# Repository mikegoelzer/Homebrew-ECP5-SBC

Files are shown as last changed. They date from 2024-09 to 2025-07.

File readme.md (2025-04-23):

# Homebrew RISC-V Computer

This is the hardware repo for a homebrew "personal computer" designed from scratch down to the logic gate level.

The computer is based on [my custom RISC-V CPU core](https://github.com/mikegoelzer/riscv) (pipelined, in-order, 5-stage) and has all the common peripherals you'd expect on a PC circa the early-2000s like USB, HDMI, keyboard and mouse, etc.

This repo is focused specifically on the PCBs necessary to build the complete computer.

## Hardware

In this repo, you'll find all the Kicad files and bills of materials needed to construct the entire computer.  There are several PCBs:

- [Compute Module](./hardware/cm/readme.md). This is the heart of the computer:  an FPGA that implements the RISC-V CPU and some SDRAM that serves as the computer's main memory. It has two 100-pin Hirose DF13 snap-in connectors on the bottom, which mate with the motherboard.
- [Motherboard](./hardware/motherboard/readme.md). The Compute Module snaps into this motherboard, which breaks out the common PC periperal interfaces, like HDMI, VGA, JTAG, and more.  It also has an SD card to serve as the computer's "hard drive," a boot flash, and some diagnostic LEDs and switches.
- [Power Supply](./hardware/pd-booster-16amps/readme.md). Power initially comes into the motherboard via a USB-C cable.  Because I wanted to learn a bit about USB Power Deliver (USB-PD) as part of this project, I designed this plug-in board that negotiates higher voltages and currents and then buck-boost converts them to a stable 5V to power the motherboard.
- [Hat](./hardware/hat/readme.md).  This is a top board that sits above the motherboard on standoffs and provides a touch screen plus a smaller OLED display for debugging your Verilog.  The name is, of course, inspired by the Pi HAT, though it bears no electrical or mechanical resemblance.

## About this project

This project was a personal hobby exercise that I pursued on and off over a couple of years.  Everything is massively over-engineered because I was trying to maximize my learnings. 🤷‍♀️

## Acknowledgements

This hardware was heavily inspired by the [ULX3S](https://radiona.org/ulx3s/), which I consider the best low-cost Lattice ECP5 FPGA board ever created.

I also borrowed ideas from several other open-source ECP5 designs:

- [Lattice ECP5 Eval Board](https://www.latticesemi.com/products/developmentboardsandkits/ecp5evaluationboard)
- [Trellis Board](https://github.com/gatecat/TrellisBoard).  Not sure if this was ever sold to the public, but this guy's design is utterly brilliant.
- [Orange Crab](https://github.com/orangecrab-fpga/orangecrab-hardware)

## License

This material is licensed under `CERN-OHL-S v2` (or later), a strong "copyleft" license. If you require more permissive terms or patent protection, please contact the author. A copy of the license can be found in the [LICENSES](./LICENSES) directory.

Copyright © 2025 Mike Goelzer <mike@goelzer.org>

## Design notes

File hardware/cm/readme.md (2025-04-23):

# Compute Module

The Compute Module (CM) is the heart of the computer.  It has the two things that every computer needs:  a processor and memory.  

### Features

- ECP5U 85K FPGA
- 1.1V, 2.5V and 3.3V buck regulators for the FPGA's voltage rails
- Supply sequencer to bring voltage rails up and down "correctly" (see below)
- 16MB DRAM
- 25MHz oscillator
- Bitstream SPI flash chip
- 100-pin Hirose DF13 snap-in connectors on the bottom

### Power

The Compute Module is powered by a 5V input.  The 1.1V and 2.5V and 3.3V rails are produced by three TI buck regulators.

The ECP5 should not require a rail sequencer, but I included one (based on a design borrowed from Trellis Board) because I've seen other ECP5 boards get into weird states that seem like they may be caused by rail ramp rate problems.  Thus, the rail sequencing complies strictly with the ECP5's datasheet, at a cost of two extra chips.

### Electrical and Mechanical Connections

The basic idea with the CM is that you use it by snapping it into some larger board -- in my case, the [the motherboard](../motherboard/readme.md) in this repo.  This is the purpose of the two 100-pin Hirose DF13 male connectors on the bottom of the CM.  Everything, even power andJTAG, is brought out solely through these connectors.

The connectors and overall size and shape were inspired by the Raspberry Pi Compute Module 3 (CM3).  I wasn't able to maintain the same pinout as the Pi CM3 because I needed to bring out more IOs and wanted to run off a 5V input.

### Clock Speed

The FPGA includes several PLLs, so the 25 MHz oscillator in this circuit enables the CPU to run at 100 MHz.  

While the CPU itself would probably run fine at higher clock speeds, the DRAM is rated for a maximum speed of 133 MHz.  The memory controller is simplified considerably when you can get results back from DRAM in one clock cycle, so I just run everything in a single 100 MHz clock domain.

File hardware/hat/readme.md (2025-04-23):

# Hat

This is the top board that sits above the motherboard on standoffs and provides a touch screen plus a smaller OLED display for debugging the CPU's Verilog.

## OLED

The OLED is an 0.95" (96x64) SSD1331 display.  It is controlled via SPI entirely in Verilog.  I use it for very low-level debugging of the CPU itself, e.g., to display a register value or dump the contents of memory.

## Touch Screen

The touch screen is [this cool 2.8" 240x320 TFT LCD from Adafruit](https://www.adafruit.com/product/2090).  It is intended to be under software control rather than at the Verilog level.

## Power

Power is provided by the flat-flexible cable coming from the motherboard.  It is the same 5V supply as the motherboard itself.

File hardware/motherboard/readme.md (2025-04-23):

# Motherboard

This is the motherboard of the computer.  The Compute Module snaps into it to provide the computer's CPU and memory.  The motherboard then provides:

- HDMI
- VGA
- JTAG
- USB debug interface
- PMOD connectors
- Expansion slots for custom PCBs
- FFC connector to connect to the hat board that provides the touch screen
- SD card slot for the computer's "hard drive"
- Boot flash for the FPGA
- 5V power input
- Diagnostic LEDs and switches
- 100-pin Hirose female connectors for the Compute Module to snap into

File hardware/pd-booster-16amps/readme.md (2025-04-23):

# PD Booster (16 amps)

This is a USB-PD power supply that can deliver up to 16 amps at 5V.  It consists of two PCBs, which plug into each other:  a USB-PD controller and a buck-boost converter.

## Theory of Operation

USB-PD is mainly for battery charging, and the idea is that you have a USB-C cable coming into your device from a charger.  The charger initially supplies the standard 5V/2.5A, but you can negotiate over the CC lines side-channel to request both higher current and higher voltages (up to 20V).

Since you don't know in advance what voltage you will get, you need some additional circuitry to step down the voltage whatever you actually want to run at.  In my case, that's 5V.  The buck-boost converter is that additional circuitry:  it will maintain 5V output over the entire range of input voltages from 5V to as high as 20V.

## USB-PD Controller

The first PCB is the USB-PD controller, which is based on [TI TPS25730](https://www.ti.com/lit/ds/symlink/tps25730.pdf?ts=1707773923998&ref_url=https%253A%252F%252Fwww.mouser.at%252F).  It is resistor-strapped to request the highest voltage and current it can get (which would be 20V/5A), but will accept voltages as low as 5V.

## Buck-Boost Converter

The second PCB is the buck-boost converter.  It accepts whatever voltage the USB-PD controller was able to negotiate and regulates it to 5V.

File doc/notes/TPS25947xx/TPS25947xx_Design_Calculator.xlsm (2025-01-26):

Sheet: Calculation Sheet
TPS25947xx Design Calculation Tool
 |  |  |  |  |  |  |  |  |  | Table - 1: Device Comparison Table
 | Constants Cells |  |  |  |  |  |  |  |  | Part number | Overvoltage Response | Overcurrent response | AUXOFF or PG | FLT or PGTH | Response to Thermal Shutdown (TSD) |  | 3.8 | 5.7 | 13.8
 | Input/SelectCells |  |  |  |  |  |  |  |  | TPS259470A | Adjustable OVLO | Active Current Limit | AUXOFF | FLT | Auto-Retry |  | Short | Open | 390
 | Calculation Cells |  |  |  |  |  |  |  |  | TPS259470L | Adjustable OVLO | Active Current Limit | AUXOFF | FLT | Latch-off
 | Calculated, but can be over-ridden by user |  |  |  |  |  |  |  |  | TPS259472A | Pin Selectable OVC (3.8 V/5.7 V/13.8 V) | Active Current Limit | PG | PGTH | Auto-Retry
 | Error Cells, Must be Fixed |  |  |  |  |  |  |  |  | TPS259472L | Pin Selectable OVC(3.8 V/5.7 V/13.8 V) | Active Current Limit | PG | PGTH | Latch-off
 |  |  |  |  |  |  |  |  |  | TPS259474A | Adjustable OVLO | Circuit Breaker | PG | PGTH | Auto-retry
Parameter | Description | Value | Units | Tolerance | Recommended Value |  |  |  |  | TPS259474L | Adjustable OVLO | Circuit Breaker | PG | PGTH | Latch-off
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

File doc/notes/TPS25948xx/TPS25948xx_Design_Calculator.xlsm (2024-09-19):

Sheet: Calculation Sheet
TPS25948xx Design Calculation Tool
 | Constants Cells
 | Input/SelectCells
 | Calculation Cells
 | Calculated, but can be over-ridden by user
 | Error Cells, Must be Fixed
Parameter | Description | Value | Units | Tolerance | Recommended Value
VIN (max) | Maximum Operating input voltage (magnitude) | 12.00 | V
OVLO Set Point | Desired Over Voltage Lockout Set Point | 16.00 | V | 3.0%
UVLO Set Point | Desired Undervoltage Threshold (VIN Rising) | 10.80 | V | 3.0%
VUVP | Internal Undervoltage Protection Threshold (VIN Rising) | 2.53 | V | 3.0%
Cout | Load Capacitance | 220.0 | uF | 10.0%
 | Is there downstream load present other than load cap at startup? | YES
VONTH (CR) (V) | constant resistance load turn on threshold voltage | 0.0 | V
RLOAD (STARTUP) (Ω) | CR load at startup | 2.0 | Ohm
VONTH (CC) (V) | constant current load turn on threshold voltage | 3.0 | V
ILOAD (STARTUP) (A) | CC load at startup | 0.0 | A
VONTH (CP) (V) | constant power load turn on threshold voltage | 8.0 | V
PLOAD (STARTUP) (W) | CP load at startup | 0.0 | W
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

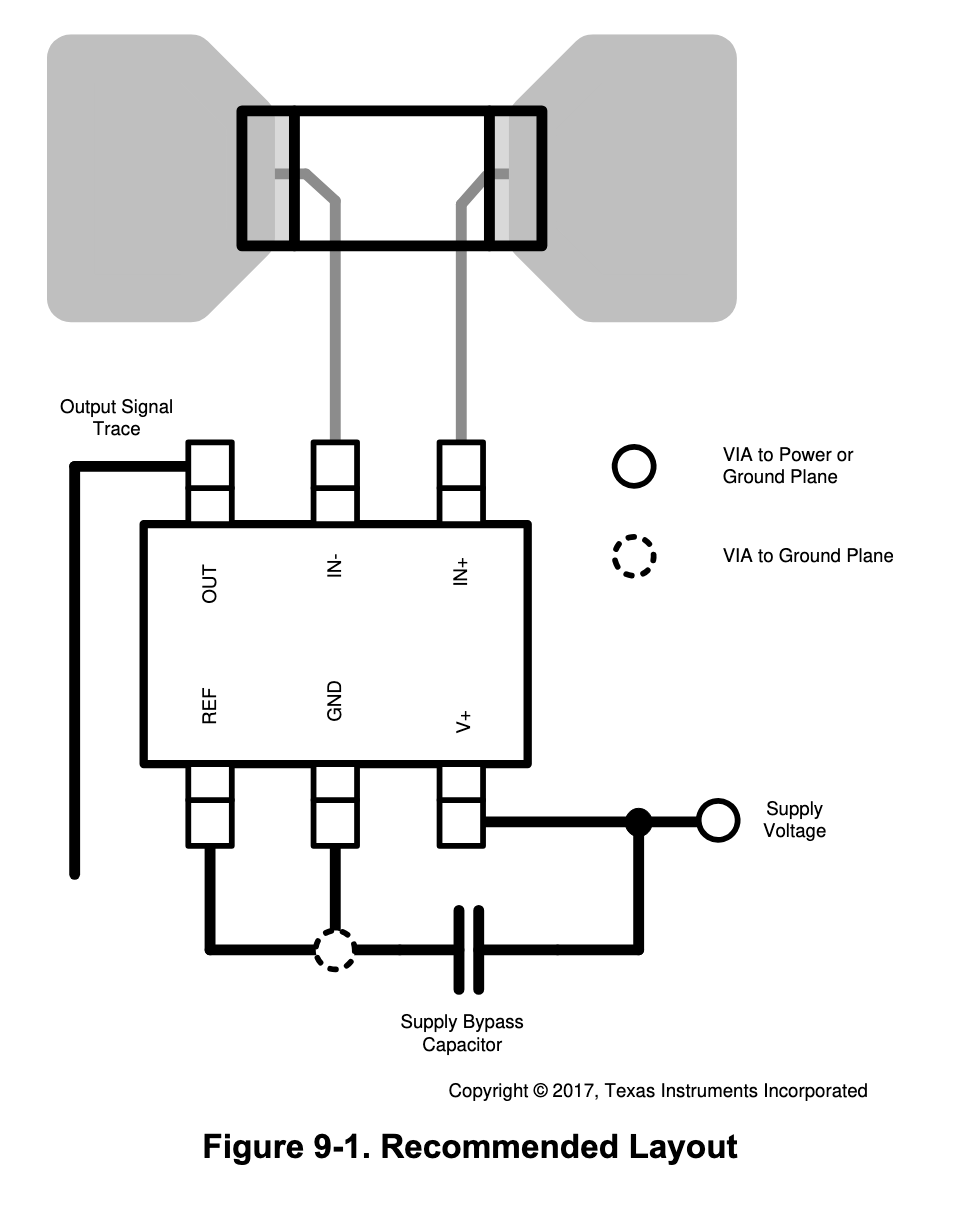
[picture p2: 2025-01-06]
doc/notes/INA211-layout-example.png

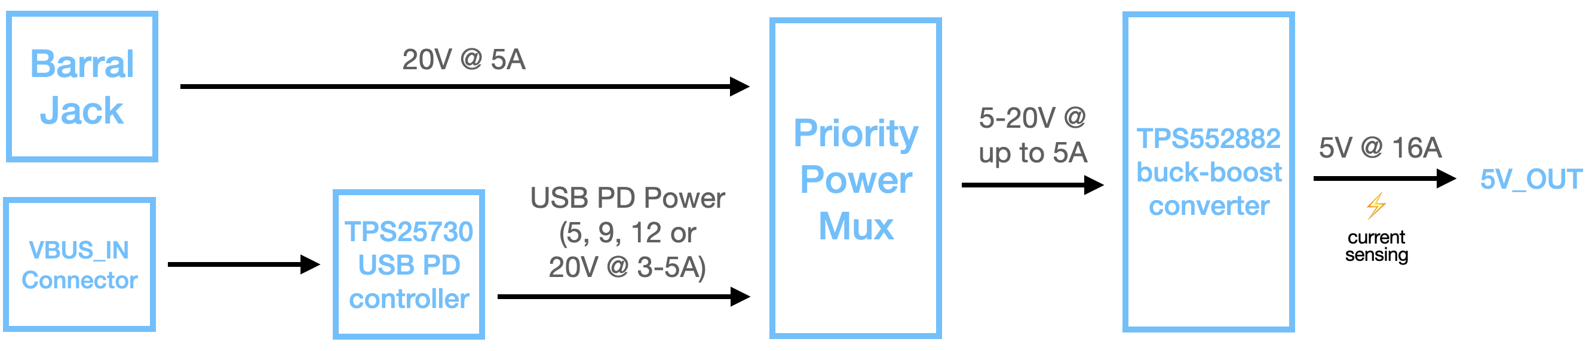
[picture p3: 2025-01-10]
doc/pd-booster-16A_block_diagram.png

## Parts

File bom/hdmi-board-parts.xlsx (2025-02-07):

Desc | Parts | Actual Qty | Order Qty | (Override Qty) | Order Qtr | Price | Subtotal | In basket? | Vendor URL | Mfgr | MPN | Notes
Motherboard for CM Rev 1
# of boards | 2
FT4232H LFQP-64 | U1 | 1 | 2 |  | 2 | $6.35 | $12.70 | ✅ | https://www.digikey.com/en/products/detail/ftdi-future-technology-devices-international-ltd/FT4232HL-REEL/1986055 | FTDI | FT4232HL
EEPROM, 93LC56BT | U2 | 1 | 2 |  | 2 | $0.30 | $0.60 | ✅ | https://www.digikey.com/en/products/detail/microchip-technology/93LC56BT-I-OT/572825 | Microchip Technology | 93LC56BT-I/OT
USB-C receptacle thru-hole GCT USB4105-GF-A-120 | J1 | 1 | 2 |  | 2 | 0.78 | $1.56 | ✅ | https://www.digikey.com/en/products/detail/gct/USB4105-GF-A-120/14559037 | GCT | USB4105-GF-A-120
RES 100 OHM 1% 1/8W 0805 | R30,R31 | 2 | 4 |  | 4 | 0.10 | $0.40 | ✅ | https://www.digikey.com/en/products/detail/yageo/RC0805FR-07100RL/727543 | YAGEO | RC0805FR-07100RL
RES 270 OHM 1% 1/8W 0805 | R32,R33,R34,R35,R36,R37,R38,R39,R40,R51 | 10 | 20 |  | 20 | 0.10 | $2.00 | ✅ | https://www.digikey.com/en/products/detail/yageo/rc0805fr-07270rl/727783 | YAGEO | RC0805FR-07270RL
RES 510 OHM 1% 1/8W 0805 | R55 | 1 | 2 |  | 2 | 0.10 | $0.20 | ✅ | https://www.digikey.com/en/products/detail/yageo/RC0805FR-07510RL/728016 | YAGEO | RC0805FR-07510RL
RES 536 OHM 1% 1/8W 0805 | R15,R16,R17,R18,R19,R20,R21,R22,R23,R24,R25,R26,R27,R28,R29,R42,R44,R50,R52 | 19 | 38 |  | 38 | 0.10 | $3.80 | ✅ | https://www.digikey.com/en/products/detail/yageo/rc0805fr-07536rl/728026 | YAGEO | RC0805FR-07536RL
RES 1K OHM 1% 1/8W 0805 | R43,R56,R57,R60,R63,R64 | 6 | 12 |  | 12 | 0.10 | $1.20 | ✅ | https://www.digikey.com/en/products/detail/yageo/RC0805FR-071KL/727444 | YAGEO | RC0805FR-071KL
RES 3.3K OHM 1% 1/8W 0805 | R53,R54,R58,R59 | 4 | 8 |  | 8 | 0.10 | $0.80 | ✅ | https://www.digikey.com/en/products/detail/yageo/rc0805fr-073k3l/727813 | YAGEO | RC0805FR-073K3L
RES 4.7K OHM 1% 1/8W 0805 |  |  | 0 |  |  | 0.01 | $0.00 |  | https://www.digikey.com/en/products/detail/yageo/rc0805fr-074k7l/727929 | YAGEO | RC0805FR-074K7L
RES 5.1K OHM 1% 1/8W 0805 |  |  | 0 |  |  | 0.10 | $0.00 |  | https://www.digikey.com/en/products/detail/yageo/rc0805fr-075k1l/727988 | YAGEO | RC0805FR-075K1L
RES 2.2K OHM 1% 1/8W 0805 | R45,R48,R49,R46,R68 | 5 | 10 |  | 10 | 0.01 | $0.13 | ✅ | https://www.digikey.com/en/products/detail/yageo/RC0805FR-072K2L/727676 | YAGEO | RC0805FR-072K2L
RES 10K OHM 1% 1/8W 0805 | R61,R62,R66,R67,R69 | 5 | 10 |  | 10 | 0.10 | $1.00 | ✅ | https://www.digikey.com/en/products/detail/yageo/RC0805FR-0710KL/727535 | YAGEO | RC0805FR-0710KL
RES 12K OHM 1% 1/8W 0805 | R65 | 1 | 2 |  | 2 | 0.10 | $0.20 | ✅ | https://www.digikey.com/en/products/detail/yageo/RC0805FR-0712KL/727568 | YAGEO | RC0805FR-0712KL
RES 33K OHM 1% 1/8W 0805 |  |  | 0 |  |  | 0.10 | $0.00 |  | https://www.digikey.com/en/products/detail/yageo/RC0805FR-0733KL/727863 | YAGEO | RC0805FR-0733KL
RES 100K OHM 1% 1/8W 0805 | R1,R2,R3,R4,R5,R6,R7,R8,R9,R10,R11,R12,R13,R14 | 14 | 28 |  | 28 | 0.10 | $2.80 | ✅ | https://www.digikey.com/en/products/detail/yageo/RC0805FR-07100KL/727544 | YAGEO | RC0805FR-07100KL
RES 200K OHM 1% 1/8W 0805 | R47 | 1 | 2 |  | 2 | 0.10 | $0.20 | ✅ | https://www.digikey.com/en/products/detail/yageo/rc0805fr-07200kl/727724 | YAGEO | RC0805FR-07200KL
RES 1M OHM 1% 1/8W 0805 | R41 | 1 | 2 |  | 2 | 0.10 | $0.20 | ✅ | https://www.digikey.com/en/products/detail/yageo/rc0805fr-071ml/727445 | YAGEO | RC0805FR-071ML
Ferrite bead 600 ohms @100mhz 0603 0.6A | FB2,FB3 | 2 | 4 |  | 4 | 0.16 | $0.64 | ✅ | https://www.digikey.com/en/products/detail/murata-electronics/BLM21AG601SN1D/584251 | Murata | BLM21AG601SN1D
FERRITE BEAD 50 OHM @ 100MHZ 1206 1LN 12 AMP 1.6mΩ DCR | FB1 | 1 | 2 |  | 2 | 0.42 | $0.84 | ✅ | https://www.digikey.com/en/products/detail/murata-electronics/BLM31SN500SZ1L/5881255 | Murata | BLM31SN500SZ1L
FERRITE BEAD 600 OHM 0603 1LN | FB4,FB5,FB6 | 3 | 6 |  | 6 | 0.10 | $0.60 | ✅ | https://www.digikey.com/en/products/detail/murata-electronics/blm18rk601sn1d/1948332 | Murata | BLM18RK601SN1D
CAP CER 100PF 50V X7R 0805 | C9 | 1 | 2 |  | 2 | 0.10 | $0.20 | ✅ | https://www.digikey.com/en/products/detail/yageo/CC0805KRX7R9BB101/5884228 | YAGEO | CC0805KRX7R9BB101
CAP CER 1000PF (1 nF) 50V X7R 0805 | C3,C5 | 2 | 4 |  | 4 | 0.10 | $0.40 | ✅ | https://www.digikey.com/en/products/detail/yageo/CC0805KRX7R9BB102/302861 | YAGEO | CC0805KRX7R9BB102
CAP CER 10000PF (10 nF) 50V X7R 0805 | C34,C35,C36,C37,C38,C39,C40,C41 | 8 | 16 |  | 16 | 0.10 | $1.60 | ✅ | https://www.digikey.com/en/products/detail/yageo/CC0805KRX7R9BB103/302870 | YAGEO | CC0805KRX7R9BB103
CAP CER 0.1UF (100 nF) 50V X7R 0805 | C4,C6,C8,C10,C18,C19,C20,C21,C22,C23,C24,C14,C15,C16 | 14 | 28 |  | 28 | 0.08 | $2.24 | ✅ | https://www.digikey.com/en/products/detail/yageo/CC0805KRX7R9BB104/302874 | YAGEO | CC0805KRX7R9BB104
CAP CER 0.47UF (470nF) 25V X7R 0805 | C11 | 1 | 2 |  | 2 | 0.18 | $0.36 | ✅ | https://www.digikey.com/en/products/detail/yageo/CC0805KKX7R8BB474/2103102 | YAGEO | CC0805KKX7R8BB474
CAP CER 4.7UF 25V X5R 0805 |  |  | 0 |  |  | 0.18 | $0.00 |  | https://www.digikey.com/en/products/detail/yageo/CC0805KKX5R8BB475/5195277 | YAGEO | CC0805KKX5R8BB475
CAP CER 4.7UF 35V X5R 0805 | C12,C13 | 2 | 4 |  | 4 | 0.17 | $0.68 | ✅ | https://www.digikey.com/en/products/detail/samsung-electro-mechanics/CL21A475KLCLQNC/5961206 | Samsung | CL21A475KLCLQNC
CAP CER 10UF 25V X5R 0805 | C31,C32,C33,C17,C25,C26 | 6 | 12 |  | 12 | 0.33 | $3.96 | ✅ | https://www.digikey.com/en/products/detail/yageo/CC0805KKX5R8BB106/5195275 | YAGEO | CC0805KKX5R8BB106
CAP CER 22UF 35V X5R 0805 | C1,C2 | 2 | 4 |  | 4 | $0.97 | $3.88 | ✅ | https://www.digikey.com/en/products/detail/tdk-corporation/C2012X5R1V226M125DC/22106206 | TDK Corporation | C2012X5R1V226M125DC
CAP CER 1000PF (1nF) 250V X7R 0805 | C7 | 1 | 2 |  | 2 | $0.10 | $0.20 | ✅ | https://www.digikey.com/en/products/detail/samsung-electro-mechanics/CL21B102KECSFNC/3888089 | Samsung | CL21B102KECSFNC
USBLC6-2SC6 TVS diode | D1 | 1 | 2 |  | 2 | 0.36 | $0.72 | ✅ | https://www.digikey.com/en/products/detail/stmicroelectronics/USBLC6-2SC6/1040559 | STMicroelectronics | USBLC6-2SC6
2x4 female 0.1" socket | J2 | 1 | 2 |  | 2 | 0.44 | $0.88 | ✅ | https://www.digikey.com/en/products/detail/adam-tech/RS2-08-G/9832057 | Adam Tech | RS2-08-G
TFP401 HDMI receiver |  |  | 0 |  |  | $8.26 | $0.00 |  | https://www.digikey.com/en/products/detail/texas-instruments/TFP401PZP/380153 | TI | TFP401PZP
TFP410 HDMI transmitter | U5 | 1 | 2 |  | 2 | $8.44 | $16.88 | ✅ | https://www.digikey.com/en/products/detail/texas-instruments/TFP410PAP/454241 | TI | TFP410PAP
CONN RCPT HDMI V2.1 19POS SMD RA | J4 | 1 | 2 |  | 2 | $2.14 | $4.28 | ✅ | https://www.digikey.com/en/products/detail/molex/2086581001/10493711 | Molex | 2086581001
D-SUB receptacle female pins | J5 | 1 | 2 |  | 2 | $1.45 | $2.90 | ✅ | https://www.digikey.com/en/products/detail/amphenol-cs-fci/ICD15S13E4GX00LF/1536501 | Amphenol | ICD15S13E4GX00LF
74LVC245 | U6,U7 | 2 | 4 |  | 4 | $0.53 | $2.12 | ✅ | https://www.digikey.com/en/products/detail/texas-instruments/SN74ALVC245PWR/381176 | TI | SN74ALVC245PWR
HDMI I2C level shifter PCA9306D in SO-8 | U9 | 1 | 2 |  | 2 | $0.74 | $1.48 | ✅ | https://www.digikey.com/en/products/detail/nxp-usa-inc/PCA9306D-118/1300968 | NXP USA Inc. | PCA9306D,118
Hirose DF40GB (with shield) 48-pin socket/receptacle/female, 3.0mm stack | XM1 | 1 | 2 |  | 2 | $1.20 | $2.40 | ✅ | https://www.digikey.com/en/products/detail/hirose-electric-co-ltd/DF40GB-3-0-48DS-0-4V-51/5052265 | Hirose | DF40GB(3.0)-48DS-0.4V(51)
Hirose DF40HC 40-pin socket/receptacle/female, 3.5mm stack | XM2 | 1 | 2 |  | 2 | $0.81 | $1.62 | ✅ | https://www.digikey.com/en/products/detail/hirose-electric-co-ltd/DF40HC-3-5-20DS-0-4V-51/5132167 | Hirose | DF40HC(3.5)-20DS-0.4V(51)
4 x M2.5x0.45 screws 10mm long | XM1,XM2 | 2 | 4 | 4 | 4 | $0.13 | $0.52 | ✅ | https://www.digikey.com/en/products/detail/essentra-components/50M025045P010/11639705 | Essentra | 50M025045P010 | Intended (10mm) screw for XM1 at Ux
8 x M2.5 washer, 1.5mm thick | XM1,XM2 | 2 | 4 | 8 | 8 | $0.10 | $0.80 | ✅ | https://www.digikey.com/en/products/detail/essentra-components/015102500203/4104105 | Essentra | 015102500203 | Double them up on each hole for 3mm standoff height
2 x Hirose DF40 (w/o shield) 100-pin socket/receptacle/female, 1.5mm stack | U3 | 1 | 2 | 6 | 6 | $1.76 | $10.56 | ✅ | https://www.digikey.com/en/products/detail/hirose-electric-co-ltd/df40c-100ds-0-4v-51/1969476 | Hirose | DF40C-100DS-0.4V(51)
4 x M2.5x0.45 screws 8.5mm long | U3 | 1 | 2 | 4 | 4 | $0.13 | $0.52 | ✅ | https://www.digikey.com/en/products/detail/essentra-components/50M025045I010/11641118 | Essentra | 50M025045I010 | Alternate (shorter, 8.5mm) screw for GCM at U3
4 x M2.5x0.45 screws 10mm long | U3 | 1 | 2 | 4 | 4 | $0.13 | $0.52 | ✅ | https://www.digikey.com/en/products/detail/essentra-components/50M025045P010/11639705 | Essentra | 50M025045P010 | Intended (10mm) screw for GCM at U3
4 x M2 washer, 1.5mm thick | U3 | 1 | 2 | 4 | 4 | $0.30 | $1.20 | ✅ | https://www.digikey.com/en/products/detail/essentra-components/rwm050a/4105754 | Essentra | RWM050A | Alternate (M2) washer for GCM at U3
4 x M2.5 washer, 1.5mm thick | U3 | 1 | 2 | 4 | 4 | $0.10 | $0.40 | ✅ | https://www.digikey.com/en/products/detail/essentra-components/015102500203/4104105 | Essentra | 015102500203 | Intended (M2.5) washer for GCM at U3
4 x M2.5 nut | U3,XM1,XM2 | 3 | 6 | 12 | 12 | $0.13 | $1.56 | ✅ | https://www.digikey.com/en/products/detail/essentra-components/04M025045HN/9677099 | Essentra | 04M025045HN | Covers just U3 (4 nuts) and XM1 (4 nuts)
4 x M3 standoffs, 80mm | (top PCB attachment) | 1 | 2 | 4 | 4 | $1.41 | $5.64 | ✅ | https://www.digikey.com/en/products/detail/w%C3%BCrth-elektronik/970800321/6174900 | Wurth | 970800321
8 x M3 screws (4 x from top, 4x from bottom) | (top PCB attachment) | 1 | 2 | 8 | 8 | $0.24 | $1.92 | ✅ | https://www.digikey.com/en/products/detail/w%C3%BCrth-elektronik/97790603111/10056387 | Wurth | 97790603111
FFC connector (Hirose FH12 vertical 32-pos for 0.3mm thick) | J3 | 1 | 2 |  | 2 | $2.14 | $4.28 | ✅ | https://www.digikey.com/en/products/detail/hirose-electric-co-ltd/FH12-32S-0-5SVA-54/4283323 | Hirose | FH12-32S-0.5SVA(54)
32 Position FFC, FPC Cable 0.020" (0.50mm) 5.000" (127.00mm) 0.3mm thick | J3 | 1 | 2 | 1 | 1 | $4.00 | $4.00 | ✅ | https://www.digikey.com/en/products/detail/molex/0982660346/3469471 | Molex | 0982660346
5.1k through-hole resistor (for backup at J2) | J2 | 1 | 2 | 2 | 2 | $0.10 | $0.20 | ✅ | https://www.digikey.com/en/products/detail/stackpole-electronics-inc/CF14JT5K10/1741447 | Stackpole | CF14JT5K10 | Backup in case pd-booster null board not available; short b/t CC1 & GND and CC2 & GND
CONN HEADER R/A 2x6 2.54MM | J7 | 1 | 2 |  | 2 | $0.27 | $0.54 | ✅ | https://www.digikey.com/en/products/detail/adam-tech/PH2RA-12-UA/9830569 | Adam Tech | PH2RA-12-UA
CONN HEADER R/A 1x6 2.54MM | J6 | 1 | 2 |  | 2 | $0.16 | $0.32 | ✅ | https://www.digikey.com/en/products/detail/adam-tech/ph1rb-06-ua/9830592 | Adam Tech | PH1RB-06-UA
Tactile momentary push button C&K PTS645 | S1,S2,S3,S4 | 4 | 8 | 12 | 12 | $0.40 | $4.80 | ✅ | https://www.digikey.com/en/products/detail/c-k/PTS645SL50SMTR92-LFS/1279107 | C&K | PTS645SL50SMTR92LFS
Green LED 0805 | D2,D8,D10 | 3 | 6 |  | 6 | $0.17 | $1.02 | ✅ | https://www.digikey.com/en/products/detail/w%C3%BCrth-elektronik/150080VS75000/4489924 | Wurth | 150080VS75000
Amber LED 0805 | D6 | 1 | 2 |  | 2 | $0.22 | $0.44 | ✅ | https://www.digikey.com/en/products/detail/w%C3%BCrth-elektronik/150080AS75000/11479384 | Wurth | 150080AS75000
Red LED 0805 | D4 | 1 | 2 |  | 2 | $0.17 | $0.34 | ✅ | https://www.digikey.com/en/products/detail/w%C3%BCrth-elektronik/150080SS75000/4489921 | Wurth | 150080SS75000
Blue LED 0805 | D5 | 1 | 2 |  | 2 | $0.17 | $0.34 | ✅ | https://www.digikey.com/en/products/detail/w%C3%BCrth-elektronik/150080BS75000/4489912 | Wurth | 150080BS75000
Yellow LED 0805 | D3,D9 | 2 | 4 |  | 4 | $0.17 | $0.68 | ✅ | https://www.digikey.com/en/products/detail/w%C3%BCrth-elektronik/150080YS75000/4489927 | Wurth | 150080YS75000
White LED 0805 (Vf 3.1V at 5ma; use 68.1Ω resistor for 3.3V supply) | D7 | 1 | 2 |  | 2 | $0.43 | $0.86 | ✅ | https://www.digikey.com/en/products/detail/qt-brightek-qtb/QBLP631-IW5/16499651 | QT Brightek | QBLP631-IW5
TMUX1574PWR | U8,U10 | 2 | 4 |  | 4 | $0.54 | $2.16 | ✅ | https://www.digikey.com/en/products/detail/texas-instruments/TMUX1574PWR/9954224 | TI | TMUX1574PWR
128Mb QSPI serial flash | U4 | 1 | 2 |  | 2 | $0.00 | $0.00 | ✅ | https://www.digikey.com/en/products/detail/winbond-electronics/w25q128jvsiq/5803943 | Winbond | W25Q128JVSIQ
12mhz oscillator | Y1 | 1 | 2 |  | 2 | $2.38 | $4.76 | ✅ | https://www.digikey.com/en/products/detail/abracon-llc/ASEM1-12-000MHZ-LC-T/1873203 | Abracon | ASEM1-12.000MHZ-LC-T
0.1" male pins, straight, 2x2 |  |  | 0 |  |  | $0.10 | $0.00 |  | https://www.digikey.com/en/products/detail/adam-tech/PH2-04-UA/9830324 | Adam Tech | PH2-04-UA
0.1" male pins, straight, 2x3 | J8 | 1 | 2 |  | 2 | $0.10 | $0.20 | ✅ | https://www.digikey.com/en/products/detail/adam-tech/PH2-06-UA/9830396 | Adam Tech | PH2-06-UA
0.1" male pins, straight, 1x3 | J9 | 1 | 2 |  | 2 | $0.10 | $0.20 | ✅ | https://www.digikey.com/en/products/detail/adam-tech/PH1-03-UA/9830289 | Adam Tech | PH1-03-UA
Keystone Testpoint (red) |  |  | 0 |  |  | $0.41 | $0.00 |  | https://www.digikey.com/en/products/detail/keystone-electronics/5000/255326 | Keystone | 5000
Keystone Testpoint (black) |  |  | 0 |  |  | $0.41 | $0.00 |  | https://www.digikey.com/en/products/detail/keystone-electronics/5001/255327 | Keystone | 5001
Keystone Testpoint (while) |  |  | 0 |  |  | $0.41 | $0.00 |  | https://www.digikey.com/en/products/detail/keystone-electronics/5002/255328 | Keystone | 5002
Keystone Testpoint (orange) |  |  | 0 |  |  | $0.41 | $0.00 |  | https://www.digikey.com/en/products/detail/keystone-electronics/5003/362668 | Keystone | 5003
Keystone Testpoint (yellow) |  |  | 0 |  |  | $0.41 | $0.00 |  | https://www.digikey.com/en/products/detail/keystone-electronics/5004/362669 | Keystone | 5004
IC PWR SWITCH N-CHAN 1:1 SOT23-5 (current limiting load switch) in SOT-23-5 | U11 | 1 | 2 |  | 2 | $0.00 | $0.00 | ✅ | https://www.digikey.com/en/products/detail/texas-instruments/TPS2041BDBVR/1219920 | TI | TPS2041BDBVR
TVS diode TPD4E02B04 | U12, U13 | 2 | 4 |  | 4 | $0.00 | $0.00 | ✅ | https://www.digikey.com/en/products/detail/texas-instruments/TPD4E02B04DQAR/5880125 | TI | TPD4E02B04
xm-dvi-in Expansion Module
# of boards | 2
FT4232H LFQP-64 |  |  | 0 |  |  | $6.35 | $0.00 | ❌ | https://www.digikey.com/en/products/detail/ftdi-future-technology-devices-international-ltd/FT4232HL-REEL/1986055 | FTDI | FT4232HL
EEPROM, 93LC56BT |  |  | 0 |  |  | $0.30 | $0.00 | ❌ | https://www.digikey.com/en/products/detail/microchip-technology/93LC56BT-I-OT/572825 | Microchip Technology | 93LC56BT-I/OT
USB-C receptacle thru-hole GCT USB4105-GF-A-120 |  |  | 0 |  |  | 0.78 | $0.00 | ❌ | https://www.digikey.com/en/products/detail/gct/USB4105-GF-A-120/14559037 | GCT | USB4105-GF-A-120
RES 100 OHM 1% 1/8W 0805 |  |  | 0 |  |  | 0.10 | $0.00 | ❌ | https://www.digikey.com/en/products/detail/yageo/RC0805FR-07100RL/727543 | YAGEO | RC0805FR-07100RL
RES 270 OHM 1% 1/8W 0805 |  |  | 0 |  |  | 0.10 | $0.00 | ❌ | https://www.digikey.com/en/products/detail/yageo/rc0805fr-07270rl/727783 | YAGEO | RC0805FR-07270RL
RES 510 OHM 1% 1/8W 0805 |  |  | 0 |  |  | 0.10 | $0.00 | ❌ | https://www.digikey.com/en/products/detail/yageo/RC0805FR-07510RL/728016 | YAGEO | RC0805FR-07510RL
RES 536 OHM 1% 1/8W 0805 |  |  | 0 |  |  | 0.10 | $0.00 | ❌ | https://www.digikey.com/en/products/detail/yageo/rc0805fr-07536rl/728026 | YAGEO | RC0805FR-07536RL
RES 1K OHM 1% 1/8W 0805 |  |  | 0 |  |  | 0.10 | $0.00 | ❌ | https://www.digikey.com/en/products/detail/yageo/RC0805FR-071KL/727444 | YAGEO | RC0805FR-071KL
RES 4.7K OHM 1% 1/8W 0805 |  |  | 0 |  |  | 0.01 | $0.00 | ❌ | https://www.digikey.com/en/products/detail/yageo/rc0805fr-074k7l/727929 | YAGEO | RC0805FR-074K7L
RES 5.1K OHM 1% 1/8W 0805 |  |  | 0 |  |  | 0.10 | $0.00 | ❌ | https://www.digikey.com/en/products/detail/yageo/rc0805fr-075k1l/727988 | YAGEO | RC0805FR-075K1L
RES 2.2K OHM 1% 1/8W 0805 | R42,R43,R50,R51 | 4 | 8 |  | 8 | 0.01 | $0.11 | ❌ | https://www.digikey.com/en/products/detail/yageo/RC0805FR-072K2L/727676 | YAGEO | RC0805FR-072K2L
RES 10K OHM 1% 1/8W 0805 | R53 | 1 | 2 |  | 2 | 0.10 | $0.20 | ❌ | https://www.digikey.com/en/products/detail/yageo/RC0805FR-0710KL/727535 | YAGEO | RC0805FR-0710KL
RES 12K OHM 1% 1/8W 0805 |  |  | 0 |  |  | 0.10 | $0.00 | ❌ | https://www.digikey.com/en/products/detail/yageo/RC0805FR-0712KL/727568 | YAGEO | RC0805FR-0712KL
RES 33K OHM 1% 1/8W 0805 | R52,R54 | 2 | 4 |  | 4 | 0.10 | $0.40 | ❌ | https://www.digikey.com/en/products/detail/yageo/RC0805FR-0733KL/727863 | YAGEO | RC0805FR-0733KL
RES 100K OHM 1% 1/8W 0805 |  |  | 0 |  |  | 0.10 | $0.00 | ❌ | https://www.digikey.com/en/products/detail/yageo/RC0805FR-07100KL/727544 | YAGEO | RC0805FR-07100KL
RES 200K OHM 1% 1/8W 0805 | R44 | 1 | 2 |  | 2 | 0.10 | $0.20 | ❌ | https://www.digikey.com/en/products/detail/yageo/rc0805fr-07200kl/727724 | YAGEO | RC0805FR-07200KL
RES 1M OHM 1% 1/8W 0805 |  |  | 0 |  |  | 0.10 | $0.00 | ❌ | https://www.digikey.com/en/products/detail/yageo/rc0805fr-071ml/727445 | YAGEO | RC0805FR-071ML
Ferrite bead 600 ohms @100mhz 0603 0.6A |  |  | 0 |  |  | 0.16 | $0.00 | ❌ | https://www.digikey.com/en/products/detail/murata-electronics/BLM21AG601SN1D/584251 | Murata | BLM21AG601SN1D
FERRITE BEAD 50 OHM @ 100MHZ 1206 1LN 12 AMP 1.6mΩ DCR |  |  | 0 |  |  | 0.42 | $0.00 | ❌ | https://www.digikey.com/en/products/detail/murata-electronics/BLM31SN500SZ1L/5881255 | Murata | BLM31SN500SZ1L
FERRITE BEAD 600 OHM 0603 1LN | FB2,FB3,FB4,FB5 | 4 | 8 |  | 8 | 0.10 | $0.80 | ❌ | https://www.digikey.com/en/products/detail/murata-electronics/blm18rk601sn1d/1948332 | Murata | BLM18RK601SN1D
CAP CER 100PF 50V X7R 0805 | C8 | 1 | 2 |  | 2 | 0.10 | $0.20 | ❌ | https://www.digikey.com/en/products/detail/yageo/CC0805KRX7R9BB101/5884228 | YAGEO | CC0805KRX7R9BB101
CAP CER 1000PF (1 nF) 50V X7R 0805 |  |  | 0 |  |  | 0.10 | $0.00 | ❌ | https://www.digikey.com/en/products/detail/yageo/CC0805KRX7R9BB102/302861 | YAGEO | CC0805KRX7R9BB102
CAP CER 10000PF (10 nF) 50V X7R 0805 | C16,C17,C18,C19,C20,C21,C22,C23,C24,C25,C26,C27,C28,C29,C30 | 15 | 30 |  | 30 | 0.10 | $3.00 | ❌ | https://www.digikey.com/en/products/detail/yageo/CC0805KRX7R9BB103/302870 | YAGEO | CC0805KRX7R9BB103
CAP CER 0.1UF (100 nF) 50V X7R 0805 |  |  | 0 |  |  | 0.08 | $0.00 | ❌ | https://www.digikey.com/en/products/detail/yageo/CC0805KRX7R9BB104/302874 | YAGEO | CC0805KRX7R9BB104
CAP CER 0.47UF (470nF) 25V X7R 0805 | C10 | 1 | 2 |  | 2 | 0.18 | $0.36 | ❌ | https://www.digikey.com/en/products/detail/yageo/CC0805KKX7R8BB474/2103102 | YAGEO | CC0805KKX7R8BB474
CAP CER 4.7UF 25V X5R 0805 |  |  | 0 |  |  | 0.18 | $0.00 | ❌ | https://www.digikey.com/en/products/detail/yageo/CC0805KKX5R8BB475/5195277 | YAGEO | CC0805KKX5R8BB475
CAP CER 10UF 25V X5R 0805 | C12,C13,C14,C15 | 4 | 8 |  | 8 | 0.33 | $2.64 | ❌ | https://www.digikey.com/en/products/detail/yageo/CC0805KKX5R8BB106/5195275 | YAGEO | CC0805KKX5R8BB106
CAP CER 22UF 35V X5R 0805 |  |  | 0 |  |  | $0.97 | $0.00 | ❌ | https://www.digikey.com/en/products/detail/tdk-corporation/C2012X5R1V226M125DC/22106206 | TDK Corporation | C2012X5R1V226M125DC
CAP CER 1000PF (1nF) 250V X7R 0805 |  |  | 0 |  |  | $0.10 | $0.00 | ❌ | https://www.digikey.com/en/products/detail/samsung-electro-mechanics/CL21B102KECSFNC/3888089 | Samsung | CL21B102KECSFNC
USBLC6-2SC6 TVS diode |  |  | 0 |  |  | 0.36 | $0.00 | ❌ | https://www.digikey.com/en/products/detail/stmicroelectronics/USBLC6-2SC6/1040559 | STMicroelectronics | USBLC6-2SC6
2x4 female 0.1" socket |  |  | 0 |  |  | 0.44 | $0.00 | ❌ | https://www.digikey.com/en/products/detail/adam-tech/RS2-08-G/9832057 | Adam Tech | RS2-08-G
TFP401 HDMI receiver | U4 | 1 | 2 |  | 2 | $8.26 | $16.52 | ❌ | https://www.digikey.com/en/products/detail/texas-instruments/TFP401PZP/380153 | TI | TFP401PZP
TFP410 HDMI transmitter |  |  | 0 |  |  | $8.44 | $0.00 | ❌ | https://www.digikey.com/en/products/detail/texas-instruments/TFP410PAP/454241 | TI | TFP410PAP
CONN RCPT HDMI V2.1 19POS SMD RA | J3 | 1 | 2 |  | 2 | $2.14 | $4.28 | ❌ | https://www.digikey.com/en/products/detail/molex/2086581001/10493711 | Molex | 2086581001
D-SUB receptacle female pins |  |  | 0 |  |  | $1.45 | $0.00 | ❌ | https://www.digikey.com/en/products/detail/amphenol-cs-fci/ICD15S13E4GX00LF/1536501 | Amphenol | ICD15S13E4GX00LF
74LVC245 |  |  | 0 |  |  | $0.53 | $0.00 | ❌ | https://www.digikey.com/en/products/detail/texas-instruments/SN74ALVC245PWR/381176 | TI | SN74ALVC245PWR
HDMI I2C level shifter PCA9306D in SO-8 | U8 | 1 | 2 |  | 2 | $0.74 | $1.48 | ❌ | https://www.digikey.com/en/products/detail/nxp-usa-inc/PCA9306D-118/1300968 | NXP USA Inc. | PCA9306D,118
Hirose DF40GB (with shield) 48-pin plug/male | J1 | 1 | 2 |  | 2 | $1.26 | $2.52 | ❌ | https://www.digikey.com/en/products/detail/hirose-electric-co-ltd/DF40GB-48DP-0-4V-51/5052268 | Hirose | DF40GB-48DP-0.4V(51)
 |  |  | 0 |  |  | $0.00 | $0.00 | ❌
 |  |  | 0 |  |  | $0.00 | $0.00 | ❌
 |  |  | 0 |  |  | $0.00 | $0.00 | ❌
 |  |  | 0 |  |  | $0.00 | $0.00 | ❌
 |  |  | 0 |  |  | $0.00 | $0.00 | ❌
 |  |  | 0 |  |  | $0.00 | $0.00 | ❌
 |  |  | 0 |  |  | $0.00 | $0.00 | ❌
 |  |  | 0 |  |  | $0.00 | $0.00 | ❌
 |  |  | 0 |  |  | $0.00 | $0.00 | ❌
 |  |  | 0 |  |  | $0.00 | $0.00 | ❌
 |  |  | 0 |  |  | $0.00 | $0.00 | ❌
 |  |  | 0 |  |  | $0.00 | $0.00 | ❌
 |  |  | 0 |  |  | $0.00 | $0.00 | ❌
 |  |  | 0 |  |  | $0.00 | $0.00 | ❌
 |  |  | 0 |  |  | $0.00 | $0.00 | ❌
 |  |  | 0 |  |  | $0.00 | $0.00 | ❌
 |  |  | 0 |  |  | $0.00 | $0.00 | ❌
pd-booster-null Current (Non-)Booster Board Rev 1
# of boards | 2
IC CURR SENSE 1 CIRCUIT SC70-6 | U1 | 1 | 2 |  | 2 | 1.46 | $2.92 | ✅ | https://www.digikey.com/en/products/detail/texas-instruments/INA211BIDCKT/3675147 | TI | INA211BIDCKT
Shunt resistor 0.002 OHM 1% 1W 1206 | R3 | 1 | 2 |  | 2 | 0.96 | $1.92 | ✅ | https://www.digikey.com/en/products/detail/stackpole-electronics-inc/CSNL1206FT2L00/1788091 | Stackpole Electronics Inc | CSNL1206FT2L00
RES 5.1K OHM 1% 1/8W 0805 | R1,R2 | 2 | 4 |  | 4 | 0.10 | $0.40 | ✅ | https://www.digikey.com/en/products/detail/yageo/rc0805fr-075k1l/727988 | YAGEO | RC0805FR-075K1L
CAP CER 0.1UF 50V X7R 0805 | C1 | 1 | 2 |  | 2 | 0.08 | $0.16 | ✅ | https://www.digikey.com/en/products/detail/yageo/CC0805KRX7R9BB104/302874 | YAGEO | CC0805KRX7R9BB104
2x4 male pin header 0.1" right angle | J1 | 1 | 2 |  | 2 | 0.08 | $0.16 | ✅ | https://www.digikey.com/en/products/detail/adam-tech/PH2RA-08-UA/9830984 | Adam Tech | PH2RA-08-UA
1x2 male pin header 0.1" right angle | J2 | 1 | 2 |  | 2 | 0.08 | $0.16 | ✅ | https://www.digikey.com/en/products/detail/adam-tech/PH1RB-02-UA/9830333 | Adam Tech | PH1RB-02-UA
pd-booster-16amps Current Booster Board Rev 1
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

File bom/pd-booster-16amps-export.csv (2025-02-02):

Reference | Value | Datasheet | Footprint | Qty | DNP
C3 | 0.1uF | https://www.yageo.com/upload/media/product/productsearch/datasheet/mlcc/UPY-GPHC_X7R_6.3V-to-250V_24.pdf | Capacitor_SMD:C_0805_2012Metric_Pad1.18x1.45mm_HandSolder | 1
C4 | 22uF/35V | https://product.tdk.com/system/files/dam/doc/product/capacitor/ceramic/mlcc/catalog/mlcc_commercial_general_en.pdf | Capacitor_SMD:C_0805_2012Metric_Pad1.18x1.45mm_HandSolder | 1
C5,C6,C7,C9 | 10uF/50V | https://search.murata.co.jp/Ceramy/image/img/A01X/G101/ENG/GRM21BR61H106KE43-01A.pdf | Capacitor_SMD:C_0805_2012Metric_Pad1.18x1.45mm_HandSolder | 4
C8,C10,C11,C12 | 10nF/50V | https://search.kemet.com/download/datasheet/C0805C103K5RAC7800 | Capacitor_SMD:C_0805_2012Metric_Pad1.18x1.45mm_HandSolder | 4
C13,C14 | 4.7uF/35V | https://mm.digikey.com/Volume0/opasdata/d220001/medias/docus/43/CL21A475KLCLQNC_Spec.pdf | Capacitor_SMD:C_0805_2012Metric_Pad1.18x1.45mm_HandSolder | 2
C15,C16 | 330pF/50V | https://www.yageo.com/upload/media/product/productsearch/datasheet/mlcc/UPY-GPHC_X7R_6.3V-to-250V_24.pdf | Capacitor_SMD:C_0805_2012Metric_Pad1.18x1.45mm_HandSolder | 2
C17 | 330uF | https://industrial.panasonic.com/ww/products/pt/os-con/models/25SVPF330M | 25SVPF330M:CAP_25SVPF330M | 1
C18,C19 | 6.8uF | https://product.tdk.com/system/files/dam/doc/product/capacitor/ceramic/mlcc/catalog/mlcc_automotive_general_en.pdf | Capacitor_SMD:C_1812_4532Metric_Pad1.57x3.40mm_HandSolder | 2
C20,C21 | 100nF | https://search.kemet.com/download/datasheet/C0603C104M4RAC7867 | Capacitor_SMD:C_0603_1608Metric_Pad1.08x0.95mm_HandSolder | 2
C22,C23,C24 | 100uF | https://product.tdk.com/system/files/dam/doc/product/capacitor/ceramic/mlcc/catalog/mlcc_commercial_general_en.pdf | Capacitor_SMD:C_1206_3216Metric_Pad1.33x1.80mm_HandSolder | 3
C25 | 560uF | https://industrial.panasonic.com/ww/products/pt/os-con/models/16SVPF560M | 16SVPF560M:CAP_16SVPF560M | 1
C26 | 4.7uF | https://product.tdk.com/system/files/dam/doc/product/capacitor/ceramic/mlcc/catalog/mlcc_commercial_general_en.pdf | Capacitor_SMD:C_0603_1608Metric_Pad1.08x0.95mm_HandSolder | 1
C29,C30 | 15nF | https://search.murata.co.jp/Ceramy/image/img/A01X/G101/ENG/GRM155R71E153KA61-01.pdf | Capacitor_SMD:C_0402_1005Metric_Pad0.74x0.62mm_HandSolder | 2
C31,C32 | 10pF | https://search.murata.co.jp/Ceramy/image/img/A01X/G101/ENG/GRM1885C1H100JA01-01.pdf | Capacitor_SMD:C_0603_1608Metric_Pad1.08x0.95mm_HandSolder | 2
C39,C40 | 1uF | -- mixed values -- | Capacitor_SMD:C_0603_1608Metric_Pad1.08x0.95mm_HandSolder | 2
D2 | Red | https://www.we-online.com/components/products/datasheet/150080SS75000.pdf | LED_SMD:LED_0805_2012Metric_Pad1.15x1.40mm_HandSolder | 1
D3 | Yellow | https://www.we-online.com/components/products/datasheet/150080YS75000.pdf | LED_SMD:LED_0805_2012Metric_Pad1.15x1.40mm_HandSolder | 1
D4 | Amber | https://www.we-online.com/components/products/datasheet/150080AS75000.pdf | LED_SMD:LED_0805_2012Metric_Pad1.15x1.40mm_HandSolder | 1
D5,D6 | Green | -- mixed values -- | LED_SMD:LED_0805_2012Metric_Pad1.15x1.40mm_HandSolder | 2
J2 | 2x4 male 0.1" | ~ | Connector_PinHeader_2.54mm:PinHeader_2x04_P2.54mm_Vertical | 1
J3,J5 | PH1-02-UA | https://app.adam-tech.com/products/download/data_sheet/201605/ph1-xx-ua-data-sheet.pdf | Connector_PinHeader_2.54mm:PinHeader_2x01_P2.54mm_Vertical | 2
J6 | female (front board) | https://mm.digikey.com/Volume0/opasdata/d220001/medias/docus/937/Female_Headers.100_DS.pdf | Connector_PinHeader_2.54mm:PinHeader_2x08_P2.54mm_Vertical | 1
J7 | male pins 16mm (back board) | https://www.hirose.com/product/document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 | Connector_PinHeader_2.54mm:PinHeader_2x08_P2.54mm_Vertical | 1
L1 | 6.8uH | https://www.vishay.com/docs/34306/ihlp-6767dz-11.pdf | IHLP6767DZER6R8M11:IND_IHLP-6767DZ_VIS-M | 1
MB1 | PCB mouse bites |  | Mousebites:mouse-bite-2.54mm-slot | 1
Q1,Q2 | CSD16327Q3 | https://www.ti.com/general/docs/suppproductinfo.tsp?distId=10 | CSD16327Q3:TRANS_CSD16327Q3 | 2
Q3,Q4,Q5,Q6 | BSH111 | https://assets.nexperia.com/documents/data-sheet/BSH111BK.pdf | PCM_Package_TO_SOT_SMD_AKL:SOT-23 | 4
Q7 | BSS84 (PMOS) | https://www.onsemi.com/pdf/datasheet/bss84-d.pdf | Package_TO_SOT_SMD:SOT-23-3 | 1
R3 | 2mΩ 1% 1W | https://www.seielect.com/catalog/sei-csnl.pdf | CSNL1206FT2L00:STA_CSNL1206_STP | 1
R4,R5,R6,R9 | 10k | https://www.yageo.com/upload/media/product/products/datasheet/rchip/PYu-RC_Group_51_RoHS_L_12.pdf | PCM_Resistor_SMD_AKL:R_0805_2012Metric_Pad1.15x1.40mm_HandSolder | 4
R7,R8 | 3.3k | https://www.yageo.com/upload/media/product/products/datasheet/rchip/PYu-RC_Group_51_RoHS_L_12.pdf | PCM_Resistor_SMD_AKL:R_0805_2012Metric_Pad1.15x1.40mm_HandSolder | 2
R10,R11,R12,R13 | 33k | https://www.yageo.com/upload/media/product/products/datasheet/rchip/PYu-RC_Group_51_RoHS_L_12.pdf | PCM_Resistor_SMD_AKL:R_0805_2012Metric_Pad1.15x1.40mm_HandSolder | 4
R14 | 226k | https://www.vishay.com/docs/20035/dcrcwe3.pdf | PCM_Resistor_SMD_AKL:R_0603_1608Metric_Pad1.05x0.95mm_HandSolder | 1
R15,R18,R24,R25,R26,R27 | 100k | https://www.yageo.com/upload/media/product/products/datasheet/rchip/PYu-RC_Group_51_RoHS_L_12.pdf | -- mixed values -- | 6
R16,R17 | 1Ω | https://www.vishay.com/docs/20035/dcrcwe3.pdf | PCM_Resistor_SMD_AKL:R_0603_1608Metric_Pad1.05x0.95mm_HandSolder | 2
R19 | 31.6k | https://www.yageo.com/upload/media/product/products/datasheet/rchip/PYu-RC_Group_51_RoHS_L_12.pdf | PCM_Resistor_SMD_AKL:R_0603_1608Metric_Pad1.05x0.95mm_HandSolder | 1
R20 | 102k | https://www.vishay.com/docs/20035/dcrcwe3.pdf | PCM_Resistor_SMD_AKL:R_0603_1608Metric_Pad1.05x0.95mm_HandSolder | 1
R21 | 1k | https://www.yageo.com/upload/media/product/products/datasheet/rchip/PYu-RC_Group_51_RoHS_L_12.pdf | PCM_Resistor_SMD_AKL:R_0805_2012Metric_Pad1.15x1.40mm_HandSolder | 1
R22 | 50k | https://www.yageo.com/upload/media/product/app/datasheet/rchip/pyu-rt_1-to-0.01_rohs_l.pdf | PCM_Resistor_SMD_AKL:R_0603_1608Metric_Pad1.05x0.95mm_HandSolder | 1
R23 | 20.5k | https://www.yageo.com/upload/media/product/products/datasheet/rchip/PYu-RC_Group_51_RoHS_L_12.pdf | PCM_Resistor_SMD_AKL:R_0603_1608Metric_Pad1.05x0.95mm_HandSolder | 1
R28 | 11.3k | https://www.yageo.com/upload/media/product/products/datasheet/rchip/PYu-RC_Group_51_RoHS_L_12.pdf | PCM_Resistor_SMD_AKL:R_0603_1608Metric_Pad1.05x0.95mm_HandSolder | 1
TP1 | Black (GND) | https://www.keyelco.com/userAssets/file/M65p56.pdf | KeystoneTestpoints:Keystone_Testpoint_5001_MWG | 1
TP5 | Red (PPHV) | https://www.keyelco.com/userAssets/file/M65p56.pdf | KeystoneTestpoints:Keystone_Testpoint_5000_MWG | 1
TP6 | White (VBUS) | https://www.keyelco.com/userAssets/file/M65p56.pdf | KeystoneTestpoints:Keystone_Testpoint_5002_MWG | 1
TP7 | Yellow (ISENSE VBUS) | https://www.keyelco.com/userAssets/file/M65p56.pdf | KeystoneTestpoints:Keystone_Testpoint_5004_MWG | 1
U2 | INA211BIDCKT | https://www.ti.com/general/docs/suppproductinfo.tsp?distId=10 | INA211BIDCKT:SOT65P210X110-6N | 1
U3 | TPS25730 | https://www.ti.com/lit/ds/symlink/tps25730.pdf?ts=1707773923998 | TPS25730DREFR:TPS25730DREFR | 1
U4 | TPS552882RPMR | https://www.ti.com/lit/ds/symlink/tps552882.pdf?ts=1633815350361 | TPS552882RPMR:RPM0026A-MFG | 1

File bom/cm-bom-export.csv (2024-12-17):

Reference | Qty | Mfgr | MPN | Description | Footprint | Digikey
D5 | 1 | Wurth | 150060SS75000 | Light emitting diode | LED_SMD:LED_0603_1608Metric_Pad1.05x0.95mm_HandSolder | https://www.digikey.com/en/products/detail/w%C3%BCrth-elektronik/150060SS75000/4489903
D1,D2,D3,D4,D6 | 5 | Wurth | 150060VS75000 | Light emitting diode | LED_SMD:LED_0603_1608Metric_Pad1.05x0.95mm_HandSolder | https://www.digikey.com/en/products/detail/w%C3%BCrth-elektronik/150060VS75000/4489906
U7 | 1 | Analog Devices | ADM811MARTZ-REEL7 | Power supply supervisor, Manual reset, Threshold 4.38V, SOT-143 | Package_TO_SOT_SMD:SOT-143 | https://www.digikey.com/en/products/detail/analog-devices-inc/ADM811MARTZ-REEL7/995012
Q1,Q2,Q3 | 3 | Nexperia | BSH111BKR | SOT-23 N-MOSFET enchancement mode transistor, 55V, 210mA, 302mW, Alternate KiCAD Library | PCM_Package_TO_SOT_SMD_AKL:SOT-23 | https://www.digikey.com/en/products/detail/nexperia-usa-inc/BSH111BKR/5423826
C1,C4,C8 | 3 | TDK Corporation | C1608X6S1C475K080AC | CAP CER 4.7UF 16V X6S 0603 | C1608X6S1C475K080AC:CAP_1608_TDK-L | https://www.digikey.com/en/products/detail/tdk-corporation/C1608X6S1C475K080AC/3661574
C12 | 1 | YAGEO | CC0603KRX5R5BB224 | CAP CER 0.22UF 6.3V X5R 0603 | Capacitor_SMD:C_0603_1608Metric_Pad1.08x0.95mm_HandSolder | https://www.digikey.com/en/products/detail/yageo/CC0603KRX5R5BB224/5883717
J1,J2 | 2 | Hirose Electric Co Ltd | DF40C-100DP-0.4V(51) | Hirose DF40 1.5mm stacked, plug (male) | DF40C_100DP_0_4V_51_:HIROSE_DF40C-100DP-0.4V_51_ | https://www.digikey.com/en/products/detail/hirose-electric-co-ltd/df40c-100dp-0-4v-51/1969475
Y1 | 1 | Diodes Incorporated | FNETHE025 | XTAL OSC XO 25.0000MHZ CMOS SMD | FNETHE025:Crystal_SMD_7050_4Pads | https://www.digikey.com/en/products/detail/diodes-incorporated/FNETHE025/2273393
C13,C14,C15,C16,C20,C21,C23,C24,C26,C27,C29,C30 | 12 | Murata Electronics | GCM188R72A223KA37J | CAP CER 0.022UF 100V X7R 0603 | GCM188R72A223KA37J:CAPC1608X90N | https://www.digikey.com/en/products/detail/murata-electronics/GCM188R72A223KA37J/2591966
C31,C32,C33,C34,C35,C36,C37,C38,C39,C40,C41,C42 | 12 | Murata Electronics | GRM033R71A103KA01D | CAP CER 10000PF 10V X7R 0201 | GRM033R71A103KA01D:G-033_MUR-L | https://www.digikey.com/en/products/detail/murata-electronics/GRM033R71A103KA01D/702460
C2,C5,C9 | 3 | Murata | GRM1885C1H121JA01D | CAP CER 120PF 50V C0G/NP0 0603 | GRM1885C1H121JA01D:G-188_MUR-L | https://www.digikey.com/en/products/detail/murata-electronics/GRM1885C1H121JA01D/586936
C3,C6,C7,C10,C18,C19 | 6 | Murata Electronics | GRM188R60J226MEA0D | CAP CER 22UF 6.3V X5R 0603 | GRM188R60J226MEA0D:G-188_MUR-L | https://www.digikey.com/en/products/detail/murata-electronics/GRM188R60J226MEA0D/4280542
C17 | 1 | Murata Electronics | GRM188R61E225KA12D | CAP CER 2.2UF 25V X5R 0603 | GRM188R61E225KA12D:CAP_GRM188R61E225KA12D_MUR-L | https://www.digikey.com/en/products/detail/murata-electronics/GRM188R61E225KA12D/4905349
C22,C25,C28 | 3 | Murata Electronics | GRM188R71A225KE15D | CAP CER 2.2UF 10V X7R 0603 | GRM188R71A225KE15D:G-188_MUR-L | https://www.digikey.com/en/products/detail/murata-electronics/GRM188R71A225KE15D/1033256
C11 | 1 | Murata | GRM188R72A104KA35D | Unpolarized capacitor | Capacitor_SMD:C_0603_1608Metric_Pad1.08x0.95mm_HandSolder | https://www.digikey.com/en/products/detail/murata-electronics/GRM188R72A104KA35D/702549
L1,L2,L3 | 3 | Vishay Dale | IHLP1212ABERR47M11 | FIXED IND 470NH 6.4A 19.5MOHM SMD | IHLP1212ABERR47M11:IND_IHLP-1212AB_VIS-L | https://www.digikey.com/en/products/detail/vishay-dale/IHLP1212ABERR47M11/2533920
U9 | 1 | Lattice Semiconductor Corporation | LFE5U-85F-8BG381C | ECP5 FPGA, 84K LUTs, 1.2V, BGA-381 | Package_BGA:Lattice_caBGA-381_17.0x17.0mm_Layout20x20_P0.8mm_Ball0.4mm_Pad0.4mm_NSMD | https://www.digikey.com/en/products/detail/lattice-semiconductor-corporation/LFE5U-85F-8BG381C/5395911
U8 | 1 | Texas Instruments | LM3880MFX-1AA/NOPB | Simple Power Sequencer, SOT-23-6 | Package_TO_SOT_SMD:SOT-23-6 | https://www.digikey.com/en/products/detail/texas-instruments/LM3880MFX-1AA-NOPB/1871425
U10 | 1 | Micron Technology Inc. | MT48LC16M16A2P-6A:G | 256M – (16M x 16 bit) Synchronous DRAM (SDRAM), TSOP-II-54 | Package_SO:TSOP-II-54_22.2x10.16mm_P0.8mm | https://www.digikey.com/en/products/detail/micron-technology-inc/MT48LC16M16A2P-6A-G/4315922
R5,R10,R15,R16,R26 | 5 | YAGEO | RC0603FR-071KL | Resistor, US symbol | PCM_Resistor_SMD_AKL:R_0603_1608Metric_Pad1.05x0.95mm_HandSolder | -- mixed values --
R4,R9,R14,R22,R23,R24,R25,R36,R39 | 9 | YAGEO | RC0603FR-0710KL | Resistor, US symbol | PCM_Resistor_SMD_AKL:R_0603_1608Metric_Pad1.05x0.95mm_HandSolder | https://www.digikey.com/en/products/detail/yageo/RC0603FR-0710KL/726880
R2,R7,R12,R17 | 4 | YAGEO | RC0603FR-07100KL | RES 100K OHM 1% 1/10W 0603 | -- mixed values -- | https://www.digikey.com/en/products/detail/yageo/RC0603FR-07100KL/726889
R18,R19,R20 | 3 | YAGEO | RC0603FR-07100KL | RES 100K OHM 1% 1/10W 0603 | PCM_Resistor_SMD_AKL:R_0603_1608Metric_Pad0.98x0.95mm_HandSolder | https://www.digikey.com/en/products/detail/yageo/RC0603FR-07100KL/726889
R6 | 1 | YAGEO | RC0603FR-07316KL | RES 316K OHM 1% 1/10W 0603 | PCM_Resistor_SMD_AKL:R_0603_1608Metric_Pad1.05x0.95mm_HandSolder | https://www.digikey.com/en/products/detail/yageo/rc0603fr-07316kl/727153
R1 | 1 | YAGEO | RC0603FR-07453KL | RES 453K OHM 1% 1/10W 0603 | PCM_Resistor_SMD_AKL:R_0603_1608Metric_Pad1.05x0.95mm_HandSolder | https://www.digikey.com/en/products/detail/yageo/RC0603FR-07453KL/727247
R37,R38 | 2 | YAGEO | RC0603FR-072K2L | Resistor, US symbol | PCM_Resistor_SMD_AKL:R_0603_1608Metric_Pad1.05x0.95mm_HandSolder | https://www.digikey.com/en/products/detail/yageo/RC0603FR-072K2L/727016
R21,R27,R28,R29,R30,R31,R32,R33,R34,R35 | 10 | YAGEO | RC0603FR-074K7L | Resistor, US symbol | PCM_Resistor_SMD_AKL:R_0603_1608Metric_Pad1.05x0.95mm_HandSolder | https://www.digikey.com/en/products/detail/yageo/rc0603fr-074k7l/727212
R11 | 1 | YAGEO | RC0603FR-0782K5L | RES 82.5K OHM 1% 1/10W 0603 | PCM_Resistor_SMD_AKL:R_0603_1608Metric_Pad1.05x0.95mm_HandSolder | https://www.digikey.com/en/products/detail/yageo/rc0603fr-0782k5l/727402
U1,U3,U5 | 3 | Texas Instruments | TPS62823DLCR | 3A Step-Down Converter with DCS-Control, adjustable output, 2.4-5.5V input voltage, QFN-8 | Package_SON:Texas_VSON-HR-8_1.5x2mm_P0.5mm | https://www.digikey.com/en/products/detail/texas-instruments/TPS62823DLCR/9593382
U11 | 1 | Winbond Electronics | W25Q128JVSIQ | IC FLASH 128MBIT SPI/QUAD 8SOIC | W25Q128JVSIQ:SOIC127P790X216-8N | https://www.digikey.com/en/products/detail/winbond-electronics/W25Q128JVSIQ/5803943

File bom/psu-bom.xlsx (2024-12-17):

PSU Board
Pieces | 3
Part | Designator | Qty/Board | Order Qty | MPN | In cart? | Digikey
DC Barrel Input
2.1x5.5mm DC barrel, 8A, 24V | J1 | 1 | 3 | PJ-063AH | ✅ | https://www.digikey.com/en/products/detail/cui-devices/PJ-063AH/2161208
56uF Al poly electrolytic 35V | ~~C1~~ | 0 | 2 | PCV1V560MCL1GS | ✅ | https://www.digikey.com/en/products/detail/nichicon/PCV1V560MCL1GS/2618771
1UF 50V CAP CER X5R 0603 |  |  | 0 | UMK107BJ105KA-T | ❌ | https://www.digikey.com/en/products/detail/taiyo-yuden/UMK107BJ105KA-T/2178919
DIODE ZENER 33V 500MW SOD523 | DZ1 | 1 | 3 | MM5Z33VT1G | ✅ | https://www.digikey.com/en/products/detail/onsemi/MM5Z33VT1G/921089
RES 10 OHM 1% 1/10W 0603 |  |  | 0 | RC0603FR-0710RL | ❌ | https://www.digikey.com/en/products/detail/yageo/RC0603FR-0710RL/726879
Resistor 1k/0.1% 0603 |  |  | 0 | ERA−3AEB102V | ❌ | https://www.digikey.com/en/products/detail/panasonic-electronic-components/ERA-3AEB102V/1465854
Red test point, 0.1" | TP5,TP6 | 2 | 6 | 5000 | ✅ | https://www.digikey.com/en/products/detail/keystone-electronics/5000/255326
Black test point, 0.1" | TP1 | 1 | 3 | 5001 | ✅ | https://www.digikey.com/en/products/detail/keystone-electronics/5001/255327
Yellow test point, 0.1" | TP4 | 1 | 3 | 5004 | ✅ | https://www.digikey.com/en/products/detail/keystone-electronics/5004/362669
RES 10K OHM 1% 1/10W 0603 | R1,R11,R16,R25 | 4 | 12 | RC0603FR-0710KL | ✅ | https://www.digikey.com/en/products/detail/yageo/RC0603FR-0710KL/726880
RES 1K OHM 1% 1/10W 0603 | R2,R7,R12,R17,R26 | 5 | 15 | RC0603FR-071KL | ✅ | https://www.digikey.com/en/products/detail/yageo/RC0603FR-071KL/726843
LED yellow 0603 | D1 | 1 | 3 | 150060YS75000 | ✅ | https://www.digikey.com/en/products/detail/w%C3%BCrth-elektronik/150060YS75000/4489909
LED amber 0603 | D3 | 1 | 3 | 150060AS75000 | ✅ | https://www.digikey.com/en/products/detail/würth-elektronik/150060AS75000/10468254
Fuse holder 5x20mm | F1 | 1 | 3 | 696103101002 | ✅ | https://www.digikey.com/en/products/detail/w%C3%BCrth-elektronik/696103101002/7244555
Fuse 3.15A 5x20mm | F1 (3A fuse) | 1 | 3 | 0034.3122 | ✅ | https://www.digikey.com/en/products/detail/schurter-inc/0034-3122/639682
Fuse 5A 5x20mm | F1 (5A fuse) | 1 | 3 | 0034.3124 | ✅ | https://www.digikey.com/en/products/detail/schurter-inc/0034-3124/639681
Fuse 10A 5x20mm | F1 (10A fuse) | 1 | 3 | 0034.3127 | ✅ | https://www.digikey.com/en/products/detail/schurter-inc/0034-3127/640142
Fuse 20A 5x20mm | F1 (20A fuse) | 1 | 3 | 0034.3130 | ✅ | https://www.digikey.com/en/products/detail/schurter-inc/0034-3130/639761
2x3 0.1" headers male | J4,J5,J6,J7,J8,J9 | 6 | 18 | 61300311121 | ✅ | https://www.digikey.com/en/products/detail/w%C3%BCrth-elektronik/61300311121/4846825
2 x 3 gang jumper shunt 0.1" (3 circuits x 3A each) | - | 6 | 10 | MSBG-03-G | ✅ | https://www.digikey.com/en/products/detail/adam-tech/MSBG-03-G/9830986
SSC54-E3/57T (Schottky 5A / Vf=490mV) | D2,D5 | 2 | 6 | SSC54-E3/57T | ✅ | https://www.digikey.com/en/products/detail/vishay-general-semiconductor-diodes-division/SSC54-E3-57T/1091564
5V Buck
TPS565247DRLR IC REG BUCK ADJ 6A SOT563 | U1 | 1 | 3 | TPS565247DRLR | ✅ | https://www.digikey.com/en/products/detail/texas-instruments/TPS565247DRLR/16585647
RES 220K OHM 1% 1/10W 0603 | R5 | 1 | 3 | RC0603FR-07220KL | ✅ | https://www.digikey.com/en/products/detail/yageo/RC0603FR-07220KL/727062
RES 30K OHM 1% 1/10W 0603 | R6 | 1 | 3 | RC0603FR-0730KL | ✅ | https://www.digikey.com/en/products/detail/yageo/RC0603FR-0730KL/727140
RES 20K OHM 1% 1/10W 0603 | R4 | 1 | 3 | RC0603FR-0720KL | ✅ | https://www.digikey.com/en/products/detail/yageo/RC0603FR-0720KL/727040
RES 100K OHM 1% 1/10W 0603 | R3,~~R18,~~~~R19,R20,R21~~,R27 | 2 | 6 | RC0603FR-07100KL | ✅ | https://www.digikey.com/en/products/detail/yageo/RC0603FR-07100KL/726889
33pF 5% C0G/NP0 50V 0402 | C9 | 1 | 50 | GRM1555C1H330JA01D | ✅ | https://www.digikey.com/en/products/detail/murata-electronics/GRM1555C1H330JA01D/3693846
CAP CER 22UF 10V X7R 1206 | C5,C6,C7,C8 | 4 | 12 | GRM31CR71A226KE15L | ✅ | https://www.digikey.com/en/products/detail/murata-electronics/GRM31CR71A226KE15L/2039036
CAP CER 0.1UF 50V X7R 0603 | C10 | 1 | 3 | GCM188R71H104KA57D | ✅ | https://www.digikey.com/en/products/detail/murata-electronics/GCM188R71H104KA57D/1641653
CAP CER 10UF 25V X5R 0805 | C3,C4 | 2 | 6 | GRM21BR61E106MA73L | ✅ | https://www.digikey.com/en/products/detail/murata-electronics/GRM21BR61E106MA73L/4905533
CAP CER 0.1UF 100V X7R 0603 | C2,~~C18~~ | 1 | 3 | GRM188R72A104KA35D | ✅ | https://www.digikey.com/en/products/detail/murata-electronics/GRM188R72A104KA35D/702549
FIXED IND 2.2UH 14.5A 9.41 MOHM | L1 | 1 | 3 | IHLP3232DZER2R2M11 | ✅ | https://www.digikey.com/en/products/detail/vishay-dale/IHLP3232DZER2R2M11/2616972
Diode Power Mux
SSC53L-E3/57T (Schottky 5A / Vf=450mV) | D4 | 1 | 3 | SSC53L-E3/57T | ✅ | https://www.digikey.com/en/products/detail/vishay-general-semiconductor-diodes-division/SSC53L-E3-57T/1091563
LED green 0603 | D6,D7,D8,D9 | 4 | 12 | 150060VS75000 | ✅ | https://www.digikey.com/en/products/detail/w%C3%BCrth-elektronik/150060VS75000/4489906
Voltage Rails
2mΩ 1% 1W 1206 current shunt resistor | R10,R15,R24 | 3 | 9 | CSNL1206FT2L00 | ✅ | https://www.digikey.com/en/products/detail/stackpole-electronics-inc/CSNL1206FT2L00/1788091
INA210BIDCK SC-88/SOT-363 current sense amp (gain 200 V/V) |  |  | 0 | INA210BIDCKR | ❌ | https://www.digikey.com/en/products/detail/texas-instruments/INA210BIDCKR/3588712
INA211BIDCK SC-88/SOT-363 current sense amp (gain 500 V/V) | U3,U5,U9 | 3 | 9 | INA211BIDCKT | ✅ | https://www.digikey.com/en/products/detail/texas-instruments/INA211BIDCKT/3675147
TPS62823DLC 3A buck | U2,U4,U8 | 3 | 9 | TPS62823DLCR | ✅ | https://www.digikey.com/en/products/detail/texas-instruments/TPS62823DLCR/9593382
470nH IHLP1212 | L2,L3,L4 | 3 | 9 | IHLP1212AEERR47M11 | ✅ | https://www.digikey.com/en/products/detail/vishay-dale/IHLP1212AEERR47M11/2533925
CAP CER 4.7UF 10V X5R 0805 | C11,C14,C19 | 3 | 9 | C0805C475K8PAC7800 | ✅ | https://www.digikey.com/en/products/detail/kemet/C0805C475K8PAC7800/551599
120pF C0G NP0 0805 | C12 | 1 | 3 | KGM21BCG1H121JT | ✅ | https://www.digikey.com/en/products/detail/kyocera-avx/KGM21BCG1H121JT/563427
120pF C0G NP0 0603 | C15,C20 | 2 | 6 | GRM1885C1H121JA01D | ✅ | https://www.digikey.com/en/products/detail/murata-electronics/GRM1885C1H121JA01D/586936
100K 1% 0805 R | R9,R14,R23 | 3 | 9 | CRCW0805100KFKEA | ✅ | https://www.digikey.com/en/products/detail/vishay-dale/CRCW0805100KFKEA/1175865
453K 1% 0805 R | R8 | 1 | 3 | ERJ-6ENF4533V | ✅ | https://www.digikey.com/en/products/detail/panasonic-electronic-components/ERJ-6ENF4533V/112114
316K 1% 0805 | R13 | 1 | 3 | ERJ-6ENF3163V | ✅ | https://www.digikey.com/en/products/detail/panasonic-electronic-components/ERJ-6ENF3163V/112009
82.5K 1% 0805 | R22 | 1 | 3 | ERJ-6ENF8252V | ✅ | https://www.digikey.com/en/products/detail/panasonic-electronic-components/ERJ-6ENF8252V/111771
CAP CER 47UF 6.3V X5R 1206 | C13 | 1 | 3 | GRM31CR60J476KE19L | ✅ | https://www.digikey.com/en/products/detail/murata-electronics/GRM31CR60J476KE19L/2548176
CAP CER 22UF 6.3V X5R 0603 | C16,C17,C21 | 3 | 9 | GRM188R60J226MEA0D | ✅ | https://www.digikey.com/en/products/detail/murata-electronics/GRM188R60J226MEA0D/4280542
MOSFET N-CH 55V 210MA TO236AB SOT-23-3 | Q1,Q2,Q3 | 3 | 9 | BSH111BKR | ✅ | https://www.digikey.com/en/products/detail/nexperia-usa-inc/BSH111BKR/5423826
Power Supervisor
811M IC SUPERVISOR 1 CHANNEL SOT143-4 | ~~U6~~ | 0 | 0 | ADM811MARTZ-REEL7 | ❌ | https://www.digikey.com/en/products/detail/analog-devices-inc/ADM811MARTZ-REEL7/995012
IC PWR SUPPLY SEQUENCER SOT23-6 | ~~U7~~ | 0 | 0 | LM3880MFE-1AA/NOPB | ❌ | https://www.digikey.com/en/products/detail/texas-instruments/LM3880MFE-1AA-NOPB/2034896
Board I/O
1x8 male 0.1 pin header (for ISENSE analog inputs) | J3 |  | 0 | 61300811121 | ❌ | https://www.digikey.com/en/products/detail/w%C3%BCrth-elektronik/61300811121/4846839
REMALE 2x8 (16 contacts) R/A receptacle gold (for power conns) | - |  | 0 | PPPC082LJBN-RC | ❌ | https://www.digikey.com/en/products/detail/sullins-connector-solutions/PPPC082LJBN-RC/776019
MALE 2x8 (16 contacts) R/A pins gold (for power conns) | J2 | 1 | 3 | 61301621021 | ✅ | https://www.digikey.com/en/products/detail/w%C3%BCrth-elektronik/61301621021/4846855
Experimental TI TPS259480A Power Mux

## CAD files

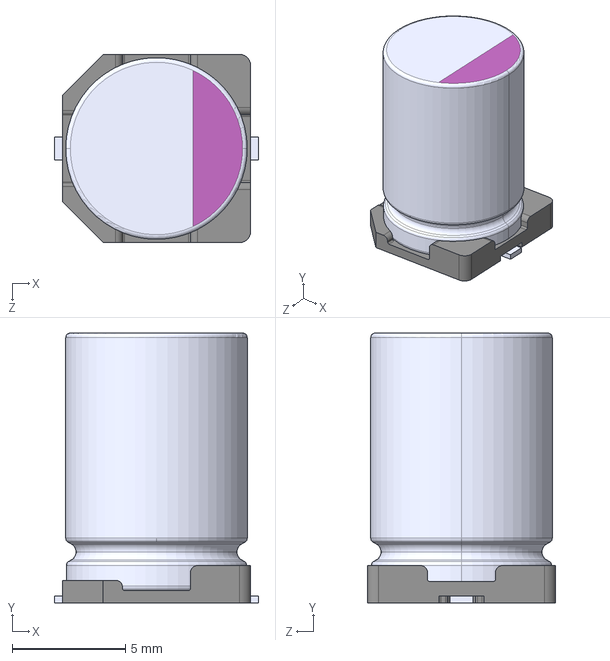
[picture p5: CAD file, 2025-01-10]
hardware/parts/16SVPF560M/16SVPF560M.step
9.00 x 11.9 x 8.30 mm

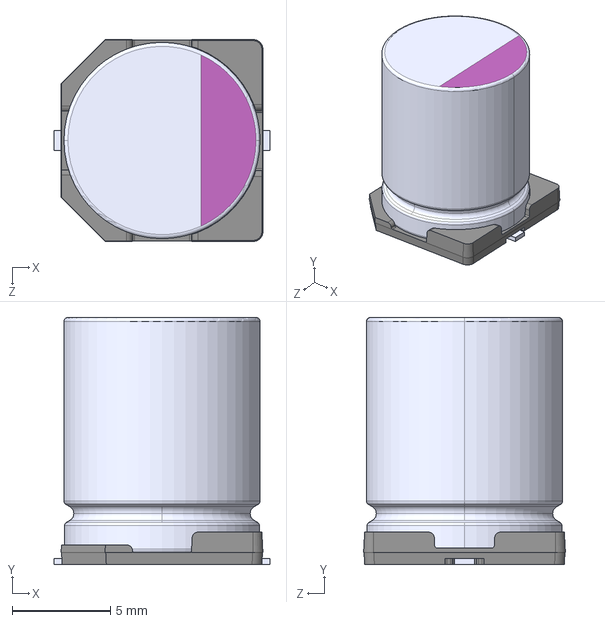
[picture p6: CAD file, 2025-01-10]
hardware/parts/25SVPF330M/25SVPF330M.step
11.0 x 12.6 x 10.3 mm

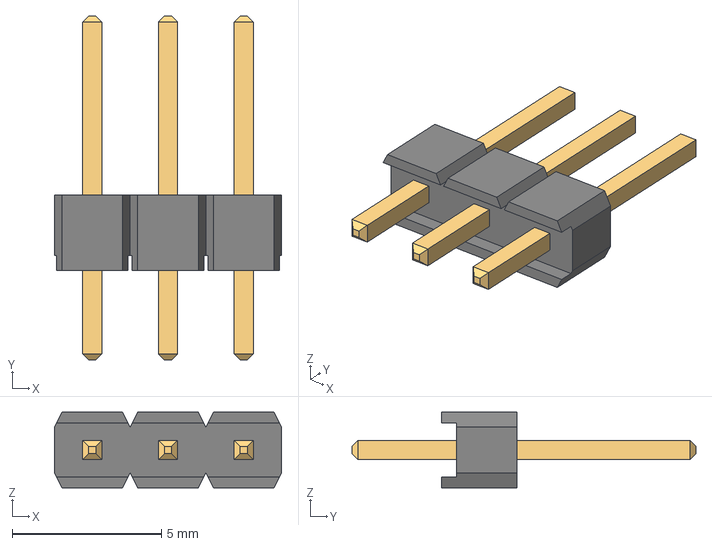
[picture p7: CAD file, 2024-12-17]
hardware/parts/61300311121/6130XX11121_61300311121.step
7.62 x 11.5 x 2.54 mm
6130xx11121_PIN x 3

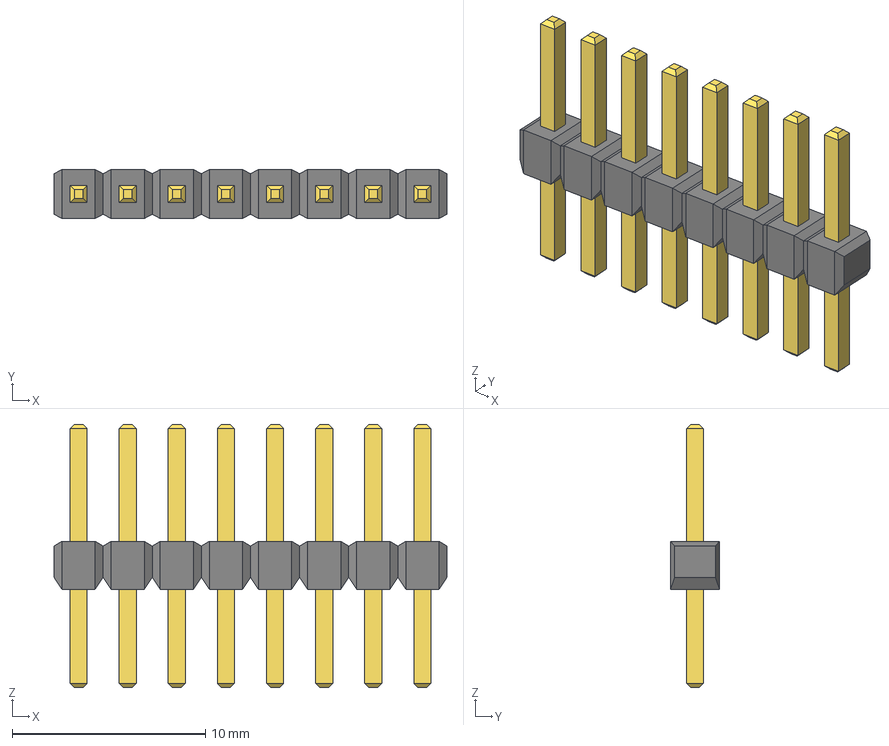
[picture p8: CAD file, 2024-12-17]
hardware/parts/61300811121/CONN8_61300811121_WRE.step
20.3 x 2.54 x 13.6 mm

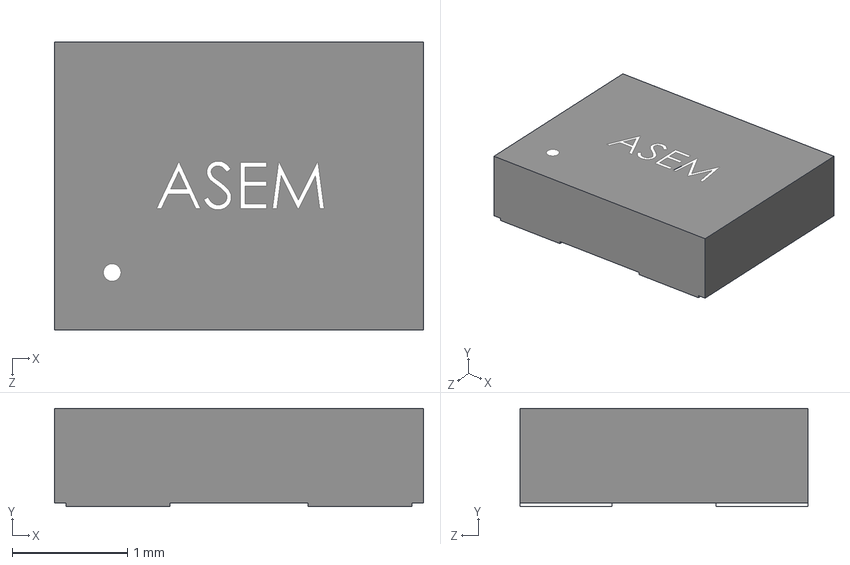
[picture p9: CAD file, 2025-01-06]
hardware/parts/ASEM1_12_000MHZ_LC_T/ASEM1-12.000MHZ-LC-T.step
3.20 x 0.85 x 2.50 mm

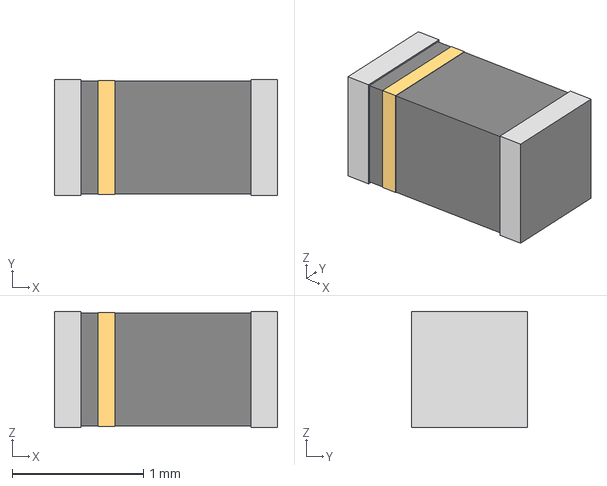
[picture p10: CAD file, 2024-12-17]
hardware/parts/C1608X6S1C475K080AC/CAP_1608_TDK.step
1.70 x 0.888 x 0.889 mm

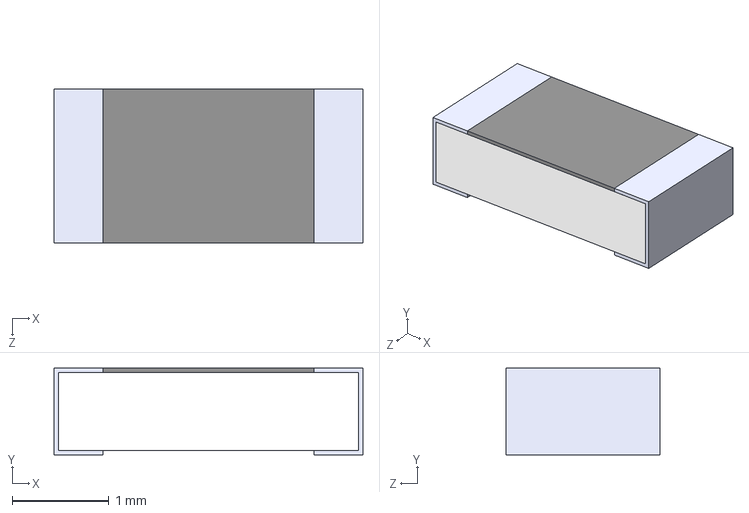
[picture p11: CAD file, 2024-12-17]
hardware/parts/CSNL1206FT2L00/CSNL1206FT2L00.step
3.20 x 0.9 x 1.60 mm

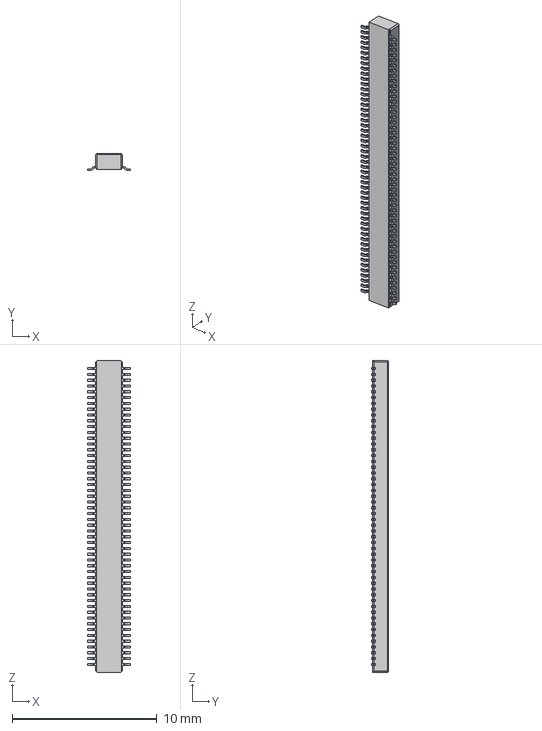
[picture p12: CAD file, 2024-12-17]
hardware/parts/DF40C_100DP_0_4V_51_/DF40C-100DP-0.4V_51_.step
2.97 x 1.14 x 21.5 mm

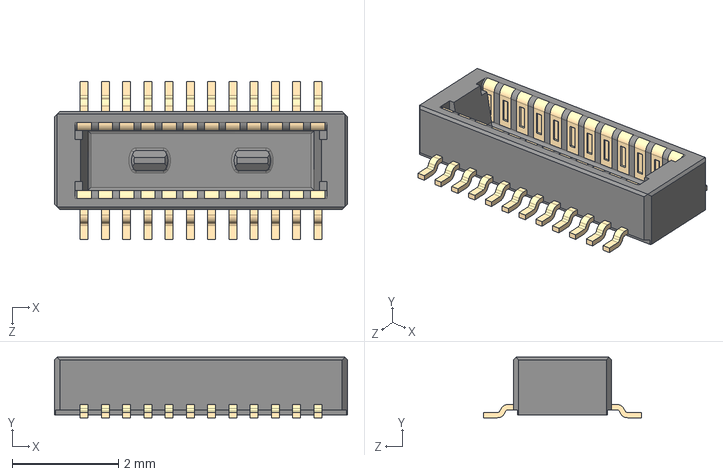
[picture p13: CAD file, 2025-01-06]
hardware/parts/DF40C_20DP_0_4V_51_/DF40C-20DP-0.4V_51_.step
5.52 x 1.14 x 2.97 mm

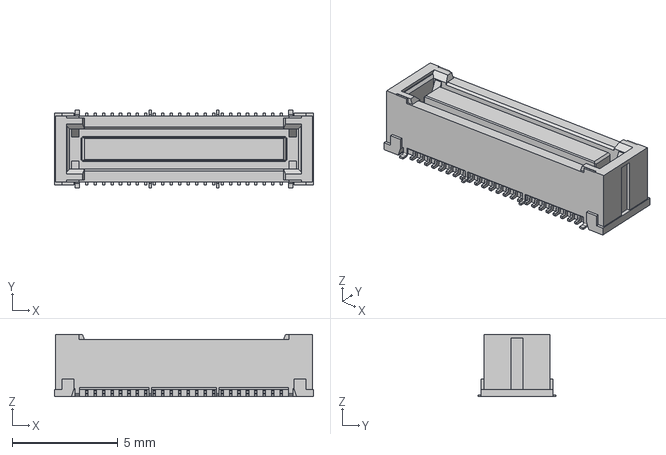
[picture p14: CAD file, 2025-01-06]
hardware/parts/DF40GB_3_0__48DS_0_4V_51_/DF40GB_3.0_-48DS-0.4V_51_.step
12.2 x 3.68 x 2.95 mm

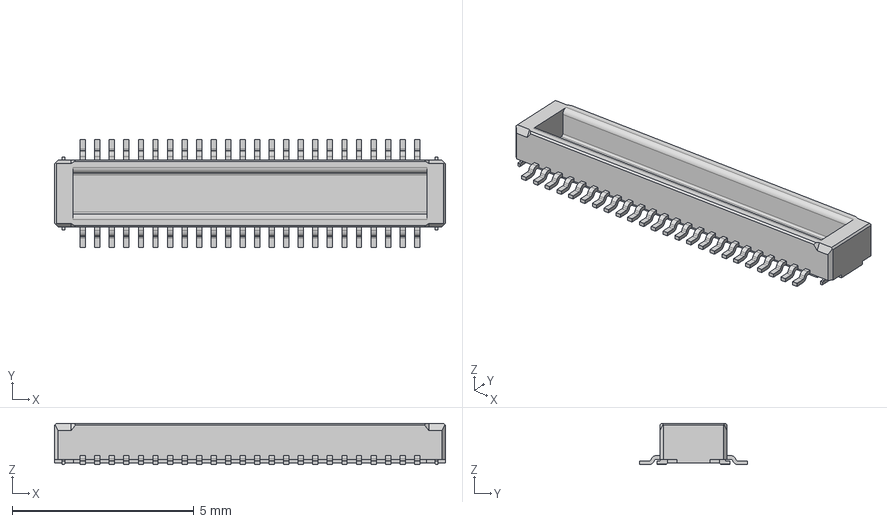
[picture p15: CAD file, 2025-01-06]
hardware/parts/DF40GB_48DP_0_4V_58_/DF40GB-48DP-0.4V_58_.step
10.8 x 2.97 x 1.14 mm

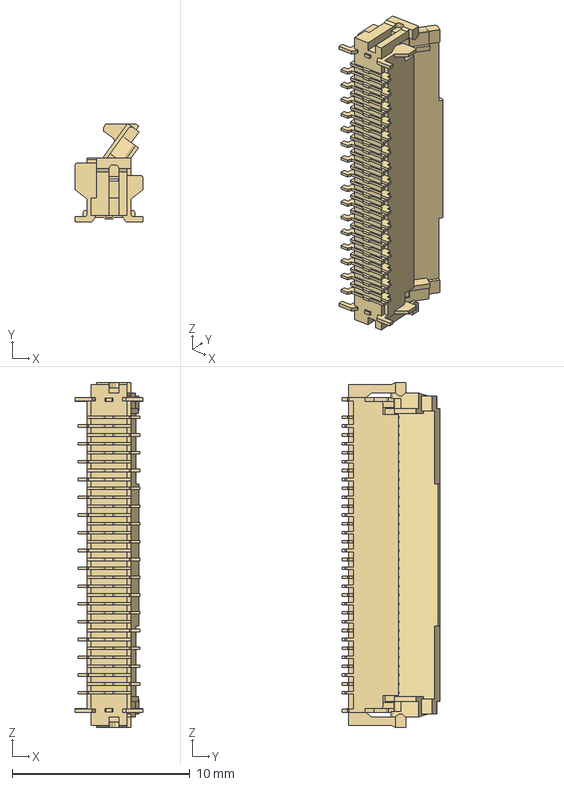
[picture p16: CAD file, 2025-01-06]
hardware/parts/FH12-32S-0.5SVA/FH12-32S-0.5SVA(54)/FH12-32S-0.5SV.stp
3.80 x 5.50 x 19.4 mm

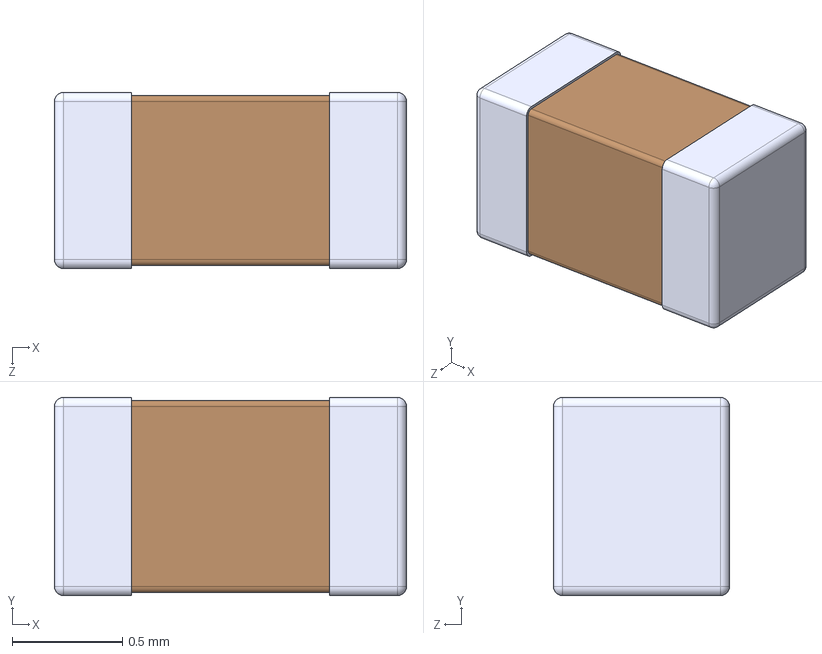
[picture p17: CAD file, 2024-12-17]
hardware/parts/GCM188R72A223KA37J/GCM188R72A223KA37J.step
1.60 x 0.9 x 0.8 mm

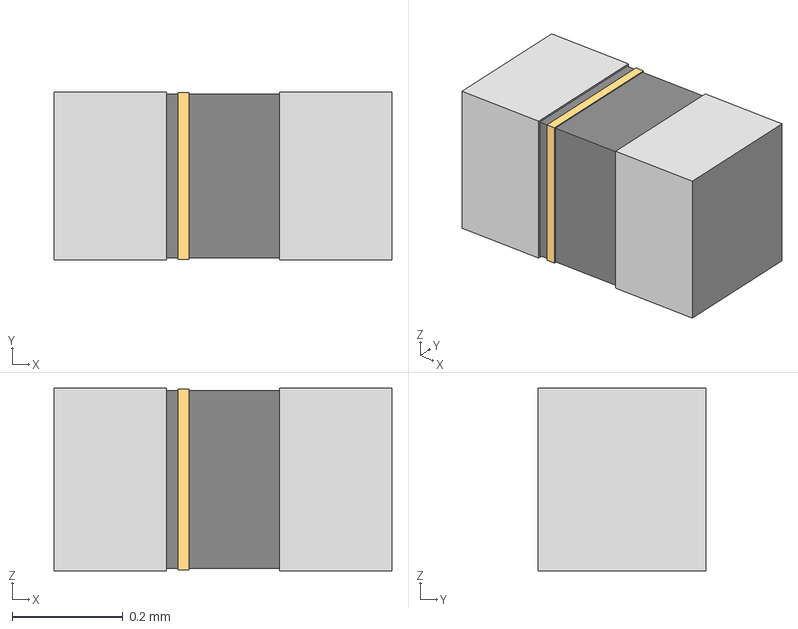
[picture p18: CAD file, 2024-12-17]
hardware/parts/GRM033R71A103KA01D/G-033_MUR.step
0.61 x 0.304 x 0.33 mm

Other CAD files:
hardware/parts/GRM1885C1H121JA01D/G-188_MUR.step
hardware/parts/GRM188R60J226MEA0D/G-188_MUR.step
hardware/parts/GRM188R61E225KA12D/CAP_GRM188R61E225KA12D_MUR.step
hardware/parts/GRM188R71A225KE15D/G-188_MUR.step
hardware/parts/10129381-916001BLF/s10129381-X16001XLF.stp
hardware/parts/61301621021/61301621021_Download_STP_61301621021_rev1.stp
hardware/parts/696103101002/696103101002_rev1.stp
hardware/parts/CSD16327Q3/CSD16327Q3.step
hardware/parts/ICD15S13E4GX00LF/ICD15S13E4GX00LF.step
hardware/parts/IHLP1212ABERR47M11/IND_IHLP-1212AB_VIS.step
hardware/parts/IHLP1212AEERR47M11/IND_IHLP-1212AE_VIS.step
hardware/parts/IHLP3232DZER2R2M11/IHLP3232DZ.step
hardware/parts/IHLP6767DZER6R8M11/IHLP6767DZ.step
hardware/parts/INA210BIDCKR/INA210BIDCKR.step
hardware/parts/INA211BIDCKT/INA211BIDCKT.step
hardware/parts/IRF9540NSTRLPBF/IRF9540NSTRLPBF.step
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

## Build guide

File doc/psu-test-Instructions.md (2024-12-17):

# PSU Test Instructions

## Indicator LEDs abd Test Points

| LED | Color  | Description |
|-----|---|---|
| D1  | Yellow | Barrel VDC OK |
| D3  | Amber  | 5V buck OK |
| D6  | Green  | +5V rail OK |
| D7  | Green  | +3V3 rail OK |
| D8  | Green  | +2V5 rail OK |
| D9  | Green  | +1V1 rail OK |

| TP  | Color  | Description |
|-----|---|---|
| TP1 | Black  | GND |
| TP2 | (pad)  | Pre-fuse |
| TP3 | (pad)  | Post-fuse |
| TP4 | Yellow | VDC (~12V) |
| TP5 | Red | 5V buck V_OUT |
| TP6 | Red | +5V output (after mux, ~4.5V)|

## Testing Procedure

### 1. Make sure barrel jack center hole is +12V relative to outer shell.

### 2. First test 5V buck converter alone:

 - Plug in 12V barrel jack
 - D1 (yellow) should be ON indicating 12V input
 - D3 (amber) should be ON indicating 5V buck output
 - D6 (green) should be ON indicating ~4.5V output after mux
 - TP2 should be 12V
 - TP3 should be 12V
 - TP4 should be 12V (minus diode drop ~0.5V)
 - TP5 should be 5V
 - TP6 must be >= 4.5V
 - D7,D8,D9 should be OFF because DET not shorted to +5V simulating connector plug-in

### 3. Test USB VBUS input alone

 - Unplug 12V barrel jack
 - Apply artificial 5V to EXT VBUS input on J2
 - D1 (yellow) should be OFF indicating 12V input
 - D3 (amber) should be OFF indicating 5V buck output
 - D6 (green) should be ON indicating ~4.5V output after mux
 - TP2,TP3,TP4,TP5 should be all 0V
 - TP6 must be >= 4.5V
 - D7,D8,D9 should be OFF because DET not shorted to +5V simulating connector plug-in

### 4. Test USB VBUS **and** 12V barrel jack

 - Plug in 12V barrel jack
 - Apply artificial 5V to EXT VBUS input on J2
 - D1 (yellow) should be ON indicating 12V input
 - D3 (amber) should be ON indicating 5V buck output
 - D6 (green) should be ON indicating ~4.5V output after mux
 - TP2 should be 12V
 - TP3 should be 12V
 - TP4 should be 12V (minus diode drop ~0.5V)
 - TP5 should be 5V
 - TP6 should be >= 4.5V
 - D7,D8,D9 should be OFF because DET not shorted to +5V simulating connector plug-in

### 5. Measure voltage rails
 - Plug in 12V barrel jack only
 - Short DET to +5V on J2
 - D7,D8,D9 should now come ON
 - Measure +5V rail Vout on J2 with DMM (should be ~4.5V)
 - Measure +3V3 rail Vout on J2 with DMM (should be ~3.30V)
 - Measure +2V5 rail Vout on J2 with DMM (should be ~2.50V)
 - Measure +1V1 rail Vout on J2 with DMM (should be ~1.10V)

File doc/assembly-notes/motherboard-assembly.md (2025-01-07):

# Motherboard Assembly Notes

## Important Notes

- All fine-pitch components on are front side
- LED polarity mark goes toward silkscreen cathode mark (thick line)
	- Also: silkscreen arrow always points toward polarity (cathode) mark
- Power LEDs:
	- (amber) = VBUS\_IN (5V)
	- (white) = +5V rail good
	- (green) = +3.3V rail good
- When placing J3, make sure pins on bottom line up with pads!  Connector can only go one way.
- **IMPORTANT**:  need to cut VBUS trace into TVS. See image at [https://github.com/mikegoelzer/Homebrew-ECP5-SBC/issues/6](github.com/mikegoelzer/Homebrew-ECP5-SBC/issues/6)

## Assembly Instructions

1.  Assemble front side and bake

2.  Assemble back side and bake

3.  Plug the `pd-booster-null` board into 2x4 connector to pull `CC1`/`CC2` down with 5.1k to ground

4.  To test USB-PD:

	- First, cut the trace near `D1` silk screen as described above
	- Replace `pd-booster-null` with `pd-booster-16amps`
	- Plug in USB-C cable to charger that supports USB-PD
	- Check power LEDs

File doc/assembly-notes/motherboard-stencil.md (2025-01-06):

# Solder Paste Stencil Notes

For Rev 1:

- Front stencil: aluminum 0.1mm, back stencil: doesn't matter
- "Solder paste relative clearance" settings on pads varies by component lead pitch:
	- For ≤ 0.5mm pitch components:  `-10%` in Kicad (approximately 35% volume reduction)
	- For 0.65mm pitch components:   `-7.5%` in Kicad (~28% reduction)
	- For ≥ 1.0mm  pitch components: `-5%` in Kicad (~19% reduction) or `0`

See [kicad-stencil-aperture-calcs.xlsx](./kicad-stencil-aperture-calcs.xlsx) for volume reduction empirical findings.

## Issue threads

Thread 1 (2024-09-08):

psu add a physical switch for safety

mikegoelzer, 2024-09-08:
- right angle
- can handle 5 amps / 12 V
- DPDT to cut both mains power and USB debug port power?  (necessary?)

e.g., [this SPST one](https://www.digikey.com/en/products/detail/c-k/L101011ML04Q/3753550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)

mikegoelzer, 2025-01-10:
Closing bc psu project merged into pd-booster-16amps

Closed 2025-01-10.

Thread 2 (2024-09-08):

psu: add fuse or PTC and reverse polarity protection

mikegoelzer, 2024-09-08:
See old `VoltageRailsBoard` project.  Also see TrellisBoard's configuration:  Schottky MBR15U60 will blow fuse if 12 Vin jack insertion has polarity reversed.

mikegoelzer, 2025-01-10:
Closing bc psu merged into pd-booster-16amps (which has this feature)

Closed 2025-01-10.

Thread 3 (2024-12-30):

CM:  power rails master reset btn should be brought out on the connector

mikegoelzer, 2024-12-30:

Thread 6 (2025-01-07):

motherboard:  wrong TVS diode

mikegoelzer, 2025-01-07:
Rev 1 of motherboard contains a TVS diode on VBUS that is incompatible with USB-PD.  The diode clamps VBUS at 6.1V, whereas USB-PD voltages are 5-20V.

Tempoary solution:  cut the VBUS trace into the diode.  This will remove transient protection on VBUS, but leave it intact on the DP/DM lines.

Longer term solution:  replace with [TVS2200](https://www.ti.com/lit/ds/symlink/tvs2200.pdf?HQS=dis-dk-null-digikeymode-dsf-pf-null-wwe&ts=1736282751058) 22-volt clamp.

Trace to cut shown in red circle below:

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

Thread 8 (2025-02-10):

motherboard:  USB debug connector bad footprint

mikegoelzer, 2025-02-10:
The USB-C debug connector's footprint does not match the physical connector.

Increase drill slot for front-most two thru-hole tabs of connector.

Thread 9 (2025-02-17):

motherboard:  move SD card slot

mikegoelzer, 2025-02-17:
Move SD card slot off of hat and down to main board.  Use data lines currently running to hat.

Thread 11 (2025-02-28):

motherboard:  changes for rev 2

mikegoelzer, 2025-02-28:
- [ ] move sd card onto mobo
- [ ] move 5.1k pull downs onto mobo
- [ ] larger holes on usb connector
- [ ] LED brightness?

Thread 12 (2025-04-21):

cm:  5V LED is installed backwards

mikegoelzer, 2025-04-21:
Polarity is backwards in the schematic.  Flip it around.

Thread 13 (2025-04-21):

CM:  wiring of DONE LED is wrong

mikegoelzer, 2025-04-21:
This is [reference schematic](https://www.latticesemi.com/view_document?document_id=143):

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

This is GCM Rev 1:

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

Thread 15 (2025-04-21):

motherboard:  reset button

mikegoelzer, 2025-04-21:
There should be a reset button on the mother board, either a full power cycle reset or a soft reset of the FPGA that pulls PROGRAMN low.  Too much of a hassle to plug/unplug USB-C power cable to reset.

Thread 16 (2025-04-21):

CM:  improve top side of board

mikegoelzer, 2025-04-21:
Important test points are all on the bottom of the board.  This makes it hard to test.  Add these to top:

  - place a single user-controlled LED on top side of board
  - 2x1.27mm holes for 5V and GND for quick power testing
  - test points to check voltage rails from top

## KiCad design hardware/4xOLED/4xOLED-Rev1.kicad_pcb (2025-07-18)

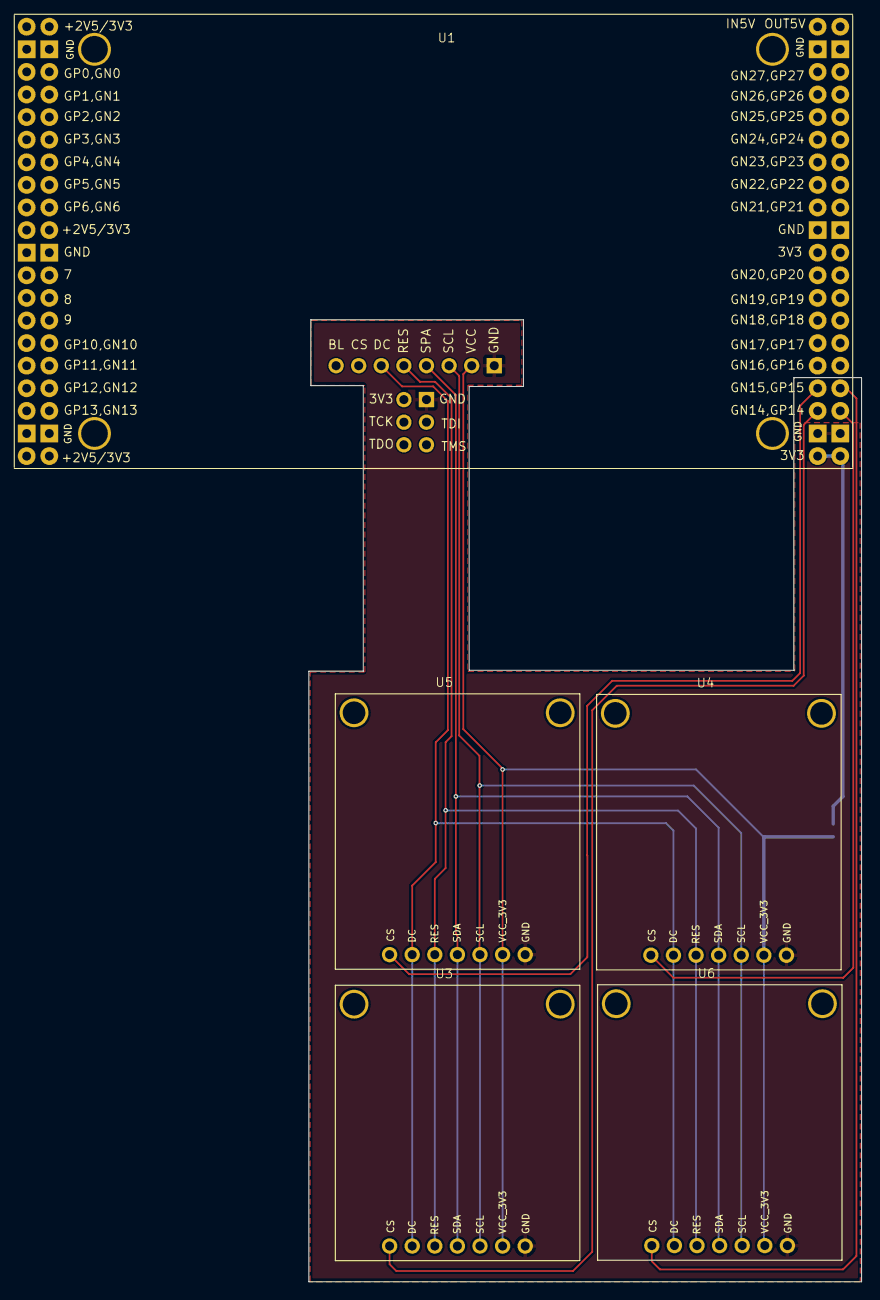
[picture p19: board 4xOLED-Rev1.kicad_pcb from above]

Board: 2 copper layers, 62.1 x 108.1 mm, 6 parts (1 on the bottom side), 11 nets.

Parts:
JP1: SolderJumper_2_Open; SolderJumper-2_P1.3mm_Open_TrianglePad1.0x1.5mm
U1: ULX3S
U3: OLED #3; OLED 0.95in 96x128 SPI_No_Bottom_Drill_Holes
U4: OLED #2; OLED 0.95in 96x128 SPI_No_Bottom_Drill_Holes
U5: OLED #1; OLED 0.95in 96x128 SPI_No_Bottom_Drill_Holes
U6: OLED #4; OLED 0.95in 96x128 SPI_No_Bottom_Drill_Holes

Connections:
GND: U1.3 (GND), U1.4 (GND), U1.21 (GND), U1.22 (GND), U1.37 (GND), U1.38 (GND), U1.43 (GND), U1.44 (GND), U1.59 (GND), U1.60 (GND), U1.77 (GND), U1.78 (GND), U1.88 (GND), U1.90 (GND), U3.7 (GND), U4.7 (GND), U5.7 (GND), U6.7 (GND)
unnamed: JP1.2 (B), U1.79 (3V3), U1.80 (3V3)
OLED_CS_1: U1.73 (GN15), U5.1 (CS)
OLED_CS_2: U1.76 (GP14), U4.1 (CS)
OLED_CS_3: U1.75 (GN14), U3.1 (CS)
OLED_CS_4: U1.74 (GP15), U6.1 (CS)
OLED_DC: U1.83 (OLED_DC), U3.2 (DC), U4.2 (DC), U5.2 (DC), U6.2 (DC)
OLED_MOSI: U1.85 (OLED_MOSI), U3.4 (SDA), U4.4 (SDA), U5.4 (SDA), U6.4 (SDA)
OLED_RST: U1.84 (OLED_RES), U3.3 (RES), U4.3 (RES), U5.3 (RES), U6.3 (RES)
OLED_SCK: U1.86 (OLED_SCK), U3.5 (SCL), U4.5 (SCL), U5.5 (SCL), U6.5 (SCL)
OLED_VCC: JP1.1 (A), U1.87 (OLED_VCC_3V3), U3.6 (VCC_3V3), U4.6 (VCC_3V3), U5.6 (VCC_3V3), U6.6 (VCC_3V3)

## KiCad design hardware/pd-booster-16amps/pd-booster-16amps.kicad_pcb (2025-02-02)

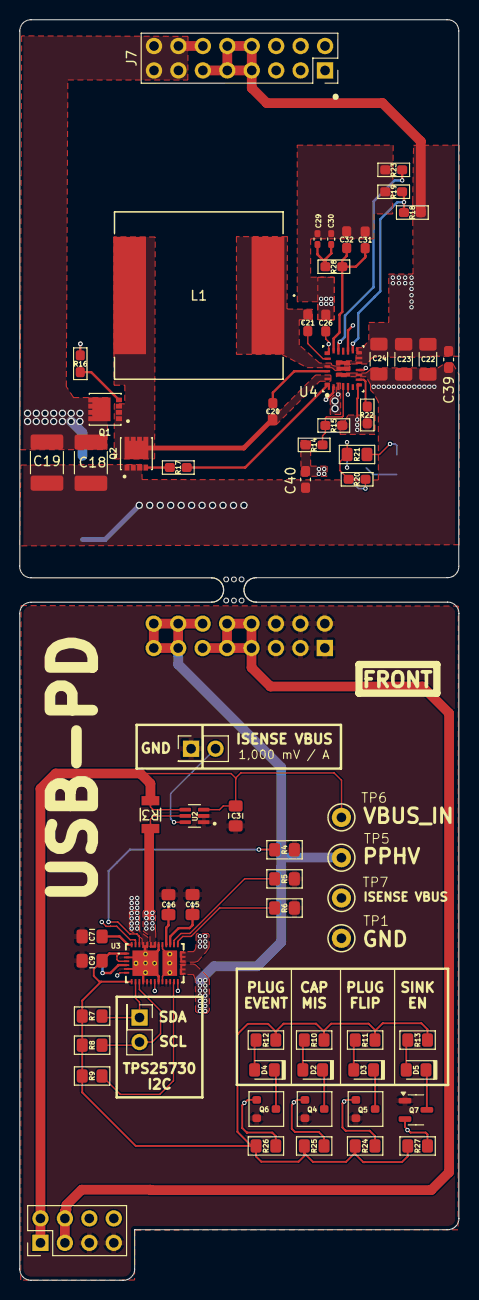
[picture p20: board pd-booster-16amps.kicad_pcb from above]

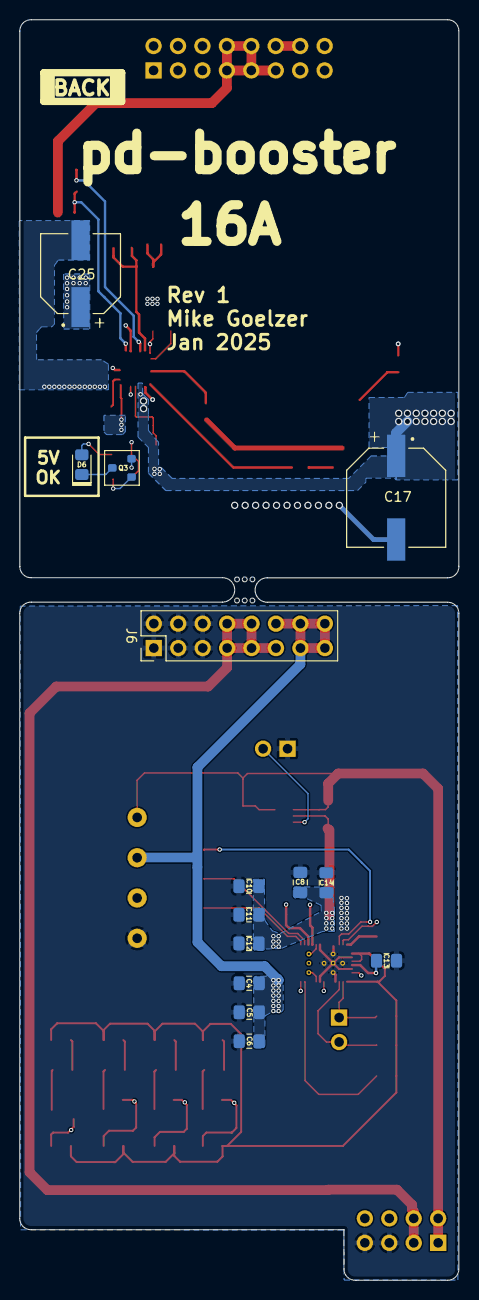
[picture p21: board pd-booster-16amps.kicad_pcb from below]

Board: 4 copper layers, 45.6 x 131.0 mm, 82 parts (14 on the bottom side), 48 nets.

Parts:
C3: 0.1uF; C_0805_2012Metric_Pad1.18x1.45mm_HandSolder
C4: 22uF/35V; C_0805_2012Metric_Pad1.18x1.45mm_HandSolder
C5, C6, C7, C9: 10uF/50V; C_0805_2012Metric_Pad1.18x1.45mm_HandSolder
C8, C10, C11, C12: 10nF/50V; C_0805_2012Metric_Pad1.18x1.45mm_HandSolder
C13, C14: 4.7uF/35V; C_0805_2012Metric_Pad1.18x1.45mm_HandSolder
C15, C16: 330pF/50V; C_0805_2012Metric_Pad1.18x1.45mm_HandSolder
C17: 330uF; CAP_25SVPF330M
C18, C19: 6.8uF; C_1812_4532Metric_Pad1.57x3.40mm_HandSolder
C20, C21: 100nF; C_0603_1608Metric_Pad1.08x0.95mm_HandSolder
C22, C23, C24: 100uF; C_1206_3216Metric_Pad1.33x1.80mm_HandSolder
C25: 560uF; CAP_16SVPF560M
C26: 4.7uF; C_0603_1608Metric_Pad1.08x0.95mm_HandSolder
C29, C30: 15nF; C_0402_1005Metric_Pad0.74x0.62mm_HandSolder
C31, C32: 10pF; C_0603_1608Metric_Pad1.08x0.95mm_HandSolder
C39, C40: 1uF; C_0603_1608Metric_Pad1.08x0.95mm_HandSolder
D2: Red; LED_0805_2012Metric_Pad1.15x1.40mm_HandSolder
D3: Yellow; LED_0805_2012Metric_Pad1.15x1.40mm_HandSolder
D4: Amber; LED_0805_2012Metric_Pad1.15x1.40mm_HandSolder
D5, D6: Green; LED_0805_2012Metric_Pad1.15x1.40mm_HandSolder
J2: 2x4 male 0.1"; PinHeader_2x04_P2.54mm_Vertical
J3, J5: PH1-02-UA; PinHeader_2x01_P2.54mm_Vertical
J6: female (front board); PinHeader_2x08_P2.54mm_Vertical
J7: male pins 16mm (back board); PinHeader_2x08_P2.54mm_Vertical
L1: 6.8uH; IND_IHLP-6767DZ_VIS-M
MB1: PCB mouse bites; mouse-bite-2.54mm-slot
Q1, Q2: CSD16327Q3; TRANS_CSD16327Q3
Q3, Q4, Q5, Q6: BSH111; SOT-23
Q7: BSS84 (PMOS); SOT-23-3
R3: 2mΩ 1% 1W; STA_CSNL1206_STP
R4, R5, R6, R9: 10k; R_0805_2012Metric_Pad1.15x1.40mm_HandSolder
R7, R8: 3.3k; R_0805_2012Metric_Pad1.15x1.40mm_HandSolder
R10, R11, R12, R13: 33k; R_0805_2012Metric_Pad1.15x1.40mm_HandSolder
R14: 226k; R_0603_1608Metric_Pad1.05x0.95mm_HandSolder
R15, R18: 100k; R_0603_1608Metric_Pad1.05x0.95mm_HandSolder
R16, R17: 1Ω; R_0603_1608Metric_Pad1.05x0.95mm_HandSolder
R19: 31.6k; R_0603_1608Metric_Pad1.05x0.95mm_HandSolder
R20: 102k; R_0603_1608Metric_Pad1.05x0.95mm_HandSolder
R21: 1k; R_0805_2012Metric_Pad1.15x1.40mm_HandSolder
R22: 50k; R_0603_1608Metric_Pad1.05x0.95mm_HandSolder
R23: 20.5k; R_0603_1608Metric_Pad1.05x0.95mm_HandSolder
R24, R25, R26, R27: 100k; R_0805_2012Metric_Pad1.15x1.40mm_HandSolder
R28: 11.3k; R_0603_1608Metric_Pad1.05x0.95mm_HandSolder
TP1: Black (GND); Keystone_Testpoint_5001_MWG
TP5: Red (PPHV); Keystone_Testpoint_5000_MWG
TP6: White (VBUS); Keystone_Testpoint_5002_MWG
TP7: Yellow (ISENSE VBUS); Keystone_Testpoint_5004_MWG
U2: INA211BIDCKT; SOT65P210X110-6N
U3: TPS25730; TPS25730DREFR
U4: TPS552882RPMR; RPM0026A-MFG

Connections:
/Buck-Boost/5V_OUT: C22.1, C23.1, C24.1, C25.1, C39.1, J2.3, J2.4, J6.7, J6.8, J6.9, J6.10, J6.11, J7.7, J7.8, J7.9, J7.10, J7.11, R18.2, U4.11 (VOUT), U4.12 (ISP), U4.13 (ISN), U4.26 (VOUT)
/Buck-Boost/5V_OUT_PG: Q3.1 (G), R20.2, U4.5 (PG)
/Buck-Boost/LDO_5V2: C26.1, R20.1, R21.2, U4.19 (VCC)
/Buck-Boost/SW1: C20.1, L1.2, Q1.1 (S), Q1.2 (S), Q1.3 (S), Q2.5-8 (D), U4.23 (SW1)
/Buck-Boost/SW2: C21.2, L1.1, U4.21 (SW2), U4.25 (SW2)
/Buck-Boost/V_MUX_OUT: C4.2, C5.2, C6.2, C17.1, C18.1, C19.1, C40.1, J6.12, J6.13, J6.14, J6.15, J6.16, J7.12, J7.13, J7.14, J7.15, J7.16, Q1.5-8 (D), R14.2, TP5.1, U3.20 (PPHV_1), U3.21 (PPHV_2), U3.22 (PPHV_3), U3.41 (PPHV_4), U4.3 (VIN)
/Connectors/VBUS_IN: C3.1, J2.1, J2.2, R3.1, TP6.1, U2.3 (V+), U2.4 (+IN)
/USB PD/ADCIN2: C9.2, R7.1, R8.1, R9.1, R10.2, R11.2, R12.2, R13.2, R24.1, R25.1, R26.1, R27.1, U3.1 (LDO_3V3), U3.3 (ADCIN2), U3.7 (ADCIN4)
/USB PD/CAP_MIS: Q4.1 (G), R25.2, U3.6 (CAP_MIS)
/USB PD/DRAIN: U3.15 (DRAIN_1), U3.30 (DRAIN_2), U3.40 (DRAIN_3)
/USB PD/LDO_1V5: C13.2, U3.4 (LDO_1V5)
/USB PD/PLUG_EVENT: Q6.1 (G), R26.2, U3.37 (PLUG_EVENT)
/USB PD/PLUG_FLIP: Q5.1 (G), R24.2, U3.13 (PLUG_FLIP)
/USB PD/VBUS_IN_POST_SHUNT: C8.2, C10.2, C11.2, C12.2, C14.2, R3.2, U2.5 (-IN), U3.23 (VBUS_IN_1), U3.24 (VBUS_IN_2), U3.25 (VBUS_IN_3), U3.32 (VBUS_1), U3.33 (VBUS_2), U3.42 (VBUS_IN_4), U3.43 (VBUS_3)
/USB PD/VIN_3V3: C7.2, U3.38 (VIN_3V3)
/USB PD/~FAULT_IN: R9.2, U3.18 (~FAULT_IN)
/USB PD/~SINK_EN: Q7.2 (G), R27.2, U3.19 (~SINK_EN)
CC1: C15.2, J2.6, U3.28 (CC1)
CC2: C16.2, J2.8, U3.29 (CC2)
GND: C3.2, C4.1, C5.1, C6.1, C7.1, C8.1, C9.1, C10.1, C11.1, C12.1, C13.1, C14.1, C15.1, C16.1, C17.2, C18.2, C19.2, C22.2, C23.2, C24.2, C25.2, C26.2, C29.2, C30.2, C31.2, C32.2, C39.2, C40.2, J2.5, J2.7, J3.1, J6.1, J6.2, J6.3, J6.4, J6.5, J6.6, J7.1, J7.2, J7.3, J7.4, J7.5, J7.6, Q2.1 (S), Q2.2 (S), Q2.3 (S), Q3.2 (S), Q4.2 (S), Q5.2 (S), Q6.2 (S), Q7.1 (D), R4.2, R5.2, R6.2, R15.1, R19.1, R22.1, R23.1, TP1.1, U2.1 (REF), U2.2 (GND), U3.2 (ADCIN1), U3.5 (ADCIN3), U3.10 (DBG_ACC), U3.11 (GND_1), U3.12 (GND_2), U3.14 (GND_3), U3.16 (GND_4), U3.17 (GND_5), U3.31 (GND_6), U3.34 (GND_7), U3.35 (GND_8), U3.39 (GND_9), U3.44 (GND_10), U4.7 (DITH_SYNC), U4.9 (PGND), U4.10 (AGND), U4.15 (MODE), U4.24 (PGND)
ISENSE_VBUS: J3.2, TP7.1, U2.6 (OUT)
unnamed: C29.1, C30.1, R28.1
unnamed: D2.2 (A), R10.1
unnamed: D2.1 (K), Q4.3 (D)
unnamed: D3.2 (A), R11.1
unnamed: D3.1 (K), Q5.3 (D)
unnamed: D4.2 (A), R12.1
unnamed: D4.1 (K), Q6.3 (D)
unnamed: D5.2 (A), R13.1
unnamed: D5.1 (K), Q7.3 (S)
unnamed: D6.2 (A), R21.1
unnamed: D6.1 (K), Q3.3 (D)
unnamed: Q1.4 (G), R16.2
unnamed: Q2.4 (G), R17.2
unnamed: R6.1, U3.26 (RESERVED_1)
unnamed: R5.1, U3.27 (RESERVED_2)
unnamed: R4.1, U3.36 (RESERVED_3)
unnamed: C20.2, U4.22 (BOOT1)
unnamed: C21.1, U4.20 (BOOT2)
unnamed: C31.1, C32.1, R28.2, U4.18 (COMP)
unnamed: R16.1, U4.2 (DR1H)
unnamed: R17.1, U4.1 (DR1L)
unnamed: R14.1, R15.2, U4.4 (EN)
unnamed: R18.1, R19.2, U4.14 (FB)
unnamed: R22.2, U4.8 (FSW)
unnamed: R23.2, U4.17 (ILIM)
TPS25730_I2C_SCL: J5.2, R8.2, U3.9 (I2CT_SCL)
TPS25730_I2C_SDA: J5.1, R7.2, U3.8 (I2CT_SDA)

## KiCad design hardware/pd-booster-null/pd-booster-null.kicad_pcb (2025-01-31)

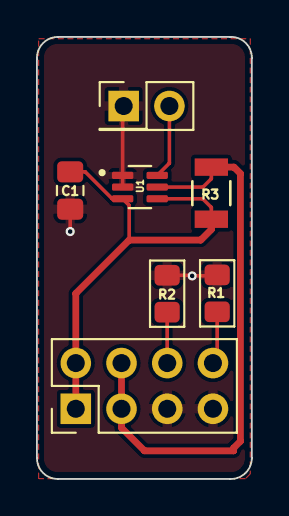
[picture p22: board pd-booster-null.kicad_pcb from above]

Board: 2 copper layers, 11.9 x 24.6 mm, 7 parts (0 on the bottom side), 6 nets.

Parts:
C1: 0.1uF; C_0805_2012Metric_Pad1.18x1.45mm_HandSolder
J1: 2x4 male 0.1"; PinHeader_2x04_P2.54mm_Vertical
J2: PH1RB-02-UA; PinHeader_2x01_P2.54mm_Vertical
R1, R2: 5.1k 1%; R_0805_2012Metric_Pad1.15x1.40mm_HandSolder
R3: 2mΩ 1% 1W; STA_CSNL1206_STP
U1: INA211BIDCKT; SOT65P210X110-6N

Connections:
/Pass-Thru/5V_OUT: J1.3, J1.4, R3.2, U1.5 (-IN)
/Pass-Thru/CC1: J1.6, R2.1
/Pass-Thru/CC2: J1.8, R1.1
/Pass-Thru/ISENSE: J2.2, U1.6 (OUT)
/Pass-Thru/VBUS_IN: C1.1, J1.1, J1.2, R3.1, U1.3 (V+), U1.4 (+IN)
GND: C1.2, J1.5, J1.7, J2.1, R1.2, R2.2, U1.1 (REF), U1.2 (GND)

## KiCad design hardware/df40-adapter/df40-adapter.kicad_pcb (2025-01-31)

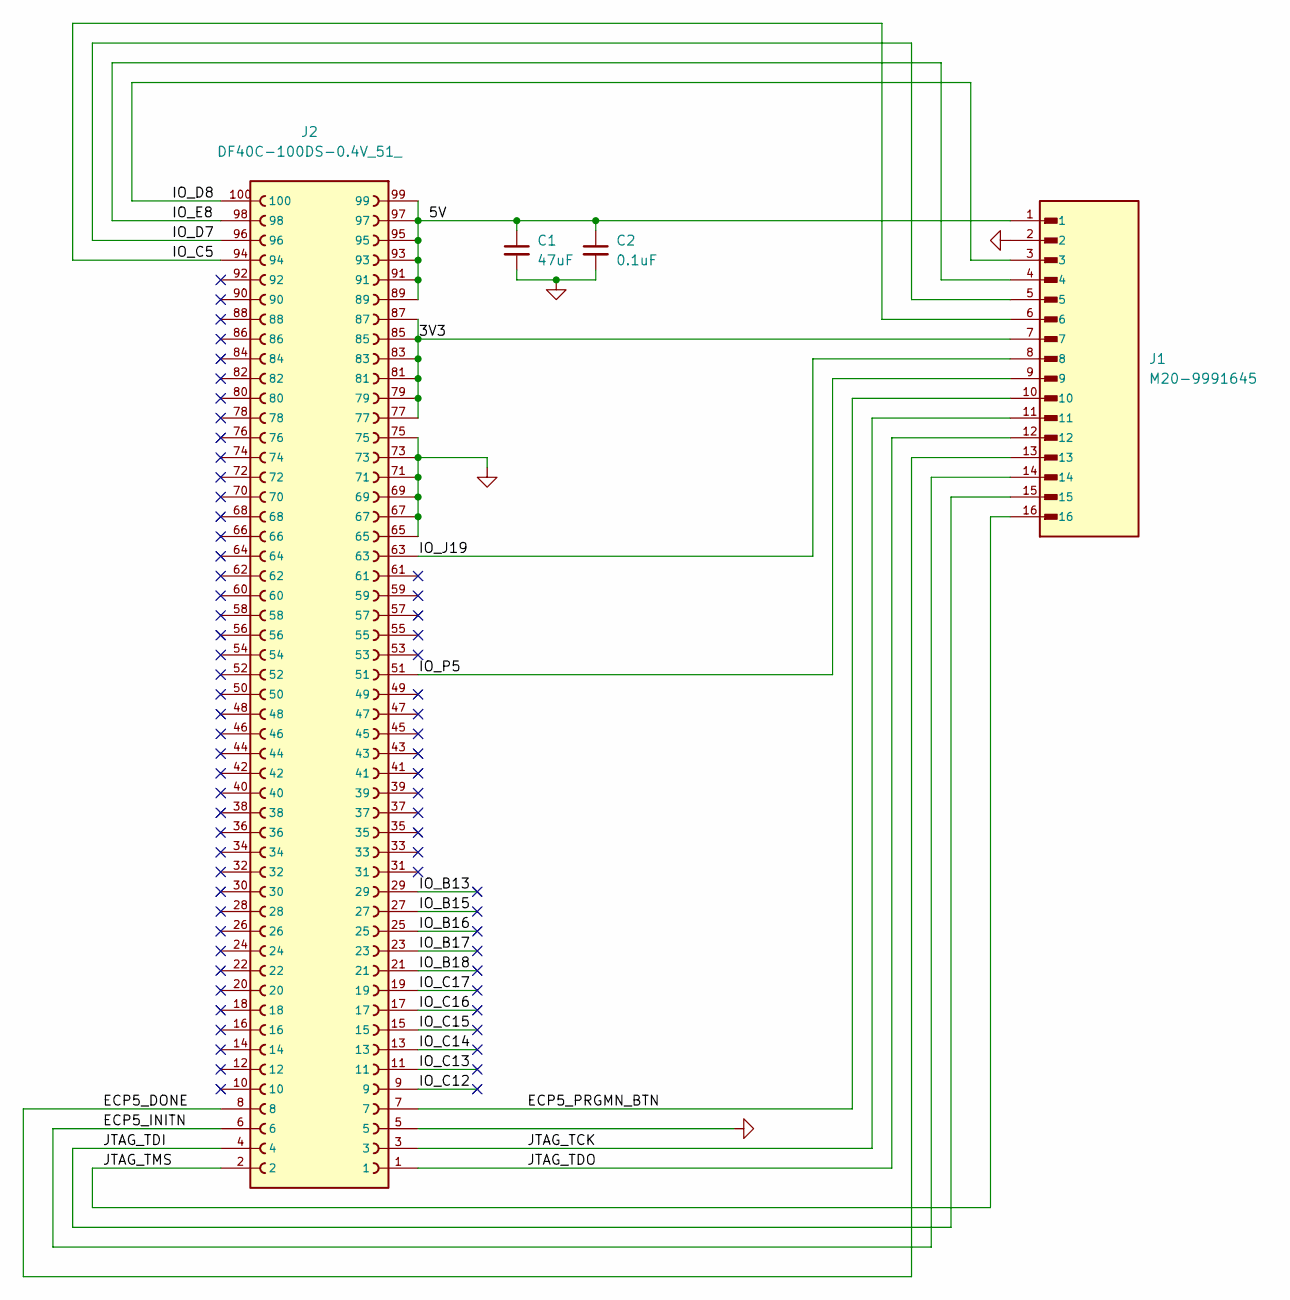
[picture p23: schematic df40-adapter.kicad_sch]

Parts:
C1: 47uF; C_0805_2012Metric_Pad1.18x1.45mm_HandSolder; MPN GRM21BR61A476ME15L
C2: 0.1uF; C_0805_2012Metric_Pad1.18x1.45mm_HandSolder; MPN CC0805KRX7R9BB104
J1: M20-9991645; HARWIN_M20-9991645; MPN M20-9991645
J2: DF40C-100DS-0.4V_51_; HIROSE_DF40C-100DS-0.4V_51_; PARTREV Oct.1.2023

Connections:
/3V3: J1.7, J2.77, J2.79, J2.81, J2.83, J2.85, J2.87
/5V: C1.1, C2.1, J1.1, J2.89, J2.91, J2.93, J2.95, J2.97, J2.99
/ECP5_DONE: J1.13, J2.8
/ECP5_INITN: J1.14, J2.6
/ECP5_PRGMN_BTN: J1.10, J2.7
/IO_B13: J2.29
/IO_B15: J2.27
/IO_B16: J2.25
/IO_B17: J2.23
/IO_B18: J2.21
/IO_C5: J1.6, J2.94
/IO_C12: J2.9
/IO_C13: J2.11
/IO_C14: J2.13
/IO_C15: J2.15
/IO_C16: J2.17
/IO_C17: J2.19
/IO_D7: J1.5, J2.96
/IO_D8: J1.3, J2.100
/IO_E8: J1.4, J2.98
/IO_J19: J1.8, J2.63
/IO_P5: J1.9, J2.51
/JTAG_TCK: J1.11, J2.3
/JTAG_TDI: J1.15, J2.4
/JTAG_TDO: J1.12, J2.1
/JTAG_TMS: J1.16, J2.2
GND: C1.2, C2.2, J1.2, J2.5, J2.65, J2.67, J2.69, J2.71, J2.73, J2.75

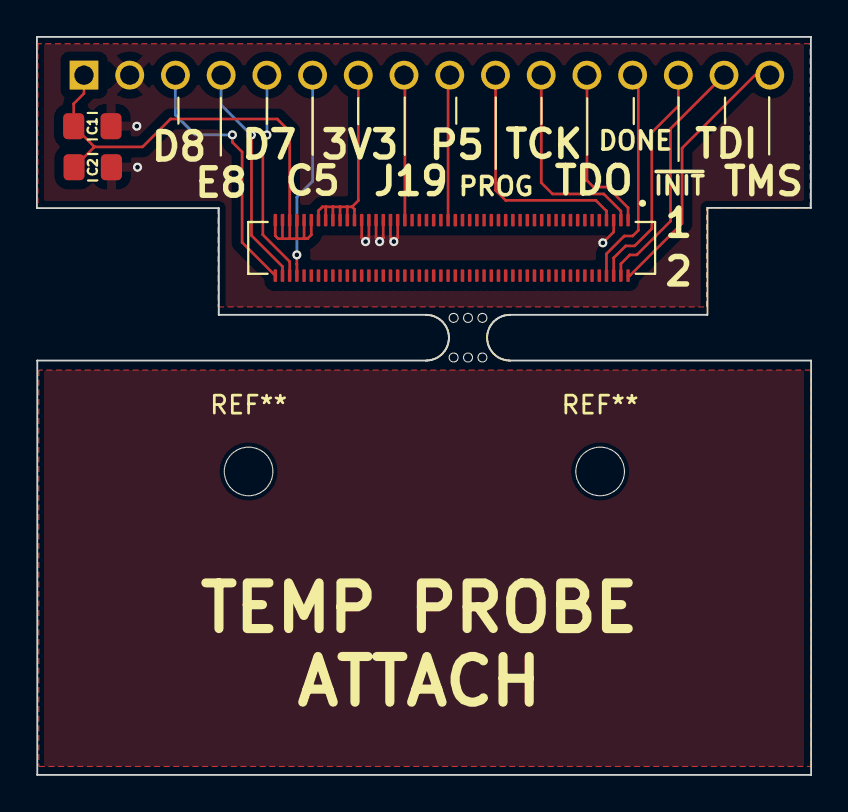
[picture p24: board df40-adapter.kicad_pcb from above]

Board: 2 copper layers, 43.0 x 41.0 mm, 5 parts (1 on the bottom side), 16 nets.

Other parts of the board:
mouse-bite-2.54mm-slot: VAL**; mouse-bite-2.54mm-slot

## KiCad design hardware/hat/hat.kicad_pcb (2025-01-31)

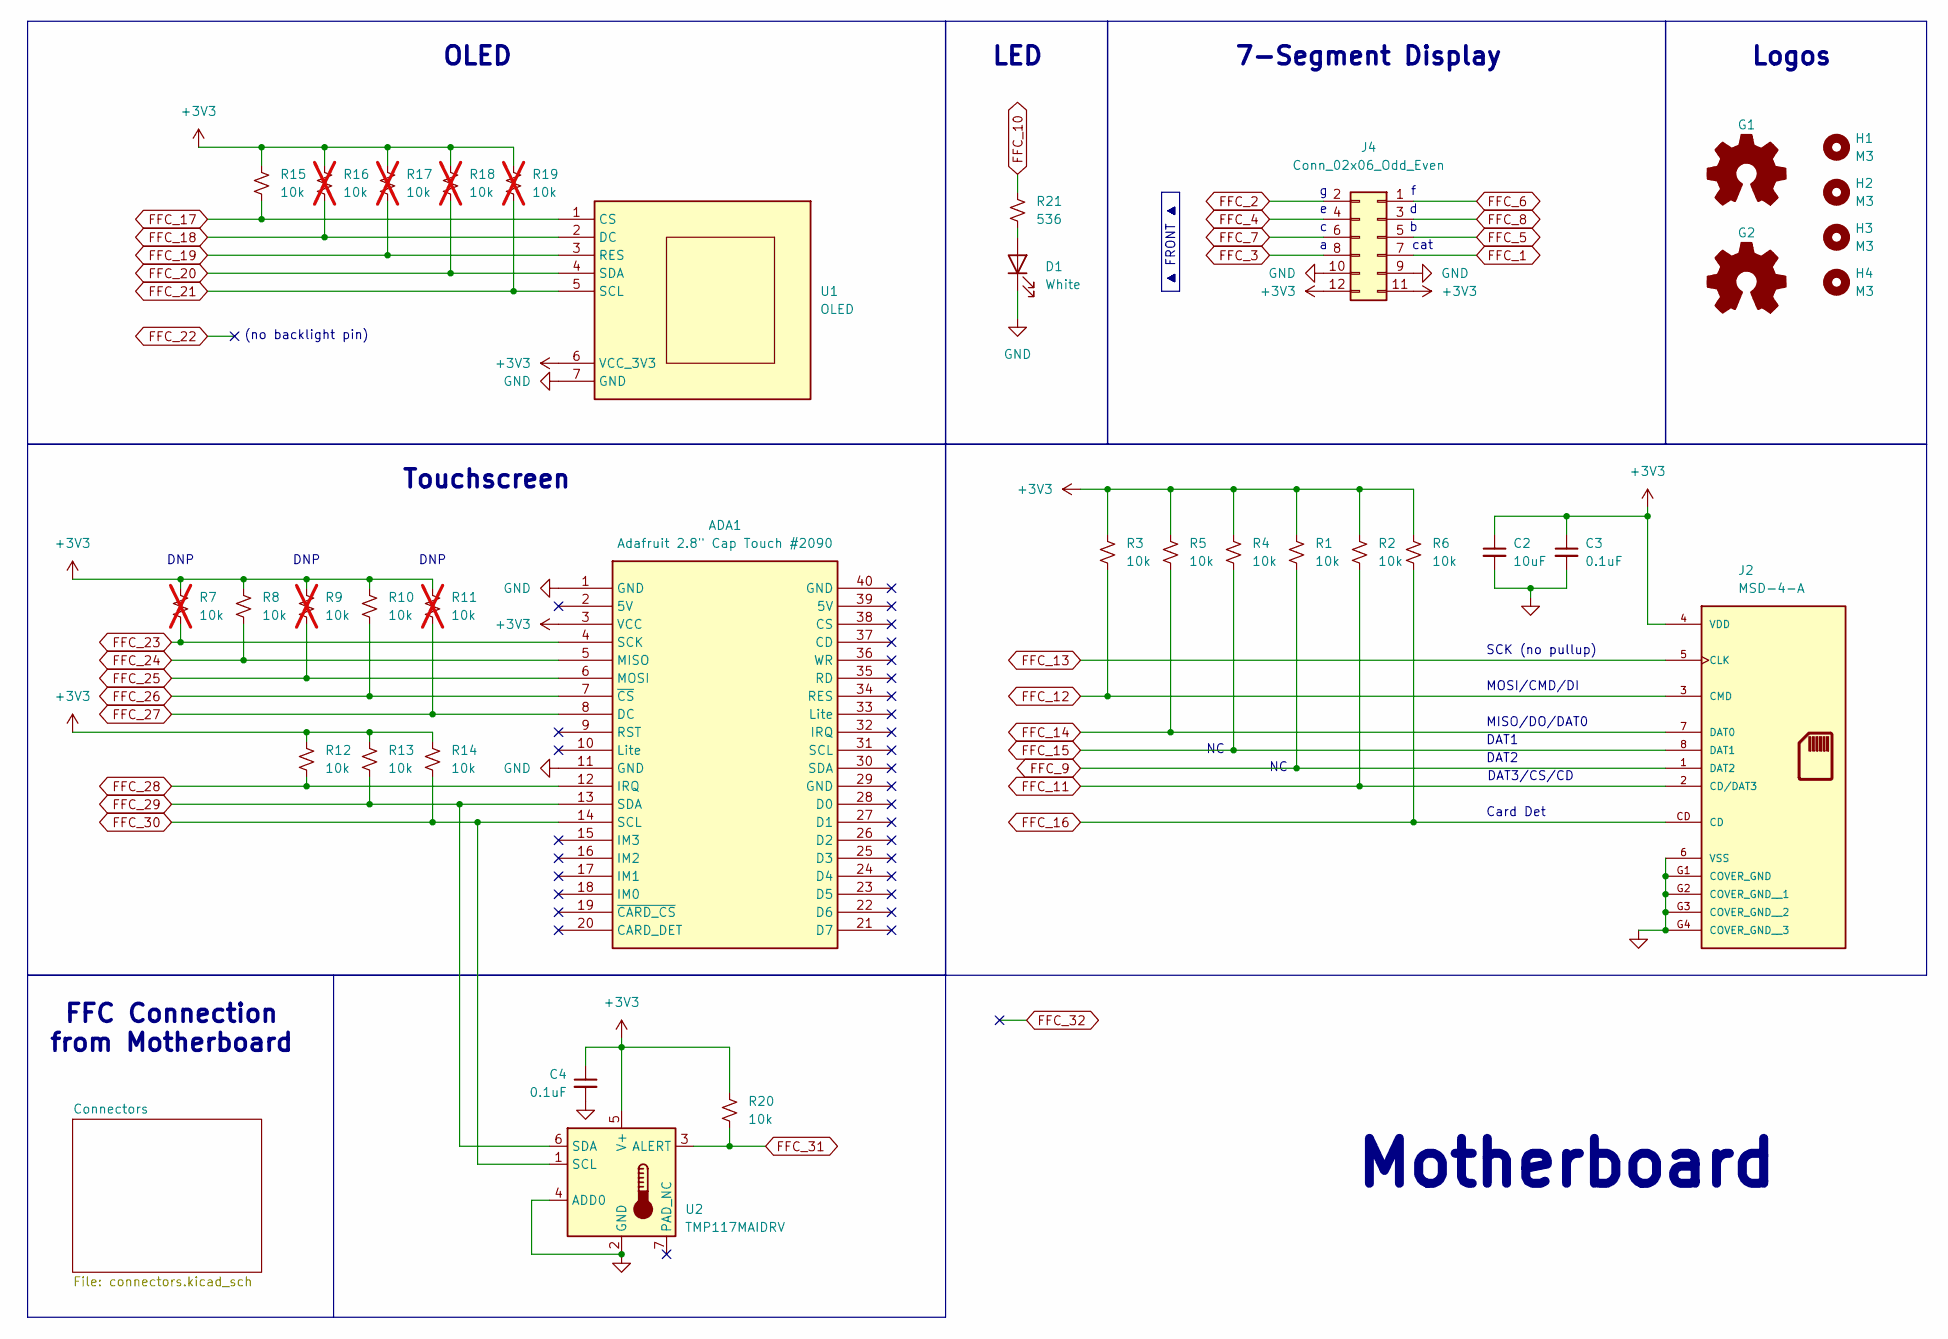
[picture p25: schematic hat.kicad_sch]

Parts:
ADA1: Adafruit 2.8" Cap Touch #2090; Adafruit 2.8 Cap Touchscreen (2090)
C2: 10uF; C_0603_1608Metric_Pad1.08x0.95mm_HandSolder; MPN GRM188R60J106ME47D
C3, C4: 0.1uF; C_0603_1608Metric_Pad1.08x0.95mm_HandSolder; MPN CC0603KRX7R7BB104
D1: White; QBLP631_White_LED_0805; MPN QBLP631-IW5
G1: Logo_Open_Hardware_Small; KiCad-Logo2_5mm_SilkScreen
G2: Logo_Open_Hardware_Small; OSHW-Logo2_14.6x12mm_SilkScreen
H1, H2, H3, H4: M3; MountingHole_3.2mm_M3; MPN 97790603111
J2: MSD-4-A; CUI_MSD-4-A; PARTREV 1.0
J4: Conn_02x06_Odd_Even; PinSocket_2x06_P2.54mm_Vertical
R1, R2, R3, R4, R5, R6, R8, R10, R12, R13, R14, R15, R20: 10k; R_0603_1608Metric_Pad1.05x0.95mm_HandSolder; MPN RC0603FR-0710KL
R7, R9, R11, R16, R17, R18, R19: 10k; R_0603_1608Metric_Pad1.05x0.95mm_HandSolder; MPN RC0603FR-0710KL; not fitted
R21: 536; R_0805_2012Metric_Pad1.15x1.40mm; MPN RC0805FR-07536RL
U1: OLED; OLED_0.95in_96x128_SPI_No_Bottom_Drill_Holes; MPN N/A
U2: TMP117MAIDRV; WSON-6-1EP_2x2mm_P0.65mm_EP1x1.6mm; MPN TMP117MAIDRVR

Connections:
+3V3: ADA1.3 (VCC), C2.1, C3.1, C4.1, J2.4 (VDD), J4.11, J4.12, R1.1, R2.1, R3.1, R4.1, R5.1, R6.1, R7.1, R8.1, R9.1, R10.1, R11.1, R12.1, R13.1, R14.1, R15.1, R16.1, R17.1, R18.1, R19.1, R20.1, U1.6 (VCC_3V3), U2.5 (V+); also elsewhere on the board
FFC_1: J4.7; also elsewhere on the board
FFC_2: J4.2; also elsewhere on the board
FFC_3: J4.8; also elsewhere on the board
FFC_4: J4.4; also elsewhere on the board
FFC_5: J4.5; also elsewhere on the board
FFC_6: J4.1; also elsewhere on the board
FFC_7: J4.6; also elsewhere on the board
FFC_8: J4.3; also elsewhere on the board
FFC_9: J2.1 (DAT2), R1.2; also elsewhere on the board
FFC_10: R21.1; also elsewhere on the board
FFC_11: J2.2 (CD/DAT3), R2.2; also elsewhere on the board
FFC_12: J2.3 (CMD), R3.2; also elsewhere on the board
FFC_13: J2.5 (CLK); also elsewhere on the board
FFC_14: J2.7 (DAT0), R5.2; also elsewhere on the board
FFC_15: J2.8 (DAT1), R4.2; also elsewhere on the board
FFC_16: J2.CD, R6.2; also elsewhere on the board
FFC_17: R15.2, U1.1 (CS); also elsewhere on the board
FFC_18: R16.2, U1.2 (DC); also elsewhere on the board
FFC_19: R17.2, U1.3 (RES); also elsewhere on the board
FFC_20: R18.2, U1.4 (SDA); also elsewhere on the board
FFC_21: R19.2, U1.5 (SCL); also elsewhere on the board
FFC_23: ADA1.4 (SCK), R7.2; also elsewhere on the board
FFC_24: ADA1.5 (MISO), R8.2; also elsewhere on the board
FFC_25: ADA1.6 (MOSI), R9.2; also elsewhere on the board
FFC_26: ADA1.7 (~CS), R10.2; also elsewhere on the board
FFC_27: ADA1.8 (DC), R11.2; also elsewhere on the board
FFC_28: ADA1.12 (IRQ), R12.2; also elsewhere on the board
FFC_29: ADA1.13 (SDA), R13.2, U2.6 (SDA); also elsewhere on the board
FFC_30: ADA1.14 (SCL), R14.2, U2.1 (SCL); also elsewhere on the board
FFC_31: R20.2, U2.3 (ALERT); also elsewhere on the board
GND: ADA1.1 (GND), ADA1.11 (GND), C2.2, C3.2, C4.2, D1.2 (K), J2.6 (VSS), J2.G1 (COVER_GND), J2.G2 (COVER_GND__1), J2.G3 (COVER_GND__2), J2.G4 (COVER_GND__3), J4.9, J4.10, U1.7 (GND), U2.2 (GND), U2.4 (ADD0); also elsewhere on the board
unnamed: D1.1 (A), R21.2

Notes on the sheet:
DNP
Logos
FFC Connection from Motherboard
MOSI/CMD/DI
7-Segment Display
LED
DAT2
Touchscreen
DAT1
▲ FRONT ▲
MISO/DO/DAT0
SCK (no pullup)
DAT3/CS/CD
Card Det
cat
Motherboard
OLED
(no backlight pin)

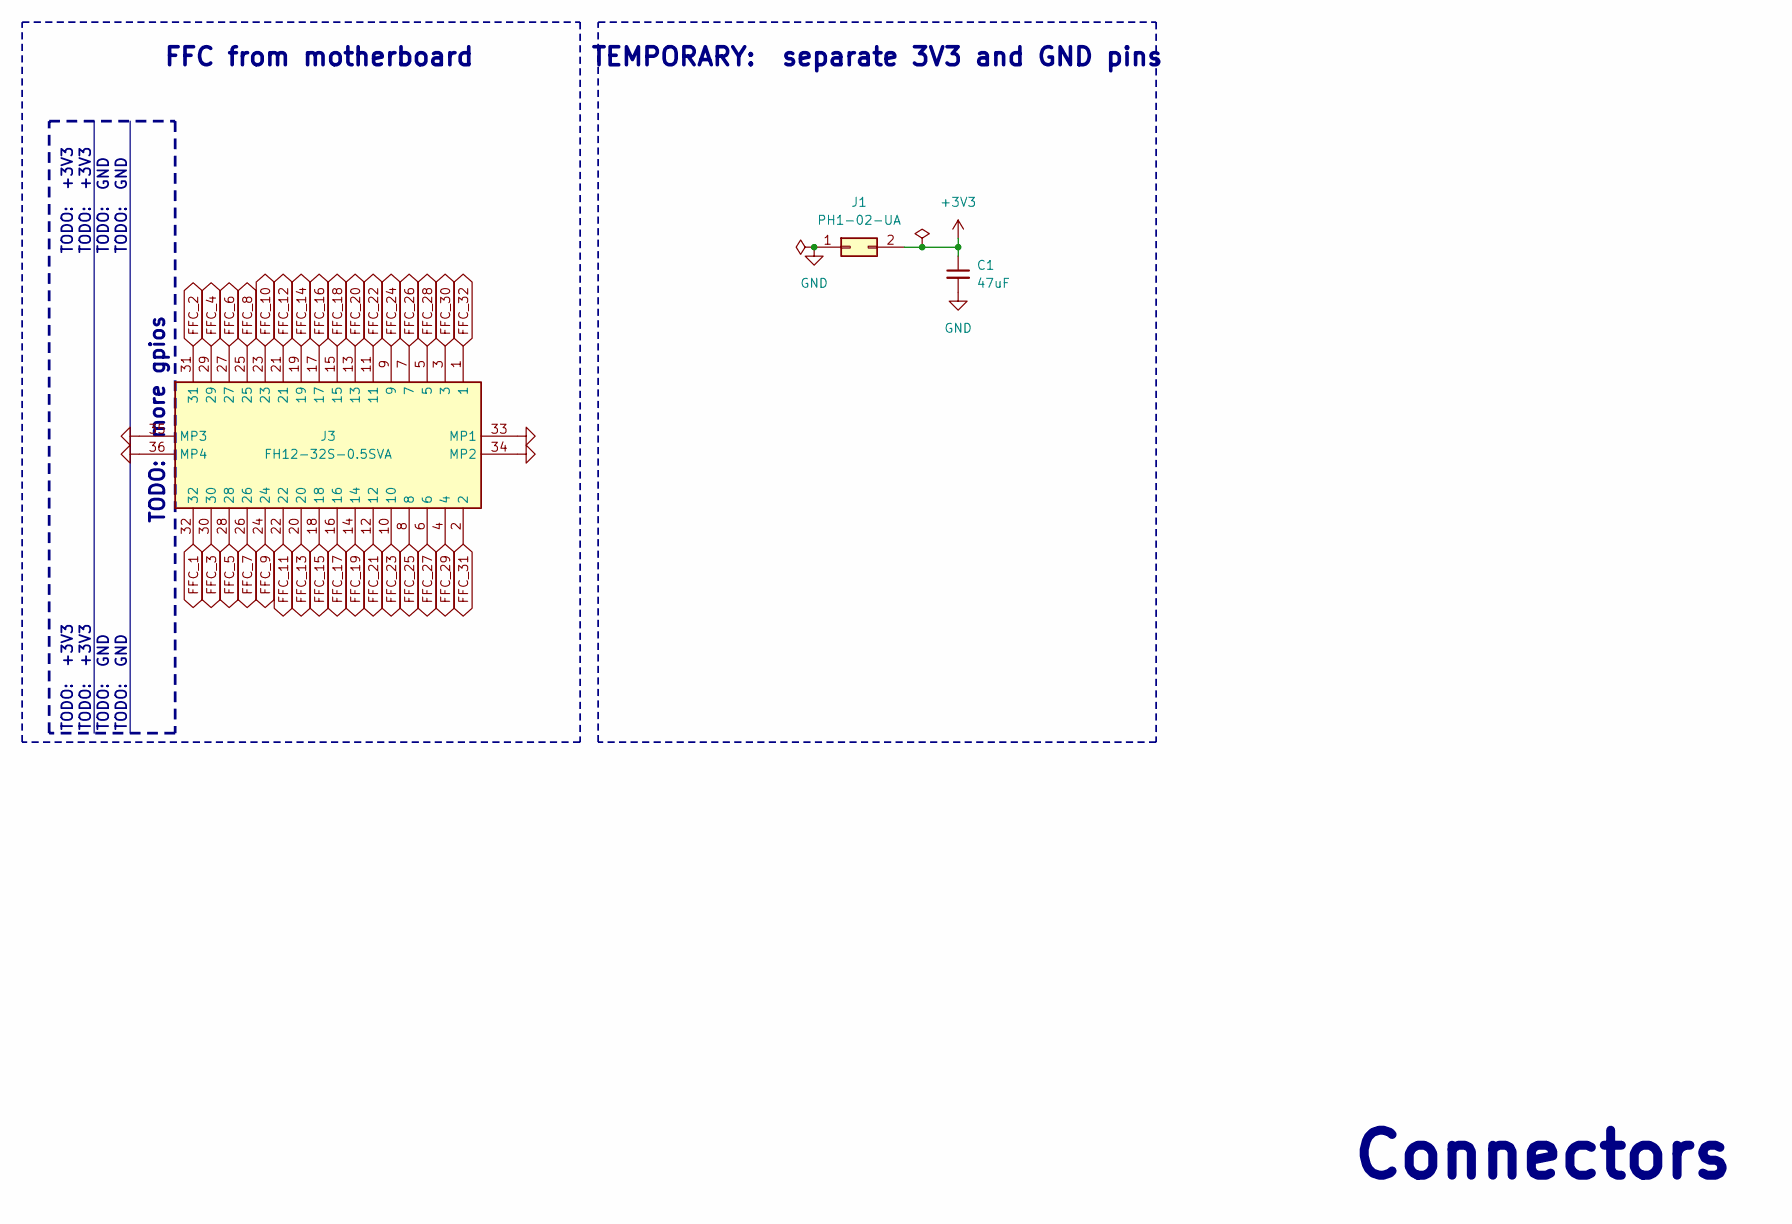
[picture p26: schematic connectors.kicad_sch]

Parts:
C1: 47uF; C_0603_1608Metric_Pad1.08x0.95mm_HandSolder; MPN GRM188R60J476ME15D
J1: PH1-02-UA; PinHeader_2x01_P2.54mm_Vertical; MPN PH1-02-UA
J3: FH12-32S-0.5SVA; FH1232S05SVA54; Mouser Part Number 798-FH1232S0.5SVA54

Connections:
+3V3: C1.1, J1.2; also elsewhere on the board
FFC_1: J3.32; also elsewhere on the board
FFC_2: J3.31; also elsewhere on the board
FFC_3: J3.30; also elsewhere on the board
FFC_4: J3.29; also elsewhere on the board
FFC_5: J3.28; also elsewhere on the board
FFC_6: J3.27; also elsewhere on the board
FFC_7: J3.26; also elsewhere on the board
FFC_8: J3.25; also elsewhere on the board
FFC_9: J3.24; also elsewhere on the board
FFC_10: J3.23; also elsewhere on the board
FFC_11: J3.22; also elsewhere on the board
FFC_12: J3.21; also elsewhere on the board
FFC_13: J3.20; also elsewhere on the board
FFC_14: J3.19; also elsewhere on the board
FFC_15: J3.18; also elsewhere on the board
FFC_16: J3.17; also elsewhere on the board
FFC_17: J3.16; also elsewhere on the board
FFC_18: J3.15; also elsewhere on the board
FFC_19: J3.14; also elsewhere on the board
FFC_20: J3.13; also elsewhere on the board
FFC_21: J3.12; also elsewhere on the board
FFC_22: J3.11
FFC_23: J3.10; also elsewhere on the board
FFC_24: J3.9; also elsewhere on the board
FFC_25: J3.8; also elsewhere on the board
FFC_26: J3.7; also elsewhere on the board
FFC_27: J3.6; also elsewhere on the board
FFC_28: J3.5; also elsewhere on the board
FFC_29: J3.4; also elsewhere on the board
FFC_30: J3.3; also elsewhere on the board
FFC_31: J3.2; also elsewhere on the board
FFC_32: J3.1
GND: C1.2, J1.1, J3.33 (MP1), J3.34 (MP2), J3.35 (MP3), J3.36 (MP4); also elsewhere on the board

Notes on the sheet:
FFC from motherboard
TODO: GND
TODO: +3V3
TEMPORARY: separate 3V3 and GND pins
TODO: more gpios
Connectors

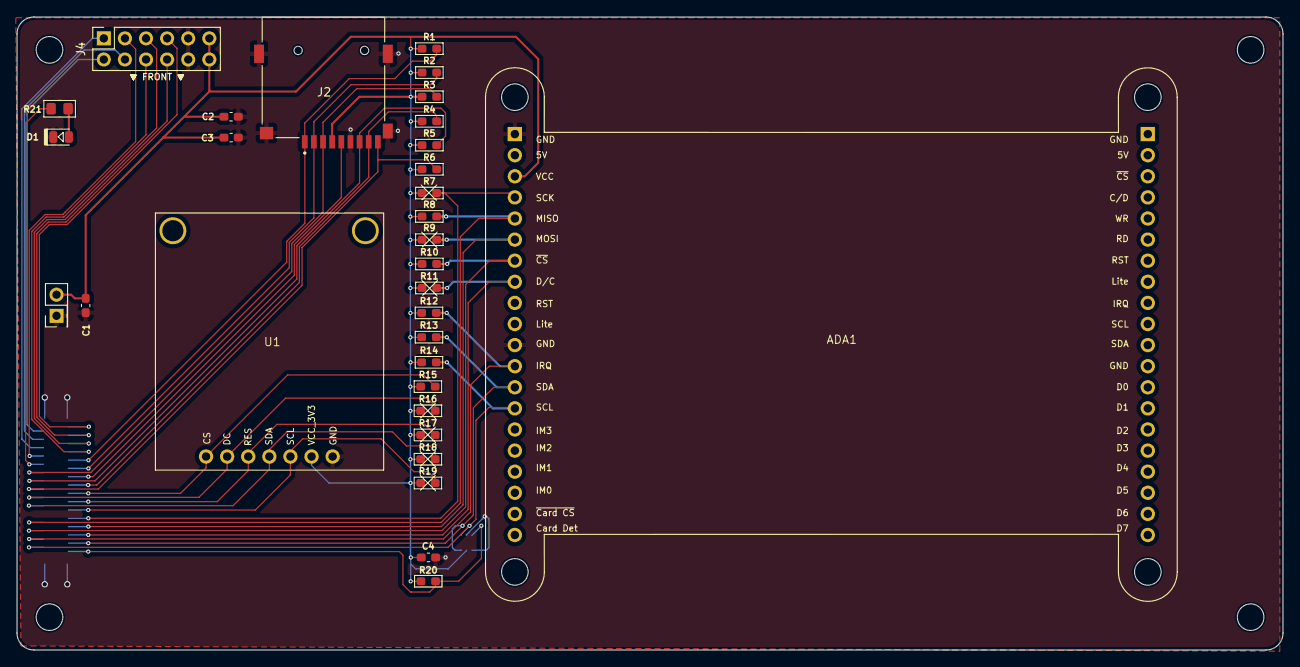
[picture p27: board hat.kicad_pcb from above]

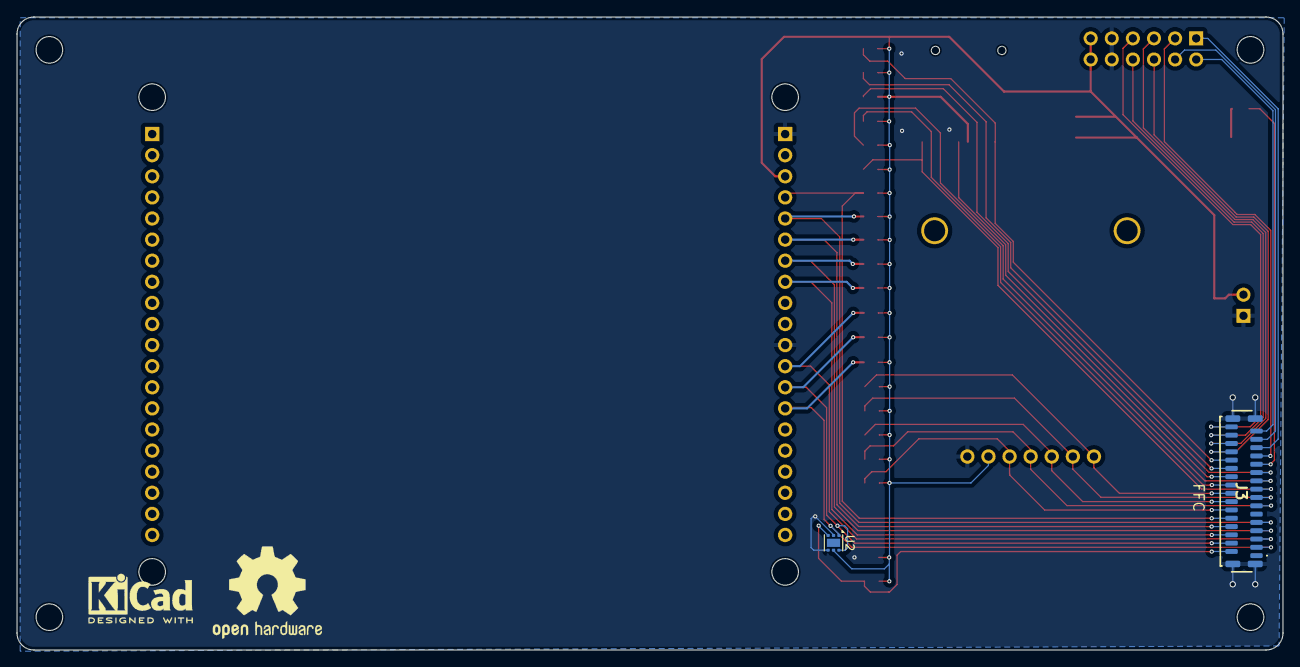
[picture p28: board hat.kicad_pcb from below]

Board: 2 copper layers, 152.4 x 76.2 mm, 39 parts (4 on the bottom side), 33 nets.

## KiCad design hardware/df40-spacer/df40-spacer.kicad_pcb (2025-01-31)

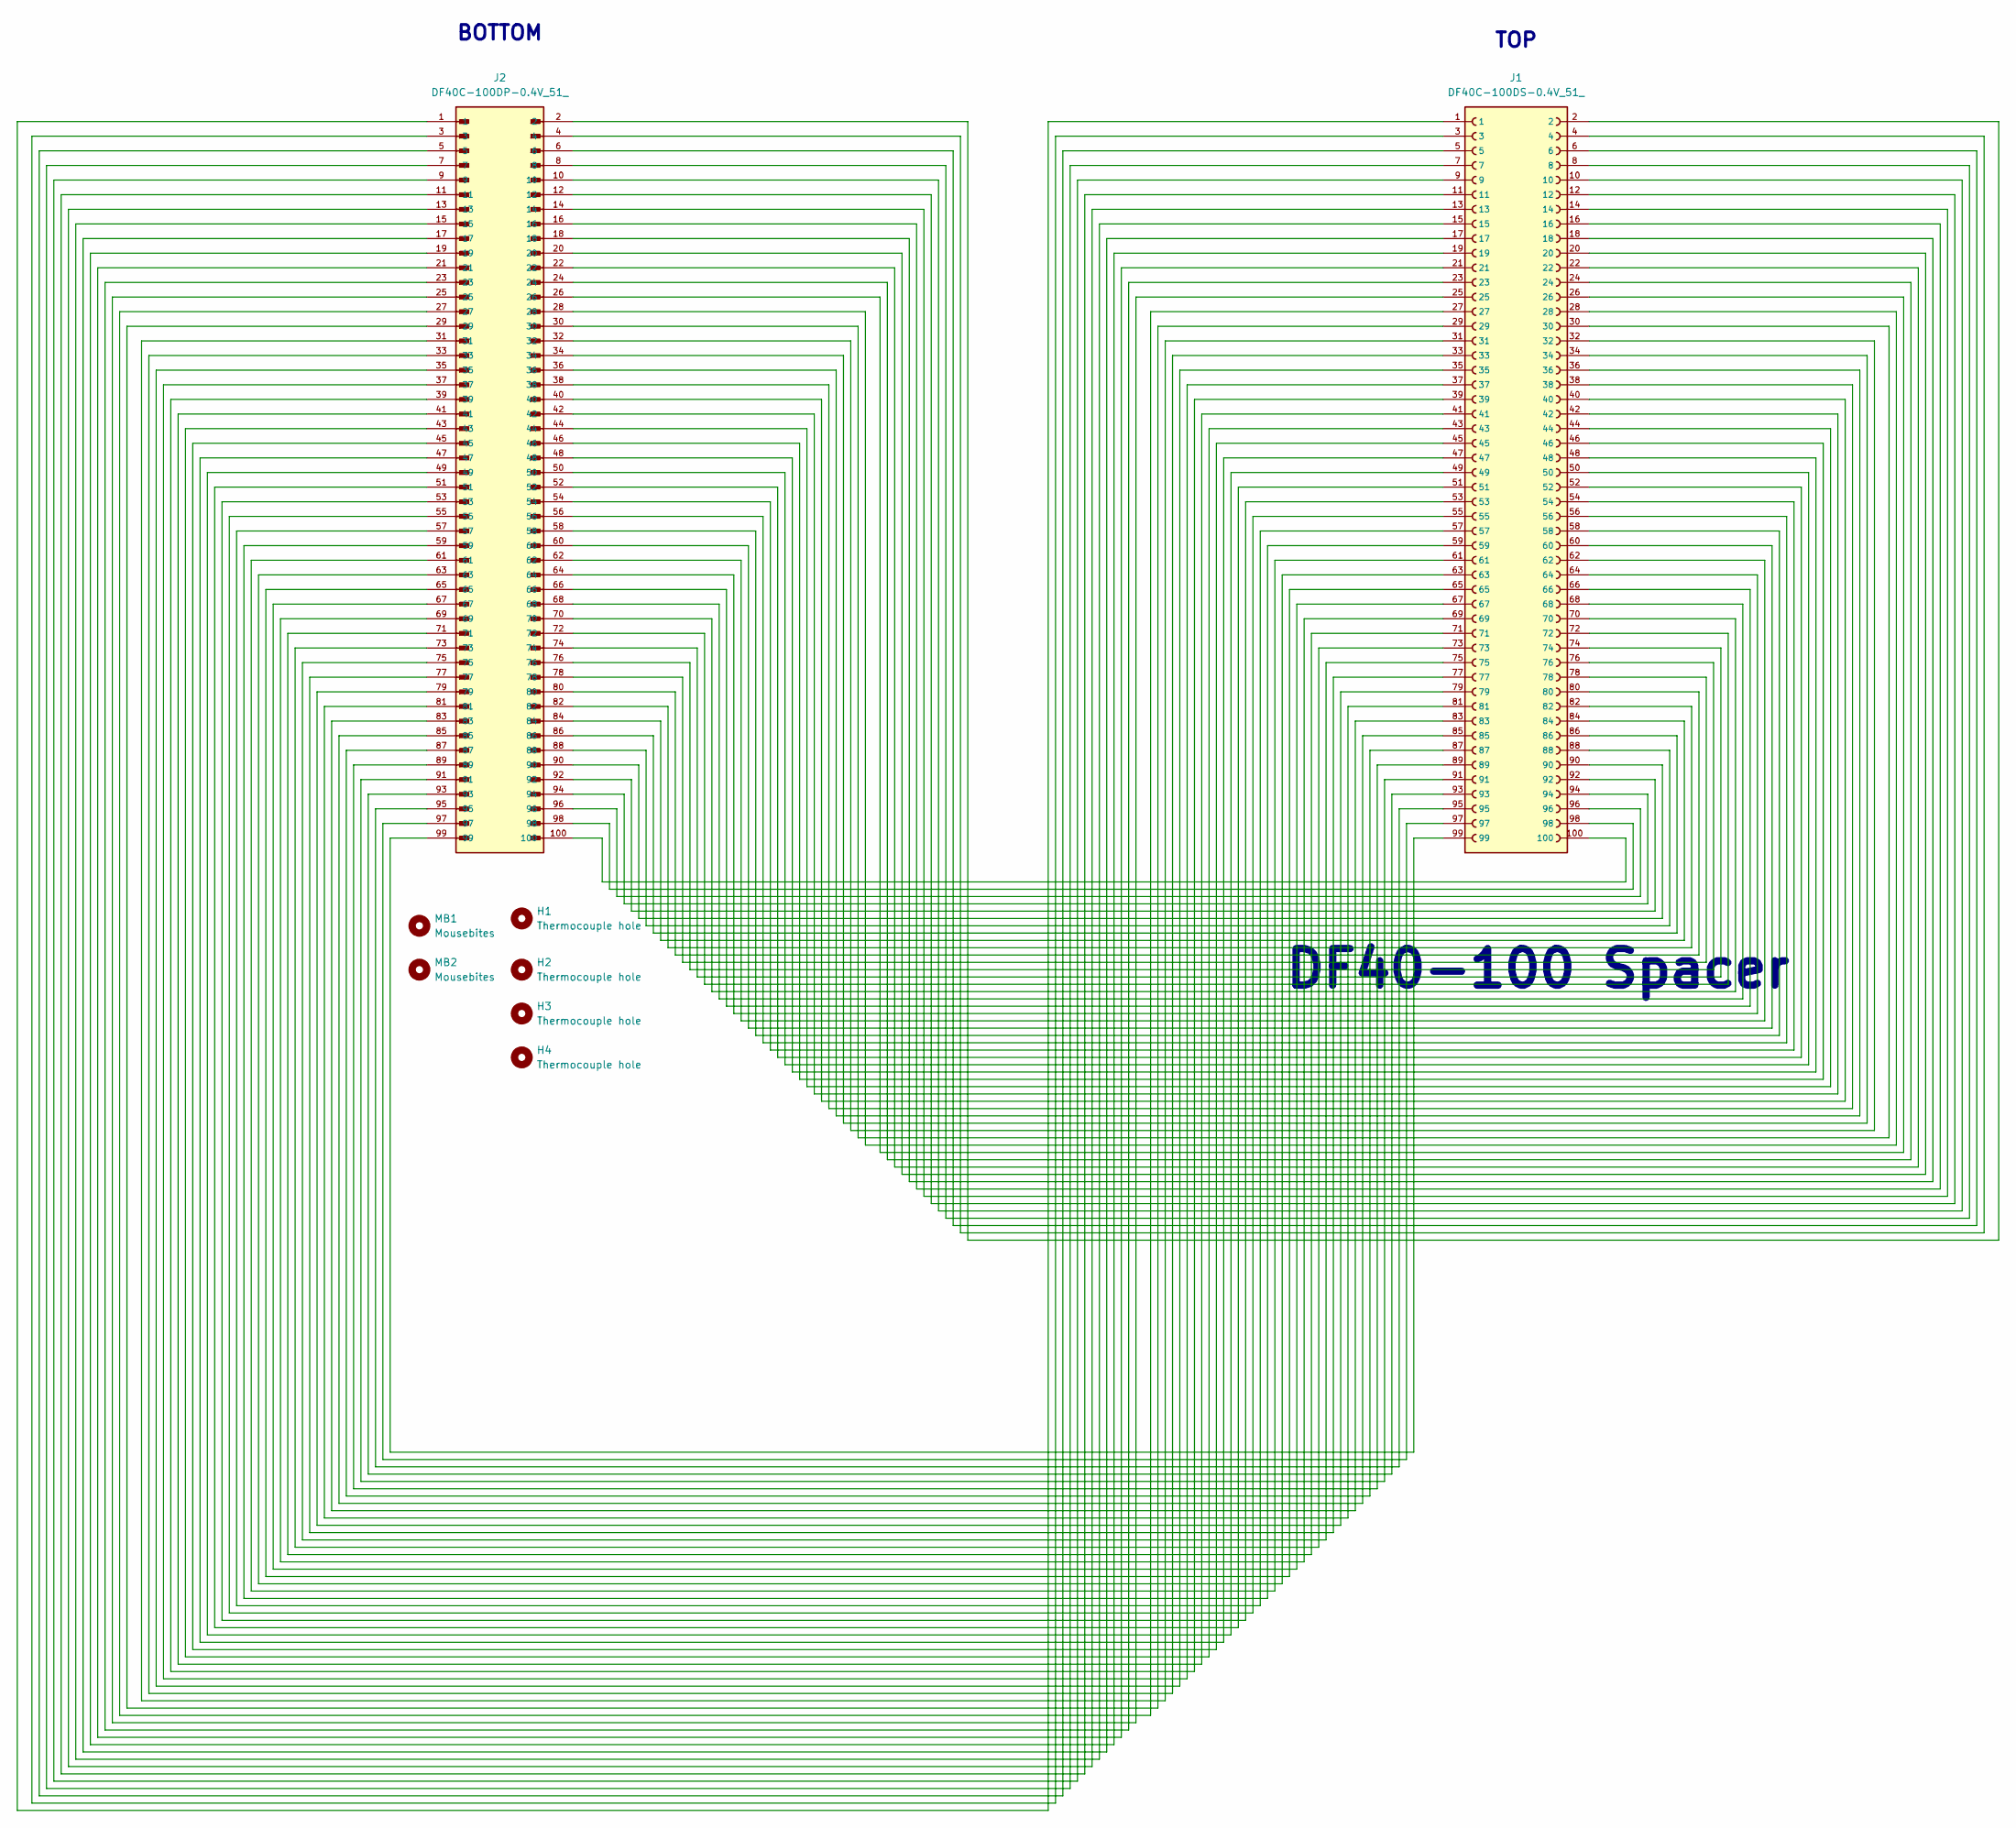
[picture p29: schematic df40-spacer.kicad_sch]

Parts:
H1, H2, H3, H4: Thermocouple hole; MountingHole_2.7mm_M2.5
J1: DF40C-100DS-0.4V_51_; HIROSE_DF40C-100DS-0.4V_51_; PARTREV Oct.1.2023
J2: DF40C-100DP-0.4V_51_; HIROSE_DF40C-100DP-0.4V_51_; MPN DF40C-100DP-0.4V(51)
MB1, MB2: Mousebites; mouse-bite-2.54mm-slot

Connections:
unnamed: J1.1, J2.1
unnamed: J1.2, J2.2
unnamed: J1.3, J2.3
unnamed: J1.4, J2.4
unnamed: J1.5, J2.5
unnamed: J1.6, J2.6
unnamed: J1.7, J2.7
unnamed: J1.8, J2.8
unnamed: J1.9, J2.9
unnamed: J1.10, J2.10
unnamed: J1.11, J2.11
unnamed: J1.12, J2.12
unnamed: J1.13, J2.13
unnamed: J1.14, J2.14
unnamed: J1.15, J2.15
unnamed: J1.16, J2.16
unnamed: J1.17, J2.17
unnamed: J1.18, J2.18
unnamed: J1.19, J2.19
unnamed: J1.20, J2.20
unnamed: J1.21, J2.21
unnamed: J1.22, J2.22
unnamed: J1.23, J2.23
unnamed: J1.24, J2.24
unnamed: J1.25, J2.25
unnamed: J1.26, J2.26
unnamed: J1.27, J2.27
unnamed: J1.28, J2.28
unnamed: J1.29, J2.29
unnamed: J1.30, J2.30
unnamed: J1.31, J2.31
unnamed: J1.32, J2.32
unnamed: J1.33, J2.33
unnamed: J1.34, J2.34
unnamed: J1.35, J2.35
unnamed: J1.36, J2.36
unnamed: J1.37, J2.37
unnamed: J1.38, J2.38
unnamed: J1.39, J2.39
unnamed: J1.40, J2.40
unnamed: J1.41, J2.41
unnamed: J1.42, J2.42
unnamed: J1.43, J2.43
unnamed: J1.44, J2.44
unnamed: J1.45, J2.45
unnamed: J1.46, J2.46
unnamed: J1.47, J2.47
unnamed: J1.48, J2.48
unnamed: J1.49, J2.49
unnamed: J1.50, J2.50
unnamed: J1.51, J2.51
unnamed: J1.52, J2.52
unnamed: J1.53, J2.53
unnamed: J1.54, J2.54
unnamed: J1.55, J2.55
unnamed: J1.56, J2.56
unnamed: J1.57, J2.57
unnamed: J1.58, J2.58
unnamed: J1.59, J2.59
unnamed: J1.60, J2.60
unnamed: J1.61, J2.61
unnamed: J1.62, J2.62
unnamed: J1.63, J2.63
unnamed: J1.64, J2.64
unnamed: J1.65, J2.65
unnamed: J1.66, J2.66
unnamed: J1.67, J2.67
unnamed: J1.68, J2.68
unnamed: J1.69, J2.69
unnamed: J1.70, J2.70
unnamed: J1.71, J2.71
unnamed: J1.72, J2.72
unnamed: J1.73, J2.73
unnamed: J1.74, J2.74
unnamed: J1.75, J2.75
unnamed: J1.76, J2.76
unnamed: J1.77, J2.77
unnamed: J1.78, J2.78
unnamed: J1.79, J2.79
unnamed: J1.80, J2.80
unnamed: J1.81, J2.81
unnamed: J1.82, J2.82
unnamed: J1.83, J2.83
unnamed: J1.84, J2.84
unnamed: J1.85, J2.85
unnamed: J1.86, J2.86
unnamed: J1.87, J2.87
unnamed: J1.88, J2.88
unnamed: J1.89, J2.89
unnamed: J1.90, J2.90
unnamed: J1.91, J2.91
unnamed: J1.92, J2.92
unnamed: J1.93, J2.93
unnamed: J1.94, J2.94
unnamed: J1.95, J2.95
unnamed: J1.96, J2.96
unnamed: J1.97, J2.97
unnamed: J1.98, J2.98
unnamed: J1.99, J2.99
unnamed: J1.100, J2.100

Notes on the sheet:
DF40-100 Spacer
TOP
BOTTOM

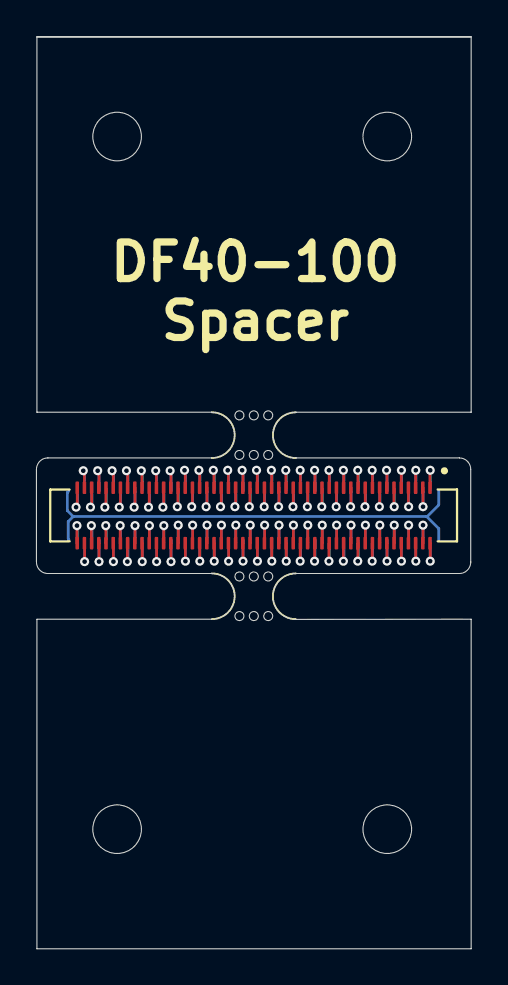
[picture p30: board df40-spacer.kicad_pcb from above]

Board: 2 copper layers, 24.2 x 50.7 mm, 8 parts (1 on the bottom side), 100 nets.

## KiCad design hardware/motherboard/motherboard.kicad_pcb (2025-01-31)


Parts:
G1: Logo_Open_Hardware_Small; KiCad-Logo2_5mm_SilkScreen
G2: Logo_Open_Hardware_Small; OSHW-Logo2_14.6x12mm_SilkScreen
H1, H2, H3, H4: M3; MountingHole_3.2mm_M3; MPN 97790603111

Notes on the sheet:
Motherboard


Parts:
C8, C10: 0.1uF; C_0805_2012Metric_Pad1.18x1.45mm_HandSolder; MPN CC0805KRX7R9BB104
D9: Yellow/PROG; LED_0805_2012Metric_Pad1.15x1.40mm_HandSolder; MPN 150080YS75000
D10: Green/RUN; LED_0805_2012Metric_Pad1.15x1.40mm_HandSolder; MPN 150080VS75000
NT1: NetTie_2; Solder_Jumper_Cuttable_6mil
R61, R62: 10K; R_0805_2012Metric_Pad1.15x1.40mm_HandSolder; MPN RC0805FR-0710KL
R63: 1K; R_0805_2012Metric_Pad1.15x1.40mm_HandSolder; MPN RC0805FR-071KL
U4: W25Q128JVSIQ; SOIC-8_5.23x5.23mm_P1.27mm; MPN W25Q128JVSIQ
U8, U10: TMUX1574PWR; SOP65P640X120-16N; MPN TMUX1574PWR

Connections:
+3V3: C8.1, C10.1, R61.1, R62.1, R63.1, U4.8 (VCC), U8.16 (VDD), U10.16 (VDD); also elsewhere on the board
/SPI Flash/~PROG: NT1.2, R62.2, U8.1 (SEL), U10.1 (SEL)
FLASH_PROG_CS: U8.2 (S1A); also elsewhere on the board
FLASH_PROG_IO0: U10.2 (S1A); also elsewhere on the board
FLASH_PROG_IO1: U10.5 (S2A); also elsewhere on the board
FLASH_PROG_SCK: U8.5 (S2A); also elsewhere on the board
FLASH_RUN_CS: U8.3 (S1B); also elsewhere on the board
FLASH_RUN_IO0: U10.3 (S1B); also elsewhere on the board
FLASH_RUN_IO1: U10.6 (S2B); also elsewhere on the board
FLASH_RUN_IO2: U10.10 (S3B); also elsewhere on the board
FLASH_RUN_IO3: U10.13 (S4B); also elsewhere on the board
FLASH_RUN_SCK: U8.6 (S2B); also elsewhere on the board
GND: C8.2, C10.2, D9.1 (K), D10.1 (K), U4.4 (GND), U8.8 (GND), U8.12 (D4), U8.13 (S4B), U8.14 (S4A), U8.15 (~EN), U10.8 (GND), U10.15 (~EN); also elsewhere on the board
unnamed: D9.2 (A), U8.11 (S3A)
unnamed: D10.2 (A), U8.10 (S3B)
unnamed: U4.6 (CLK), U8.7 (D2)
unnamed: R61.2, U4.1 (~CS), U8.4 (D1)
unnamed: R63.2, U8.9 (D3)
unnamed: U4.5 (DI(IO0)), U10.4 (D1)
unnamed: U4.2 (DO(IO1)), U10.7 (D2)
unnamed: U4.3 (IO2), U10.9 (D3)
unnamed: U4.7 (IO3), U10.12 (D4)
~FLASH_PROG_SEL: NT1.1; also elsewhere on the board

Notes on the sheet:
(QSPI not used in program mode)
A Port = PROG Mode (flash to FTDI) B Port = RUN Mode (flash to FPGA) SEL not driven = RUN mode(default) SEL pulled down = PROG mode
Place close to U8
(MOSI)
NB: ~{PROG} is hard pulled up by default (run mode). FTDI pulls to GND for program mode.
(MISO)
(Cut trace = RUN mode always)
SPI Flash
Place close to U10


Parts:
U3: Goelzer_Compute_Module_Rev_1; MPN DF40C-100DS-0.4V(51)

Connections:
+3V3: U3.77 (3V3_OUT), U3.79 (3V3_OUT), U3.81 (3V3_OUT), U3.83 (3V3_OUT), U3.85 (3V3_OUT), U3.87 (3V3_OUT); also elsewhere on the board
+5V: U3.89 (5V_IN), U3.91 (5V_IN), U3.93 (5V_IN), U3.95 (5V_IN), U3.97 (5V_IN), U3.99 (5V_IN); also elsewhere on the board
BTN_1: U3.42 (IO_A13); also elsewhere on the board
BTN_2: U3.38 (IO_A15); also elsewhere on the board
BTN_3: U3.40 (IO_A14); also elsewhere on the board
BTN_4: U3.44 (IO_A12); also elsewhere on the board
DVI_CLK: U3.27 (IO_B15); also elsewhere on the board
DVI_DATA_0: U3.15 (IO_C15); also elsewhere on the board
DVI_DATA_1: U3.17 (IO_C16); also elsewhere on the board
DVI_DATA_2: U3.19 (IO_C17); also elsewhere on the board
DVI_DATA_3: U3.21 (IO_B18); also elsewhere on the board
DVI_DATA_4: U3.23 (IO_B17); also elsewhere on the board
DVI_DATA_5: U3.25 (IO_B16); also elsewhere on the board
DVI_DATA_6: U3.29 (IO_B13); also elsewhere on the board
DVI_DATA_7: U3.31 (IO_B12); also elsewhere on the board
DVI_DATA_8: U3.33 (IO_B11); also elsewhere on the board
DVI_DATA_9: U3.35 (IO_B10); also elsewhere on the board
DVI_DATA_10: U3.37 (IO_B9); also elsewhere on the board
DVI_DATA_11: U3.39 (IO_B8); also elsewhere on the board
DVI_DATA_12: U3.41 (IO_B6); also elsewhere on the board
DVI_DATA_13: U3.43 (IO_U19); also elsewhere on the board
DVI_DATA_14: U3.45 (IO_T19); also elsewhere on the board
DVI_DATA_15: U3.47 (IO_P19); also elsewhere on the board
DVI_DATA_16: U3.49 (IO_N19); also elsewhere on the board
DVI_DATA_17: U3.51 (IO_P5); also elsewhere on the board
DVI_DATA_18: U3.53 (IO_M19); also elsewhere on the board
DVI_DATA_19: U3.55 (IO_N5); also elsewhere on the board
DVI_DATA_20: U3.57 (IO_L19); also elsewhere on the board
DVI_DATA_21: U3.59 (IO_E7); also elsewhere on the board
DVI_DATA_22: U3.61 (IO_K19); also elsewhere on the board
DVI_DATA_23: U3.63 (IO_J19); also elsewhere on the board
DVI_DE: U3.13 (IO_C14); also elsewhere on the board
DVI_HSYNC: U3.11 (IO_C13); also elsewhere on the board
DVI_SCL: U3.12 (IO_P4); also elsewhere on the board
DVI_SDA: U3.10 (IO_P2); also elsewhere on the board
DVI_VSYNC: U3.9 (IO_C12); also elsewhere on the board
ECP5_DONE: U3.8 (ECP5_DONE); also elsewhere on the board
ECP5_INITN: U3.6 (ECP5_INITN); also elsewhere on the board
ECP5_PRGMN_BTN: U3.7 (ECP5_PRGMN_BTN); also elsewhere on the board
FFC_1: U3.113 (IO_R1); also elsewhere on the board
FFC_2: U3.117 (IO_P1); also elsewhere on the board
FFC_3: U3.121 (IO_N1); also elsewhere on the board
FFC_4: U3.125 (IO_M1); also elsewhere on the board
FFC_5: U3.129 (IO_L1); also elsewhere on the board
FFC_6: U3.133 (IO_K1); also elsewhere on the board
FFC_7: U3.135 (IO_J1); also elsewhere on the board
FFC_8: U3.139 (IO_H1); also elsewhere on the board
FFC_9: U3.143 (IO_G1); also elsewhere on the board
FFC_10: U3.147 (IO_F1); also elsewhere on the board
FFC_11: U3.149 (IO_F2); also elsewhere on the board
FFC_12: U3.151 (IO_E1); also elsewhere on the board
FFC_13: U3.153 (IO_E2); also elsewhere on the board
FFC_14: U3.155 (IO_D1); also elsewhere on the board
FFC_15: U3.157 (IO_D2); also elsewhere on the board
FFC_16: U3.159 (IO_C1); also elsewhere on the board
FFC_17: U3.163 (IO_B1); also elsewhere on the board
FFC_18: U3.167 (IO_B2); also elsewhere on the board
FFC_19: U3.72 (IO_K20); also elsewhere on the board
FFC_20: U3.70 (IO_L20); also elsewhere on the board
FFC_21: U3.68 (IO_M20); also elsewhere on the board
FFC_22: U3.66 (IO_N20); also elsewhere on the board
FFC_23: U3.64 (IO_P20); also elsewhere on the board
FFC_24: U3.62 (IO_R20); also elsewhere on the board
FFC_25: U3.60 (IO_T20); also elsewhere on the board
FFC_26: U3.58 (IO_U20); also elsewhere on the board
FFC_27: U3.56 (IO_A6); also elsewhere on the board
FFC_28: U3.54 (IO_A7); also elsewhere on the board
FFC_29: U3.52 (IO_A8); also elsewhere on the board
FFC_30: U3.50 (IO_A9); also elsewhere on the board
FFC_31: U3.48 (IO_A10); also elsewhere on the board
FFC_32: U3.46 (IO_A11); also elsewhere on the board
FLASH_RUN_CS: U3.14 (IO_N4); also elsewhere on the board
FLASH_RUN_IO0: U3.18 (IO_F19); also elsewhere on the board
FLASH_RUN_IO1: U3.20 (IO_F17); also elsewhere on the board
FLASH_RUN_IO2: U3.28 (IO_D18); also elsewhere on the board
FLASH_RUN_IO3: U3.26 (IO_D19); also elsewhere on the board
FLASH_RUN_SCK: U3.16 (NC); also elsewhere on the board
GND: U3.5 (GND), U3.65 (GND), U3.67 (GND), U3.69 (GND), U3.71 (GND), U3.73 (GND), U3.75 (GND); also elsewhere on the board
JTAG_TCK: U3.3 (JTAG_TCK); also elsewhere on the board
JTAG_TDI: U3.4 (JTAG_TDI); also elsewhere on the board
JTAG_TDO: U3.1 (JTAG_TDO); also elsewhere on the board
JTAG_TMS: U3.2 (JTAG_TMS); also elsewhere on the board
LED_BLUE: U3.30 (IO_E17); also elsewhere on the board
LED_GRN: U3.36 (IO_A16); also elsewhere on the board
LED_RED: U3.32 (IO_A18); also elsewhere on the board
LED_YELLOW: U3.34 (IO_A17); also elsewhere on the board
PMOD6_IO_1: U3.193 (IO_E10); also elsewhere on the board
PMOD6_IO_2: U3.195 (IO_D9); also elsewhere on the board
PMOD6_IO_3: U3.197 (IO_E11); also elsewhere on the board
PMOD6_IO_4: U3.199 (IO_D10); also elsewhere on the board
PMOD12_IO_0: U3.185 (IO_E9); also elsewhere on the board
PMOD12_IO_1: U3.187 (IO_E14); also elsewhere on the board
PMOD12_IO_2: U3.189 (IO_E13); also elsewhere on the board
PMOD12_IO_3: U3.191 (IO_E15); also elsewhere on the board
PMOD12_IO_4: U3.183 (IO_A5); also elsewhere on the board
PMOD12_IO_5: U3.179 (IO_A4); also elsewhere on the board
PMOD12_IO_6: U3.175 (IO_A3); also elsewhere on the board
PMOD12_IO_7: U3.171 (IO_A2); also elsewhere on the board
UART1_RXD: U3.24 (IO_E18); also elsewhere on the board
UART1_TXD: U3.22 (IO_E19); also elsewhere on the board
VGA_BLUE_0: U3.100 (IO_A19); also elsewhere on the board
VGA_BLUE_1: U3.98 (IO_B19); also elsewhere on the board
VGA_BLUE_2: U3.96 (IO_D12); also elsewhere on the board
VGA_BLUE_3: U3.94 (IO_D13); also elsewhere on the board
VGA_GREEN_0: U3.80 (IO_F20); also elsewhere on the board
VGA_GREEN_1: U3.78 (IO_G20); also elsewhere on the board
VGA_GREEN_2: U3.76 (IO_H20); also elsewhere on the board
VGA_GREEN_3: U3.74 (IO_J20); also elsewhere on the board
VGA_HSYNC: U3.84 (IO_D20); also elsewhere on the board
VGA_RED_0: U3.92 (IO_D15); also elsewhere on the board
VGA_RED_1: U3.90 (IO_D14); also elsewhere on the board
VGA_RED_2: U3.88 (IO_B20); also elsewhere on the board
VGA_RED_3: U3.86 (IO_C20); also elsewhere on the board
VGA_VSYNC: U3.82 (IO_E20); also elsewhere on the board
XM1_1: U3.148 (IO_C3); also elsewhere on the board
XM1_2: U3.152 (IO_B3); also elsewhere on the board
XM1_3: U3.154 (IO_H3); also elsewhere on the board
XM1_4: U3.156 (IO_F4); also elsewhere on the board
XM1_5: U3.158 (IO_G3); also elsewhere on the board
XM1_6: U3.160 (IO_G5); also elsewhere on the board
XM1_7: U3.164 (IO_B5); also elsewhere on the board
XM1_8: U3.168 (IO_D5); also elsewhere on the board
XM1_9: U3.172 (IO_D6); also elsewhere on the board
XM1_11: U3.180 (IO_E5); also elsewhere on the board
XM1_12: U3.182 (IO_F4); also elsewhere on the board
XM1_13: U3.186 (IO_E4); also elsewhere on the board
XM1_14: U3.188 (IO_C4); also elsewhere on the board
XM1_15: U3.190 (IO_B4); also elsewhere on the board
XM1_16: U3.192 (IO_F5); also elsewhere on the board
XM1_17: U3.194 (IO_C5); also elsewhere on the board
XM1_18: U3.196 (IO_D7); also elsewhere on the board
XM1_19: U3.198 (IO_E8); also elsewhere on the board
XM1_20: U3.200 (IO_D8); also elsewhere on the board
XM1_21: U3.124 (IO_L2); also elsewhere on the board
XM1_22: U3.126 (IO_C11); also elsewhere on the board
XM1_23: U3.128 (IO_F3); also elsewhere on the board
XM1_24: U3.130 (IO_K2); also elsewhere on the board
XM1_25: U3.132 (IO_K3); also elsewhere on the board
XM1_26: U3.134 (IO_J3); also elsewhere on the board
XM1_27: U3.136 (IO_H2); also elsewhere on the board
XM1_28: U3.138 (IO_E3); also elsewhere on the board
XM1_29: U3.140 (IO_D3); also elsewhere on the board
XM1_30: U3.142 (IO_C2); also elsewhere on the board
XM2_1: U3.109 (IO_T1); also elsewhere on the board
XM2_2: U3.105 (IO_U1); also elsewhere on the board
XM2_3: U3.101 (IO_V1); also elsewhere on the board
XM2_4: U3.102 (IO_C10); also elsewhere on the board
XM2_5: U3.104 (IO_P3); also elsewhere on the board
XM2_6: U3.106 (IO_D11); also elsewhere on the board
XM2_7: U3.108 (IO_N2); also elsewhere on the board
XM2_8: U3.110 (IO_C9); also elsewhere on the board
XM2_9: U3.112 (IO_N3); also elsewhere on the board
XM2_10: U3.114 (IO_C8); also elsewhere on the board
XM2_11: U3.116 (IO_M3); also elsewhere on the board
XM2_12: U3.118 (IO_C7); also elsewhere on the board
XM2_13: U3.120 (IO_L3); also elsewhere on the board
XM2_14: U3.122 (IO_C6); also elsewhere on the board
XM110: U3.176 (IO_E6); also elsewhere on the board

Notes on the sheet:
Compute Module

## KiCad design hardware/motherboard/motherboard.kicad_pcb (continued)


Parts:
C9: 100pF; C_0805_2012Metric_Pad1.18x1.45mm_HandSolder; MPN CC0805KRX7R9BB101
C11: 470nF; C_0805_2012Metric_Pad1.18x1.45mm_HandSolder; MPN CC0805KKX7R8BB474
C25, C26, C31, C32, C33: 10uF; C_0805_2012Metric_Pad1.18x1.45mm_HandSolder; MPN CC0805KKX5R8BB106
C34, C35, C36, C37, C38, C39, C40, C41: 10nF; C_0805_2012Metric_Pad1.18x1.45mm_HandSolder; MPN CC0805KRX7R9BB103
FB4, FB5, FB6: 600Ω; L_0603_1608Metric_Pad1.05x0.95mm_HandSolder; MPN BLM18RK601SN1D
J4: HDMI_A; HDMI_A_Molex_208658-1001_Horizontal; MPN 2086581001
R45, R47, R48, R49: 2.2k; R_0805_2012Metric_Pad1.15x1.40mm_HandSolder; MPN RC0805FR-072K2L
R46: 200k; R_0805_2012Metric_Pad1.15x1.40mm_HandSolder; MPN RC0805FR-07200KL
R55: 510; R_0805_2012Metric_Pad1.15x1.40mm_HandSolder; MPN RC0805FR-07510RL
R56, R57: 1k; R_0805_2012Metric_Pad1.15x1.40mm_HandSolder; MPN RC0805FR-071KL
U5: TFP410PAP; HTQFP-64-1EP_10x10mm_P0.5mm_EP8x8mm_Mask4.4x4.4mm_ThermalVi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; MPN TFP410PAP
U9: PCA9306D; SO-8_3.9x4.9mm_P1.27mm; MPN PCA9306D,118
U11: TPS2041B; SOT-23-5; MPN TPS2041BDBVR
U12, U13: TPD4E02B04DQA; USON-10_2.5x1.0mm_P0.5mm; MPN TPD4E02B04DQAR

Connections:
+3V3: C11.1, FB4.1, FB5.1, FB6.1, R48.1, R49.1, R55.2, R57.1, U5.3 (VREF), U9.2 (VREF1); also elsewhere on the board
+5V: C25.1, R45.1, R46.1, R47.1, U11.5 (IN); also elsewhere on the board
/HDMI/DVI_DVDD: C32.1, C37.1, C38.1, C39.1, FB5.2, U5.1 (DVDD), U5.12 (DVDD), U5.33 (DVDD)
/HDMI/DVI_HPD: J4.19 (HPD), R56.1
/HDMI/DVI_PVDD: C31.1, C34.1, C35.1, C36.1, FB4.2, U5.18 (PVDD)
/HDMI/DVI_RECEP_SCL: J4.15 (SCL), R45.2, U9.6 (SCL2)
/HDMI/DVI_RECEP_SDA: J4.16 (SDA), R47.2, U9.5 (SDA2)
/HDMI/DVI_TVDD: C33.1, C40.1, C41.1, FB6.2, U5.23 (TVDD), U5.29 (TVDD)
/HDMI/HDMI_5V: C26.1, J4.18 (+5V), U11.1 (OUT)
/HDMI/TMDS_CLK+: J4.10 (CK+), U5.22 (TXC+), U13.4 (IO3), U13.7 (NC)
/HDMI/TMDS_CLK-: J4.12 (CK-), U5.21 (TXC-), U13.5 (IO4), U13.6 (NC)
/HDMI/TMDS_D0+: J4.7 (D0+), U5.25 (TX0+), U13.1 (IO1), U13.10 (NC)
/HDMI/TMDS_D0-: J4.9 (D0-), U5.24 (TX0-), U13.2 (IO2), U13.9 (NC)
/HDMI/TMDS_D1+: J4.4 (D1+), U5.28 (TX1+), U12.4 (IO3), U12.7 (NC)
/HDMI/TMDS_D1-: J4.6 (D1-), U5.27 (TX1-), U12.5 (IO4), U12.6 (NC)
/HDMI/TMDS_D2+: J4.1 (D2+), U5.31 (TX2+), U12.1 (IO1), U12.10 (NC)
/HDMI/TMDS_D2-: J4.3 (D2-), U5.30 (TX2-), U12.2 (IO2), U12.9 (NC)
DVI_CLK: U5.57 (IDCK+); also elsewhere on the board
DVI_DATA_0: U5.63 (DATA0); also elsewhere on the board
DVI_DATA_1: U5.62 (DATA1); also elsewhere on the board
DVI_DATA_2: U5.61 (DATA2); also elsewhere on the board
DVI_DATA_3: U5.60 (DATA3); also elsewhere on the board
DVI_DATA_4: U5.59 (DATA4); also elsewhere on the board
DVI_DATA_5: U5.58 (DATA5); also elsewhere on the board
DVI_DATA_6: U5.55 (DATA6); also elsewhere on the board
DVI_DATA_7: U5.54 (DATA7); also elsewhere on the board
DVI_DATA_8: U5.53 (DATA8); also elsewhere on the board
DVI_DATA_9: U5.52 (DATA9); also elsewhere on the board
DVI_DATA_10: U5.51 (DATA10); also elsewhere on the board
DVI_DATA_11: U5.50 (DATA11); also elsewhere on the board
DVI_DATA_12: U5.47 (DATA12); also elsewhere on the board
DVI_DATA_13: U5.46 (DATA13); also elsewhere on the board
DVI_DATA_14: U5.45 (DATA14); also elsewhere on the board
DVI_DATA_15: U5.44 (DATA15); also elsewhere on the board
DVI_DATA_16: U5.43 (DATA16); also elsewhere on the board
DVI_DATA_17: U5.42 (DATA17); also elsewhere on the board
DVI_DATA_18: U5.41 (DATA18); also elsewhere on the board
DVI_DATA_19: U5.40 (DATA19); also elsewhere on the board
DVI_DATA_20: U5.39 (DATA20); also elsewhere on the board
DVI_DATA_21: U5.38 (DATA21); also elsewhere on the board
DVI_DATA_22: U5.37 (DATA22); also elsewhere on the board
DVI_DATA_23: U5.36 (DATA23); also elsewhere on the board
DVI_DE: U5.2 (DE); also elsewhere on the board
DVI_HSYNC: U5.4 (HSYNC); also elsewhere on the board
DVI_SCL: R49.2, U5.15 (BSEL/SCL), U9.3 (SCL1); also elsewhere on the board
DVI_SDA: R48.2, U5.14 (DSEL/SDA), U9.4 (SDA1); also elsewhere on the board
DVI_VSYNC: U5.5 (VSYNC); also elsewhere on the board
GND: C9.2, C11.2, C25.2, C26.2, C31.2, C32.2, C33.2, C34.2, C35.2, C36.2, C37.2, C38.2, C39.2, C40.2, C41.2, J4.2 (D2S), J4.5 (D1S), J4.8 (D0S), J4.11 (CKS), J4.17 (GND), J4.SH, U5.6 (CTL3/A3/DK3), U5.7 (CTL2/A2/DK2), U5.8 (CTL1/A1/DK1), U5.10 (~PD), U5.16 (DGND), U5.17 (PGND), U5.20 (TGND), U5.26 (TGND), U5.32 (TGND), U5.34 (RESERVED), U5.35 (DKEN), U5.48 (DGND), U5.56 (IDCK-), U5.64 (DGND), U5.65 (EP), U9.1 (GND), U11.2 (GND), U11.4 (~EN), U12.3 (G), U12.8 (G), U13.3 (G), U13.8 (G); also elsewhere on the board
unnamed: R56.2, U5.9 (EDGE/HTPLG)
unnamed: R57.2, U5.13 (ISEL/~RST)
unnamed: R55.1, U5.19 (TFADJ)
unnamed: C9.1, R46.2, U9.7 (VREF2), U9.8 (EN)

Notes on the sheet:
HDMI
Place close to DVDD pins (1,12,33)
Place close to TVDD pins (23,29)
Place close to PVDD pin (18)


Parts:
D2: Green; Wurth_150080xS7500_0805; MPN 150080VS75000
D3: Yellow; Wurth_150080xS7500_0805; MPN 150080YS75000
D4: Red; Wurth_150080xS7500_0805; MPN 150080SS75000
D5: Blue; Wurth_150080xS7500_0805; MPN 150080BS75000
R42, R44, R50: 536; R_0805_2012Metric_Pad1.15x1.40mm; MPN RC0805FR-07536RL
R51: 270; R_0805_2012Metric_Pad1.15x1.40mm; MPN RC0805FR-07270RL
R53, R54, R58, R59: 3.3k; R_0805_2012Metric_Pad1.15x1.40mm; MPN RC0805FR-073K3L
S1, S2, S3, S4: PTS645SL50SMTR92LFS; PTS645SMT; Mouser Part Number 611-PTS645SL50SMTR92

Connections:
+3V3: R53.1, R54.1, R58.1, R59.1; also elsewhere on the board
BTN_1: S1.3, S1.4; also elsewhere on the board
BTN_2: S2.3, S2.4; also elsewhere on the board
BTN_3: S3.3, S3.4; also elsewhere on the board
BTN_4: S4.3, S4.4; also elsewhere on the board
GND: D2.1 (K), D3.1 (K), D4.1 (K), D5.1 (K); also elsewhere on the board
LED_BLUE: R51.1; also elsewhere on the board
LED_GRN: R42.1; also elsewhere on the board
LED_RED: R50.1; also elsewhere on the board
LED_YELLOW: R44.1; also elsewhere on the board
unnamed: D2.2 (A), R42.2
unnamed: D3.2 (A), R44.2
unnamed: D4.2 (A), R50.2
unnamed: D5.2 (A), R51.2
unnamed: R53.2, S1.1, S1.2
unnamed: R54.2, S2.1, S2.2
unnamed: R58.2, S3.1, S3.2
unnamed: R59.2, S4.1, S4.2

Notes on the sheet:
Misc I/O


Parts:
J3: FH12-32S-0.5SVA; FH1232S05SVA54; Mouser Part Number 798-FH1232S0.5SVA54
J6: PMOD_6; MPN PH1RB-06-UA
J7: PMOD_12; MPN PH2RA-12-UA
J8: Conn_02x03; CONN_PH2-06-UA_ADM; MPN PH2-06-UA
J9: Conn_01x03; PinHeader_1x03_P2.54mm_Vertical; MPN PH1-03-UA
XM1: Expansion Module (30 IOs); XM30
XM2: Expansion Module (14 IOs); XM14

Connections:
+3V3: J6.6 (VCC), J7.6 (VCC), J7.12 (VCC), J8.2 (+12V), XM1.32 (3V3), XM1.34 (3V3), XM1.36 (3V3), XM1.38 (3V3), XM1.40 (3V3), XM2.2 (3V3), XM2.4 (3V3), XM2.6 (3V3); also elsewhere on the board
+5V: XM1.10 (5V); also elsewhere on the board
ECP5_DONE: J9.2; also elsewhere on the board
ECP5_INITN: J9.3; also elsewhere on the board
ECP5_PRGMN_BTN: J9.1; also elsewhere on the board
FFC_1: J3.1; also elsewhere on the board
FFC_2: J3.2; also elsewhere on the board
FFC_3: J3.3; also elsewhere on the board
FFC_4: J3.4; also elsewhere on the board
FFC_5: J3.5; also elsewhere on the board
FFC_6: J3.6; also elsewhere on the board
FFC_7: J3.7; also elsewhere on the board
FFC_8: J3.8; also elsewhere on the board
FFC_9: J3.9; also elsewhere on the board
FFC_10: J3.10; also elsewhere on the board
FFC_11: J3.11; also elsewhere on the board
FFC_12: J3.12; also elsewhere on the board
FFC_13: J3.13; also elsewhere on the board
FFC_14: J3.14; also elsewhere on the board
FFC_15: J3.15; also elsewhere on the board
FFC_16: J3.16; also elsewhere on the board
FFC_17: J3.17; also elsewhere on the board
FFC_18: J3.18; also elsewhere on the board
FFC_19: J3.19; also elsewhere on the board
FFC_20: J3.20; also elsewhere on the board
FFC_21: J3.21; also elsewhere on the board
FFC_22: J3.22; also elsewhere on the board
FFC_23: J3.23; also elsewhere on the board
FFC_24: J3.24; also elsewhere on the board
FFC_25: J3.25; also elsewhere on the board
FFC_26: J3.26; also elsewhere on the board
FFC_27: J3.27; also elsewhere on the board
FFC_28: J3.28; also elsewhere on the board
FFC_29: J3.29; also elsewhere on the board
FFC_30: J3.30; also elsewhere on the board
FFC_31: J3.31; also elsewhere on the board
FFC_32: J3.32; also elsewhere on the board
GND: J3.33 (MP1), J3.34 (MP2), J3.35 (MP3), J3.36 (MP4), J6.5 (GND), J7.5 (GND), J7.11 (GND), J8.1 (+12V), XM1.2 (GND), XM1.4 (GND), XM1.6 (GND), XM1.8 (GND), XM1.G1 (GND), XM1.G2 (GND), XM1.G3 (GND), XM1.G4 (GND), XM1.G5 (GND), XM1.G6 (GND), XM1.G7 (GND), XM1.G8 (GND), XM2.16 (GND), XM2.18 (GND), XM2.20 (GND); also elsewhere on the board
JTAG_TCK: J8.4 (GND); also elsewhere on the board
JTAG_TDI: J8.3 (GND); also elsewhere on the board
JTAG_TDO: J8.6 (GND); also elsewhere on the board
JTAG_TMS: J8.5 (GND); also elsewhere on the board
PMOD6_IO_1: J6.1 (IO1); also elsewhere on the board
PMOD6_IO_2: J6.2 (IO2); also elsewhere on the board
PMOD6_IO_3: J6.3 (IO3); also elsewhere on the board
PMOD6_IO_4: J6.4 (IO4); also elsewhere on the board
PMOD12_IO_0: J7.1 (IO0); also elsewhere on the board
PMOD12_IO_1: J7.2 (IO1); also elsewhere on the board
PMOD12_IO_2: J7.3 (IO2); also elsewhere on the board
PMOD12_IO_3: J7.4 (IO3); also elsewhere on the board
PMOD12_IO_4: J7.7 (IO4); also elsewhere on the board
PMOD12_IO_5: J7.8 (IO5); also elsewhere on the board
PMOD12_IO_6: J7.9 (IO6); also elsewhere on the board
PMOD12_IO_7: J7.10 (IO7); also elsewhere on the board
XM1_1: XM1.1 (IO_1); also elsewhere on the board
XM1_2: XM1.3 (IO_2); also elsewhere on the board
XM1_3: XM1.5 (IO_3); also elsewhere on the board
XM1_4: XM1.7 (IO_4); also elsewhere on the board
XM1_5: XM1.9 (IO_5); also elsewhere on the board
XM1_6: XM1.11 (IO_6); also elsewhere on the board
XM1_7: XM1.13 (IO_7); also elsewhere on the board
XM1_8: XM1.15 (IO_8); also elsewhere on the board
XM1_9: XM1.17 (IO_9); also elsewhere on the board
XM1_11: XM1.21 (IO_11); also elsewhere on the board
XM1_12: XM1.23 (IO_12); also elsewhere on the board
XM1_13: XM1.25 (IO_13); also elsewhere on the board
XM1_14: XM1.27 (IO_14); also elsewhere on the board
XM1_15: XM1.29 (IO_15); also elsewhere on the board
XM1_16: XM1.31 (IO_16); also elsewhere on the board
XM1_17: XM1.33 (IO_17); also elsewhere on the board
XM1_18: XM1.35 (IO_18); also elsewhere on the board
XM1_19: XM1.37 (IO_19); also elsewhere on the board
XM1_20: XM1.39 (IO_20); also elsewhere on the board
XM1_21: XM1.30 (IO_21); also elsewhere on the board
XM1_22: XM1.28 (IO_22); also elsewhere on the board
XM1_23: XM1.26 (IO_23); also elsewhere on the board
XM1_24: XM1.24 (IO_24); also elsewhere on the board
XM1_25: XM1.22 (IO_25); also elsewhere on the board
XM1_26: XM1.20 (IO_26); also elsewhere on the board
XM1_27: XM1.18 (IO_27); also elsewhere on the board
XM1_28: XM1.16 (IO_28); also elsewhere on the board
XM1_29: XM1.14 (IO_29); also elsewhere on the board
XM1_30: XM1.12 (IO_30); also elsewhere on the board
XM2_1: XM2.19 (IO_1); also elsewhere on the board
XM2_2: XM2.17 (IO_2); also elsewhere on the board
XM2_3: XM2.15 (IO_3); also elsewhere on the board
XM2_4: XM2.13 (IO_4); also elsewhere on the board
XM2_5: XM2.11 (IO_5); also elsewhere on the board
XM2_6: XM2.9 (IO_6); also elsewhere on the board
XM2_7: XM2.7 (IO_7); also elsewhere on the board
XM2_8: XM2.5 (IO_8); also elsewhere on the board
XM2_9: XM2.3 (IO_9); also elsewhere on the board
XM2_10: XM2.1 (IO_10); also elsewhere on the board
XM2_11: XM2.8 (IO_11); also elsewhere on the board
XM2_12: XM2.10 (IO_12); also elsewhere on the board
XM2_13: XM2.12 (IO_13); also elsewhere on the board
XM2_14: XM2.14 (IO_14); also elsewhere on the board
XM110: XM1.19 (IO_10); also elsewhere on the board

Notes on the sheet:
FFC to Hat
TODO: GND
TODO: +3V3
Expansion Modules
PMODs
JTAG & Programming Pins
TODO: more gpios
Connectors


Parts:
C1, C2: 22uF; C_0805_2012Metric_Pad1.18x1.45mm_HandSolder; MPN C2012X5R1V226M125AC
C12, C13: 4.7uF; C_0805_2012Metric_Pad1.18x1.45mm_HandSolder; MPN CC0805KKX5R8BB475
C14, C16, C18, C19, C20, C21, C22, C23, C24: 0.1uF; C_0805_2012Metric_Pad1.18x1.45mm_HandSolder; MPN CC0805KRX7R9BB104
C15: 0.1uF; C_0805_2012Metric_Pad1.18x1.45mm_HandSolder
C17: 10uF; C_0805_2012Metric_Pad1.18x1.45mm_HandSolder; MPN CC0805KKX5R8BB106
D1: USBLC6-2SC6; SOT-23-6; MPN USBLC6-2SC6
D6: Amber; Wurth_150080xS7500_0805; MPN 150080AS75000
D7: White; QBLP631_White_LED_0805; MPN QBLP631-IW
D8: Green; Wurth_150080xS7500_0805; MPN 150080VS75000
FB1: 50Ω@100mhz 12A; L_1206_3216Metric_Pad1.42x1.75mm_HandSolder; MPN BLM31SN500SZ1L
FB2, FB3: 600/0.6A; L_0805_2012Metric_Pad1.15x1.40mm_HandSolder; MPN BLM21AG601SN1D
J1: USB4105GFA120; GCT_USB4105GFA120; MPN USB4105-GF-A-120
J2: Conn_02x04_Odd_Even; PinSocket_2x04_P2.54mm_Vertical; MPN RS2-08-G
R43, R60: 1k; R_0805_2012Metric_Pad1.15x1.40mm; MPN RC0805FR-071KL
R52: 536; R_0805_2012Metric_Pad1.15x1.40mm; MPN RC0805FR-07536RL
R64: 1k; R_0805_2012Metric_Pad1.15x1.40mm_HandSolder; MPN RC0805FR-071KL
R65: 12k; R_0805_2012Metric_Pad1.15x1.40mm_HandSolder; MPN RC0805FR-0712KL
R66, R67, R69: 10k; R_0805_2012Metric_Pad1.15x1.40mm_HandSolder; MPN RC0805FR-0710KL
R68: 2.2k; R_0805_2012Metric_Pad1.15x1.40mm_HandSolder; MPN RC0805FR-072K2L
U1: FT4232HL; LQFP-64_10x10mm_P0.5mm; MPN FT4232HL-REEL
U2: 93LC56BT-I/OT; SOT-23-6; MPN 93LC56BT-I/OT
Y1: ASEM1-12.000MHZ-LC-T; XTAL_ASEM1-12.000MHZ-LC-T; MPN ASEM1-12.000MHZ-LC-T

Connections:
+1V8: C17.2, C18.2, C20.2, C22.2, U1.12 (VCORE), U1.37 (VCORE), U1.49 (VREGOUT), U1.64 (VCORE)
+3V3: C15.2, C19.2, C21.2, C23.2, C24.2, FB2.1, FB3.1, R60.1, R64.1, R66.1, R67.1, R69.1, U1.20 (VCCIO), U1.31 (VCCIO), U1.42 (VCCIO), U1.50 (VREGIN), U1.56 (VCCIO), U2.6 (VCC), Y1.4 (VDD); also elsewhere on the board
+5V: J2.3, J2.4, R52.1; also elsewhere on the board
/USB-C Power & Debug Port/CC1: J1.A5 (CC1), J2.6
/USB-C Power & Debug Port/CC2: J1.B5 (CC2), J2.8
/USB-C Power & Debug Port/EECLK: R67.2, U1.62 (EECLK), U2.4 (CLK)
/USB-C Power & Debug Port/EECS: R69.2, U1.63 (EECS), U2.5 (CS)
/USB-C Power & Debug Port/EEDATA: R68.2, U1.61 (EEDATA), U2.3 (DI)
/USB-C Power & Debug Port/EEPROM_DO: R66.2, R68.1, U2.1 (DO)
/USB-C Power & Debug Port/OSCI: U1.2 (OSCI), Y1.3 (OUTPUT)
/USB-C Power & Debug Port/VBUS: C1.1, C2.1, D1.5 (VP), FB1.1, J1.A4_B9 (VBUS), J1.B4_A9 (VBUS__1)
/USB-C Power & Debug Port/VBUS_IN: FB1.2, J2.1, J2.2, R43.1
/USB-C Power & Debug Port/VPHY: C13.2, C16.2, FB3.2, U1.4 (VPHY)
/USB-C Power & Debug Port/VPLL: C12.2, C14.2, FB2.2, U1.9 (VPLL)
/USB-C Power & Debug Port/~RESET: R64.2, U1.14 (~RESET)
DM: D1.4 (L2), U1.7 (DM)
DP: D1.6 (L1), U1.8 (DP)
FLASH_PROG_CS: U1.29 (BDBUS3); also elsewhere on the board
FLASH_PROG_IO0: U1.27 (BDBUS1); also elsewhere on the board
FLASH_PROG_IO1: U1.28 (BDBUS2); also elsewhere on the board
FLASH_PROG_SCK: U1.26 (BDBUS0); also elsewhere on the board
GND: C1.2, C2.2, C12.1, C13.1, C14.1, C15.1, C16.1, C17.1, C18.1, C19.1, C20.1, C21.1, C22.1, C23.1, C24.1, D1.2 (VN), D6.1 (K), D7.2 (K), D8.1 (K), J1.A1_B12 (GND), J1.B1_A12 (GND__1), J1.SH1 (SHELL_GND), J1.SH2 (SHELL_GND__1), J1.SH3 (SHELL_GND__2), J1.SH4 (SHELL_GND__3), J2.5, J2.7, R65.2, U1.1 (GND), U1.5 (GND), U1.10 (AGND), U1.11 (GND), U1.13 (TEST), U1.15 (GND), U1.25 (GND), U1.35 (GND), U1.47 (GND), U1.51 (GND), U2.2 (GND), Y1.2 (GND); also elsewhere on the board
JTAG_TCK: U1.16 (ADBUS0); also elsewhere on the board
JTAG_TDI: U1.17 (ADBUS1); also elsewhere on the board
JTAG_TDO: U1.18 (ADBUS2); also elsewhere on the board
JTAG_TMS: U1.19 (ADBUS3); also elsewhere on the board
unnamed: D6.2 (A), R43.2
unnamed: D7.1 (A), R52.2
unnamed: D8.2 (A), R60.2
unnamed: D1.3 (L2), J1.A7 (DN1), J1.B7 (DN2)
unnamed: D1.1 (L1), J1.A6 (DP1), J1.B6 (DP2)
unnamed: R65.1, U1.6 (REF)
UART1_RXD: U1.39 (CDBUS1); also elsewhere on the board
UART1_TXD: U1.38 (CDBUS0); also elsewhere on the board
~FLASH_PROG_SEL: U1.30 (BDBUS4); also elsewhere on the board

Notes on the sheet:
USB-C Connector
(MISO)
3.3V Good (green)
Power Indicators
ERROR: wrong part (6.1V clamp); replace with TVS2200 22-volt clamp
USB Power/Debug Port
(MOSI)
Decoupling VCORE/VCCIO
HIGH or Z = run mode; 0 = program mode
VBUS Good (amber)
5V Good (white)
NB: JTAG pulls are on CM.


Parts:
C3, C5: 1nF; C_0805_2012Metric_Pad1.18x1.45mm_HandSolder; MPN CC0805KRX7R9BB102
C4, C6: 100nF; C_0805_2012Metric_Pad1.18x1.45mm_HandSolder; MPN CC0805KRX7R9BB104
C7: 1nF 250V; C_0805_2012Metric_Pad1.18x1.45mm_HandSolder; MPN CL21B102KECSFNC
J5: ICD15S13E4GX00LF; AMPHENOL_ICD15S13E4GX00LF; MPN ICD15S13E4GX00LF
R1, R2, R3, R4, R5, R6, R7, R8, R9, R10, R11, R12, R13, R14: 100k; R_0805_2012Metric_Pad1.15x1.40mm; MPN RC0805FR-07100KL
R15, R16, R17, R18, R20, R21, R22, R23, R24, R25, R26, R27, R28, R29, R34: 536; R_0805_2012Metric_Pad1.15x1.40mm; MPN RC0805FR-07536RL
R19, R32, R33, R35, R36, R37, R38, R39, R40: 270; R_0805_2012Metric_Pad1.15x1.40mm; MPN RC0805FR-07270RL
R30, R31: 100; R_0805_2012Metric_Pad1.15x1.40mm; MPN RC0805FR-07100RL
R41: 1M; R_0805_2012Metric_Pad1.15x1.40mm; MPN RC0805FR-071ML
U6, U7: SN74LVC245APW; TSSOP-20_4.4x6.5mm_P0.65mm

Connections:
+3V3: C3.1, C4.1, C5.1, C6.1, U6.1 (DIR), U6.20 (VCC), U7.1 (DIR), U7.20 (VCC); also elsewhere on the board
/VGA/VGA_CONN_BLUE: J5.3, R20.2, R40.1
/VGA/VGA_CONN_GREEN: J5.2, R24.2, R39.1
/VGA/VGA_CONN_HS: J5.13, R31.2
/VGA/VGA_CONN_RED: J5.1, R15.2, R19.1
/VGA/VGA_CONN_VS: J5.14, R30.1
/VGA/VGA_DAC_BLUE_0: R23.1, U6.11 (B8)
/VGA/VGA_DAC_BLUE_1: R22.1, U6.12 (B7)
/VGA/VGA_DAC_BLUE_2: R21.1, U6.13 (B6)
/VGA/VGA_DAC_BLUE_3: R20.1, U6.14 (B5)
/VGA/VGA_DAC_GREEN_0: R27.1, U7.15 (B4)
/VGA/VGA_DAC_GREEN_1: R26.1, U7.16 (B3)
/VGA/VGA_DAC_GREEN_2: R25.1, U7.17 (B2)
/VGA/VGA_DAC_GREEN_3: R24.1, U7.18 (B1)
/VGA/VGA_DAC_RED_0: R18.1, U6.15 (B4)
/VGA/VGA_DAC_RED_1: R17.1, U6.16 (B3)
/VGA/VGA_DAC_RED_2: R16.1, U6.17 (B2)
/VGA/VGA_DAC_RED_3: R15.1, U6.18 (B1)
/VGA/VGA_HS: R31.1, U7.11 (B8)
/VGA/VGA_VS: R30.2, U7.12 (B7)
GND: C3.2, C4.2, C5.2, C6.2, C7.2, J5.5, J5.6, J5.7, J5.8, J5.10, R1.2, R2.2, R3.2, R4.2, R5.2, R6.2, R7.2, R8.2, R9.2, R10.2, R11.2, R12.2, R13.2, R14.2, R28.2, R29.2, R34.2, R41.2, U6.10 (GND), U6.19 (~OE), U7.6 (A5), U7.7 (A6), U7.10 (GND), U7.19 (~OE); also elsewhere on the board
unnamed: C7.1, J5.S1 (SHIELD), J5.S2 (SHIELD__1), R41.1
unnamed: R16.2, R19.2, R32.1
unnamed: R17.2, R32.2, R33.1
unnamed: R18.2, R33.2, R34.1
unnamed: R21.2, R36.1, R40.2
unnamed: R22.2, R35.1, R36.2
unnamed: R23.2, R28.1, R35.2
unnamed: R25.2, R38.1, R39.2
unnamed: R26.2, R37.1, R38.2
unnamed: R27.2, R29.1, R37.2
VGA_BLUE_0: R8.1, U6.9 (A8); also elsewhere on the board
VGA_BLUE_1: R7.1, U6.8 (A7); also elsewhere on the board
VGA_BLUE_2: R6.1, U6.7 (A6); also elsewhere on the board
VGA_BLUE_3: R5.1, U6.6 (A5); also elsewhere on the board
VGA_GREEN_0: R14.1, U7.5 (A4); also elsewhere on the board
VGA_GREEN_1: R13.1, U7.4 (A3); also elsewhere on the board
VGA_GREEN_2: R12.1, U7.3 (A2); also elsewhere on the board
VGA_GREEN_3: R11.1, U7.2 (A1); also elsewhere on the board
VGA_HSYNC: R9.1, U7.9 (A8); also elsewhere on the board
VGA_RED_0: R4.1, U6.5 (A4); also elsewhere on the board
VGA_RED_1: R3.1, U6.4 (A3); also elsewhere on the board
VGA_RED_2: R2.1, U6.3 (A2); also elsewhere on the board
VGA_RED_3: R1.1, U6.2 (A1); also elsewhere on the board
VGA_VSYNC: R10.1, U7.8 (A7); also elsewhere on the board

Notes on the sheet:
Place close to U6
Place close to U7
VGA

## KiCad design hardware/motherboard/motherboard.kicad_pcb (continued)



Board: 4 copper layers, 152.4 x 76.2 mm, 160 parts (120 on the bottom side), 250 nets.

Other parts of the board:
G3: LOGO; hdmi-400x80-mil
G4: LOGO; usb-logo-100mil

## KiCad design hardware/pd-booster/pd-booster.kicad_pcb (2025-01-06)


Board: 2 copper layers, 11.9 x 24.6 mm, 7 parts (0 on the bottom side), 6 nets, no tracks yet.

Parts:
C1: 0.1uF; C_0805_2012Metric_Pad1.18x1.45mm_HandSolder
J1: 2x4 male 0.1"; PinHeader_2x04_P2.54mm_Vertical
J2: PH1RB-02-UA; PinHeader_2x01_P2.54mm_Vertical
R1: 2mΩ 1% 1W; STA_CSNL1206_STP
R2, R3: 5.1k 1%; R_0805_2012Metric_Pad1.15x1.40mm_HandSolder
U1: INA211BIDCKT; SOT65P210X110-6N

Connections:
/5V_OUT: J1.3, J1.4, R1.2, U1.5 (-IN)
/CC1: J1.6, R2.1
/CC2: J1.8, R3.1
/ISENSE: J2.2, U1.6 (OUT)
/VBUS_IN: C1.1, J1.1, J1.2, R1.1, U1.3 (V+), U1.4 (+IN)
GND: C1.2, J1.5, J1.7, J2.1, R2.2, R3.2, U1.1 (REF), U1.2 (GND)

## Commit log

2024-09-07 constraints for osh park 2-layer
    [psu.kicad_pcb]
2024-09-08 add led calculators
    [power-calcs-scratch.xlsx]
2024-09-08 add script to add properties to .kicad_sym files
2024-09-10 kicad sym editor default supports usual fields
2024-12-16 add pcbway bom
    [cm-rev1-pcbway-bom.xlsx]
2024-12-17 compute module rev 1
    [5v-pwr-mux.kicad_sch, 61301621021_Download_STP_61301621021_rev1.stp, 6130XX11121_61300311121.step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]
2024-12-23 add parts
    [EDI2CAP.CFG, TPS25730DREFR.PcbLib, TPS25730DREFR.SchLib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]
2024-12-23 df40 footprint: remove manual F.Paste rects, add F.Paste to each pad, shrink stencil aperture 15%
2024-12-23 df40 footprint: make pads rounded rects for improved paste release
2024-12-23 script used to add F.Paste layer to all pads in footprint
2024-12-23 df40 adapter board rev 0 - final release to mfgr
    [df40-adapter.kicad_pcb, df40-adapter.kicad_sch, hdmi-board-parts.xlsx]
2025-01-06 motherboard rev 1
    [ASEM1-12.000MHZ-LC-T.step, CONN_PH2-06-UA_ADM.step, DF40C-20DP-0.4V_51_.step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]
2025-01-06 rename null version of current booster to pd-booster-null
    [passthru.kicad_sch, pd-booster-null.kicad_pcb, pd-booster-null.kicad_sch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]
2025-01-06 split out USB-PD 8A version of pd-booster
    [passthru.kicad_sch, pd-booster-8amp.kicad_pcb, pd-booster-8amp.kicad_sch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]
2025-01-06 kicad project renamer script
2025-01-07 note error: wrong TVS clamp used
    [motherboard.kicad_sch, usb.kicad_sch]
2025-01-07 remove old psu project
    [5v-pwr-mux.kicad_sch, dc-barrel-efuse.kicad_sch, dc-barrel.kicad_sch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]
2025-01-10 complete: pd-booster-16amps rev 1 + pd-booster-null
    [16SVPF560M.step, 25SVPF330M.step, CSD16327Q3.step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]
2025-01-11 motherboard: add dimensions, add note to expand ffc
    [connectors.kicad_sch, motherboard.kicad_pcb]
2025-01-11 calcs for TPS25947 eFuse for future power supply
    [TPS25947xx_Design_Calculator.xlsm]
2025-01-11 fix bug that was processing .kicad_sch file twice
2025-01-15 hat v1
    [MSD-4-A.step, PPPC201LFBN-RC.STEP, PPTC062LFBN-RC.STEP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]
2025-01-15 add hat v1 notes
    [hdmi-board-parts.xlsx]
2025-01-15 hat: move sdcard to edge
    [hat.kicad_pcb]
2025-01-15 hat rev 1 shortened pcb - release to manufacturing
    [hat.kicad_pcb]
2025-01-15 hat: revert to full size pcb, rev 1 final (7fcdf54b)
    [hat.kicad_pcb]
2025-01-26 (no changes)
    [TPS25947xx_Design_Calculator.xlsm, hdmi-board-parts.xlsx]
2025-01-31 reduce stencil aperture shrink to max 2.5%
    [df40-adapter.kicad_pcb, df40-spacer.kicad_pcb, hat.kicad_pcb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]
2025-02-02 generate pd-16amps bom
2025-02-02 additional parts purchase
    [hdmi-board-parts.xlsx]
2025-02-02 bom excel sheet spacing
    [pd-booster-16amps-export.csv]
2025-02-02 recenter pcb for printing
    [pd-booster-16amps.kicad_pcb]
2025-02-07 reflect addl order of forgotten motherboard parts
    [hdmi-board-parts.xlsx]
2025-02-07 correct some bom designators
    [hdmi-board-parts.xlsx]

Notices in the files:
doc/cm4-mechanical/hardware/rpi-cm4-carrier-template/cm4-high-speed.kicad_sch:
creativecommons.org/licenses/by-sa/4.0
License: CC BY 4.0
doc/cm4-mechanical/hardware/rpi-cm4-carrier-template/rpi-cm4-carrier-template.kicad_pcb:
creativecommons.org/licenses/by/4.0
